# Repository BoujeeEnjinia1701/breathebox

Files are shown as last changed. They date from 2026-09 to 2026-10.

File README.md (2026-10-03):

# BreatheBox

     

**Area:** BioMedical · **TRL:** 3 of 9 (proof of concept on paper) · **Value-engineering target:** $255 USD · **Difficulty:** 3 of 5

A window-mounted heat recovery ventilator for single rooms: two small fans and a counterflow core bring in fresh air while recovering most of the heat or cool from the outgoing air.

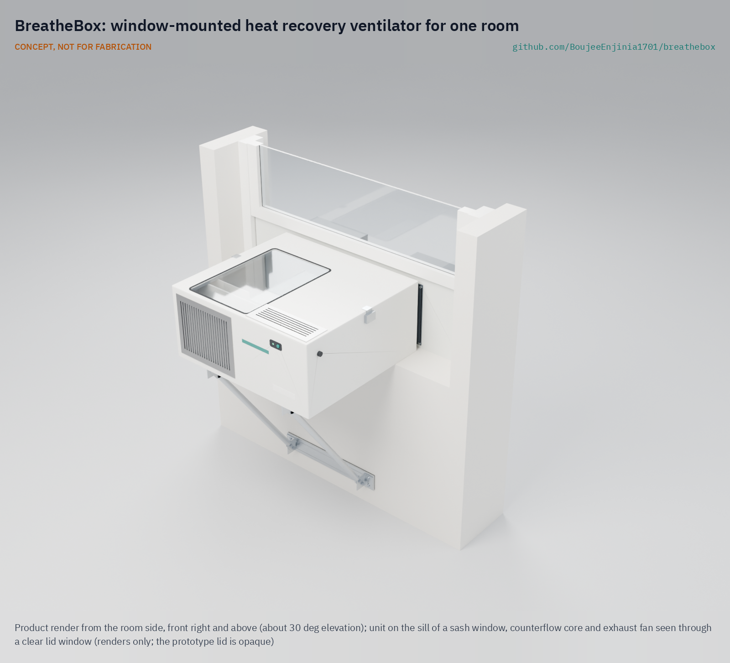
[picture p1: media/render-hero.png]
BreatheBox: window-mounted heat recovery ventilator for one room, product render


[Exploded render](media/render-exploded.png) · [Detail render](media/render-detail.png) · [Interactive 3D model](media/viewer.html) · [Concept blueprint (PDF)](media/concept-blueprint.pdf) · [General arrangement BBX-DWG-001 (PDF)](cad/drawings/BBX-DWG-001.pdf) · [Sizing calculations](docs/04-calcs/01-sizing.md) · [Prototype build plan](docs/05-build-plan.md) · [Design decisions](docs/06-design-decisions.md) · [Review note](docs/REVIEW.md)

## Concept rationale

Most homes will never get a ducted whole-house ventilation system, but almost every room has a window. BreatheBox puts heat recovery where the fresh air already comes in: a small counterflow core and two small 24 V fans in a box that sits on the sill, with an insulated panel under the raised sash. Room air and outdoor air pass each other on opposite sides of thin plates, so the room gets filtered fresh air at close to room temperature instead of a cold draft. A CO2 sensor runs the fans only as hard as the room needs.

It is open and garage-buildable because the people who most need it (renters, social housing tenants, owners of older homes) are the least served by installer-only products. Apart from the core and the fans, the parts are foam board, filter media and a small controller. The design files let a community repair group or a housing provider build, adapt and fix units locally, and the firmware keeps data on the device. It is a research and educational prototype, not a medical device.

## Burning platform

People live indoors, and indoor air is often the worse air. The US EPA notes that Americans spend about 90 % of their time indoors and that indoor concentrations of some pollutants are often 2 to 5 times higher than typical outdoor levels ([US EPA](https://www.epa.gov/report-environment/indoor-air-quality)). Opening a window is the usual fix, and it throws heat away: in the European Union, buildings use about 40 % of energy, about 80 % of energy in homes goes to heating, cooling and hot water, and 85 % of buildings were built before 2000 ([European Commission](https://energy.ec.europa.eu/topics/energy-efficiency/energy-performance-buildings/energy-performance-buildings-directive_en)).

The cost of getting this wrong is not only energy. In England, 7 % of social rented homes had a damp problem in 2023, and the death of two-year-old Awaab Ishak from prolonged mould exposure led to a law with fixed deadlines for landlords to fix damp and mould ([UK Government](https://www.gov.uk/government/news/awaabs-law-to-force-landlords-to-fix-dangerous-homes)). Outdoor air needs filtering too: 99 % of the world's population lived where WHO air quality guideline levels were not met in 2019 ([WHO](https://www.who.int/news-room/fact-sheets/detail/ambient-(outdoor)-air-quality-and-health)).

## Where it could be used

### By industry

| Industry | Use |
| --- | --- |
| Social and rental housing | Fast, reversible fix for damp and stuffy bedrooms without building work |
| Home energy retrofit | Adds controlled ventilation after air sealing and insulation of older homes |
| Student and worker residences | One unit per small room, where windows are often kept shut for noise or security |
| Small offices and consulting rooms | Fresh, filtered air for one or two people in rooms with no mechanical ventilation |
| Assisted living and home care | Steady ventilation for people who cannot easily open and close windows |
| Maker education and repair cafes | Teaching build of airflow, heat transfer and sensing with a useful result |

### By country or region

| Country or region | Why it matters there |
| --- | --- |
| Canada | Long, cold heating seasons; Health Canada sets a 1,000 ppm long-term CO2 guideline for homes and names ventilation as the main way to remove CO2 ([Health Canada](https://www.canada.ca/en/health-canada/services/publications/healthy-living/residential-indoor-air-quality-guidelines-carbon-dioxide.html)) |
| United States | Window air conditioners have made sash-window units a familiar renter fix; Americans spend about 90 % of their time indoors ([US EPA](https://www.epa.gov/report-environment/indoor-air-quality)) |
| United Kingdom | Damp and mould in 7 % of social rented homes and new legal deadlines for landlords to fix them ([UK Government](https://www.gov.uk/government/news/awaabs-law-to-force-landlords-to-fix-dangerous-homes)) |
| Germany and the wider EU | 85 % of buildings built before 2000 and 75 % with poor energy performance ([European Commission](https://energy.ec.europa.eu/topics/energy-efficiency/energy-performance-buildings/energy-performance-buildings-directive_en)); tilt-and-turn windows need a different insert |
| India | Filtered supply air for bedrooms kept shut against outdoor pollution; the WHO South-East Asia Region has among the greatest numbers of deaths from ambient air pollution ([WHO](https://www.who.int/news-room/fact-sheets/detail/ambient-(outdoor)-air-quality-and-health)); an enthalpy core would suit humid heat |
| China | Cold northern winters and polluted outdoor air in one place; the WHO Western Pacific Region also carries among the greatest numbers of those deaths ([WHO](https://www.who.int/news-room/fact-sheets/detail/ambient-(outdoor)-air-quality-and-health)) |

## What sparked the idea

The idea traces back to the Saskatchewan Conservation House, an experimental energy-efficient home built in northwest Regina in 1977 with the Saskatchewan Research Council as project manager. Its use of an air-to-air heat exchanger for ventilation was a pioneering effort, and such exchangers are now produced in the tens of thousands each year in North America ([Encyclopedia of Saskatchewan, University of Regina](https://esask.uregina.ca/entry/energy-efficient_houses.html)). That house showed that a tight, well-insulated home needs heat recovery ventilation designed in from the start. BreatheBox asks what the same exchanger looks like when it has to reach an existing room through a sash window, fitted and removed by a tenant, rather than being ducted into a new house.

## Problem

Sealed, efficient homes need ventilation, but opening windows wastes energy and whole-house heat recovery systems are expensive to retrofit.

## Concept

A window-mounted heat recovery ventilator for single rooms: two small fans and a counterflow core bring in fresh air while recovering most of the heat or cool from the outgoing air.

Full design precis: [docs/02-concept.md](docs/02-concept.md)

## Key components

1. Insulated housing that sits on the window sill
2. Counterflow plate core, about 80 % sensible recovery (estimate)
3. Two 24 V brushless blowers, 30 to 70 m³/h balanced, 50 m³/h nominal
4. ePM1 supply filter and coarse exhaust filter
5. Controller with CO2, humidity and temperature sensing, a frost mode and a quiet night mode
6. Condensate tray draining outdoors
7. Insulated window insert panel with seals, under the raised sash, which a bought no-drill sash jammer holds down
8. Two outdoor hoods with insect mesh, a sill bracket propped on the wall by a padded foot, and a certified 24 V plug-in adapter

TRL 3 calculations ([BBX-CAL-001](docs/04-calcs/01-sizing.md)): about 267 W of heat kept at 0 °C outdoors and 50 m³/h for about 5.7 W of fan and control power, about 11.8 kg installed, and $294 in parts. One requirement is not met, noise (about 39 dB(A) at 1 m at 50 m³/h against 30 dB(A)). Value-engineering target: USD 255. Estimated cost of the constructable design: USD 294 (USD 39 over the target). A quiet night mode at 32 m³/h brings the noise estimate to about 30 dB(A) with clean filters, with overnight CO2 near 1,300 ppm ([BBX-DDR-002](docs/decisions/0002-recommendations-accepted.md)). See the [design precis](docs/02-concept.md) and [requirements](docs/03-requirements.md).

The priced bill of materials is in [bom/bom.csv](bom/bom.csv). The parametric model is `cad/src/model.py`, with STEP and STL exports in `cad/step/` and `cad/stl/`.

## Building the prototype

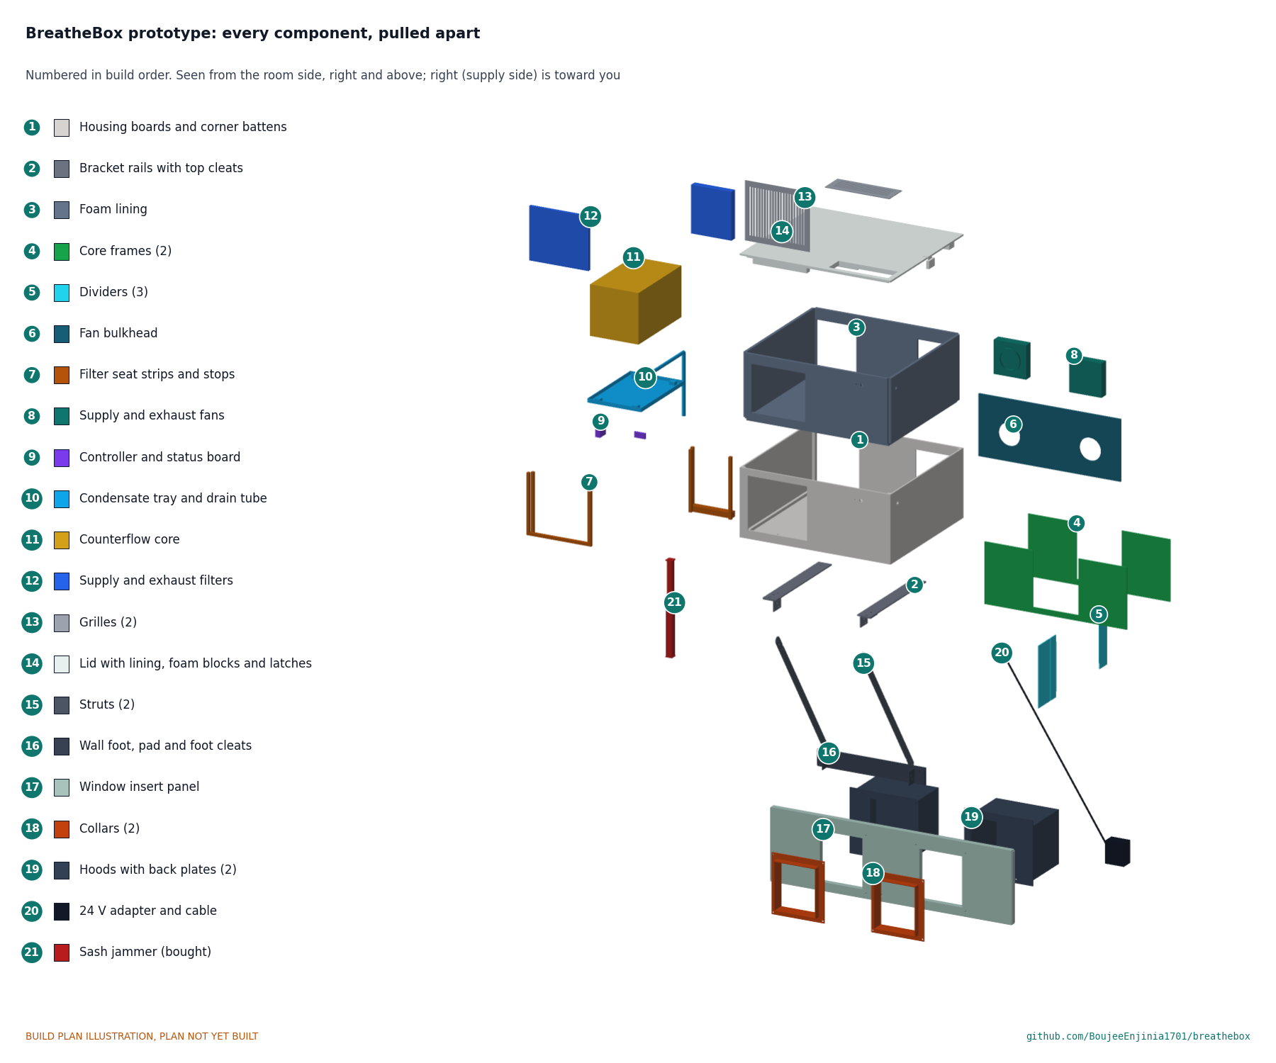
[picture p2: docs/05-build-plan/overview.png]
BreatheBox prototype: every component pulled apart and numbered in build order


The [prototype build plan](docs/05-build-plan.md) (BBX-BLD-001) shows, in pictures, how to make or buy each of the twenty-one components and put them together in sixteen steps; nothing has been built yet. The housing is PVC foam board on corner battens with a foam lining, partitions that keep the four air streams apart and a fan bulkhead; the window insert is a panel with flanged collars and hoods bolted through it; the bracket is two rails and two flattened-end struts on a padded wall foot 400 mm above the floor, and a bought sash jammer holds the raised sash down on the insert. Writing the plan made the design buildable: joints, seats, partitions, grilles and fixings were added and the bracket was made rigid (BBX-DDR-003, accepted by Amish on 2 October 2026); the decisions are recorded in the [design decisions register](docs/06-design-decisions.md). Every picture is drawn from the model, which checks that each part touches what it should and clears what it should not.

## Safety

> The unit runs on 24 V from a certified plug-in adapter; do not open the adapter or add mains wiring. Do not use it in a room with an open-flued or unflued fuel-burning appliance, because frost mode extracts more air than it supplies. Hold the raised sash down on the insert panel with the sash jammer and never install from outside above ground level. Fan impellers can cut fingers: unplug before opening the lid.
>
> BreatheBox is a research and educational prototype, not a medical device. Its CO2 reading indicates how well the room is ventilated; it is not a health or medical measurement.

## Repository layout

| Folder | Contents |
| --- | --- |
| `docs/` | Problem, concept, requirements, calculations and design decisions |
| `cad/src/` | build123d Python source, the source of truth for all geometry |
| `cad/step/`, `cad/stl/` | Exported models for FreeCAD, other CAD tools and printing |
| `cad/drawings/` | 2D sketches and dimensioned drawings |
| `bom/` | Bill of materials |
| `electronics/` | KiCad schematics and PCB layouts |
| `firmware/` | Microcontroller code |
| `media/` | Renders, perspectives and photos |
| `build-log/` | Dated prototyping notes |

## Documentation

Controlled documents follow the portfolio [documentation standard](.kit/STANDARDS.md). Each carries a document ID (BBX-PRC-001 for the precis), a version and a revision history. Branded PDFs are built with `python .kit/render.py` and attached to GitHub Releases when a document is tagged, for example `BBX-PRC-001/v1.0`.

## Credits

Designed by Amish Chadha, with contributions from Ashok Kumar Chadha and Dr. Geeti Chadha. See [CONTRIBUTORS.md](CONTRIBUTORS.md) for roles. To cite this design, use [CITATION.cff](CITATION.cff) (GitHub shows it as "Cite this repository").

AI assistance (Claude) was used to accelerate concept renders, prototype documentation and first-pass sizing calculations. Design direction and all decisions are Amish Chadha's, recorded in this repository's decision records (`docs/decisions/`).

## Licenses

- **Hardware** (CAD, drawings, BOM, electronics): [CERN-OHL-S v2](LICENSE)
- **Software** (firmware, scripts, notebooks): [MIT](LICENSE-SOFTWARE)

A project of the [Design Molecule](https://designmolecule.com) lab.

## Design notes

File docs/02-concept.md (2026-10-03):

---
doc_id: BBX-PRC-001
title: BreatheBox design precis
project: BreatheBox
doc_type: Design precis
version: "0.10"
status: Draft
date: '2026-10-02'
author: Amish Chadha
license: CERN-OHL-S-2.0
revisions:
- version: "0.1"
  date: '2026-09-25'
  author: Amish Chadha
  change: Initial scaffold
- version: "0.2"
  date: '2026-09-25'
  author: Amish Chadha
  change: Populate to TRL 2 (architecture, first-order numbers, safety, media)
- version: "0.3"
  date: '2026-09-25'
  author: Amish Chadha
  change: TRL 3 update; numbers from BBX-CAL-001, layout from the parametric model and BBX-DWG-001, larger fans, design choices adopted for TRL 3 per BBX-DDR-001 (open for Amish's review)
- version: "0.4"
  date: '2026-09-25'
  author: Amish Chadha
  change: Recommendations accepted by Amish (DDR-002)
- version: "0.5"
  date: '2026-09-26'
  author: Amish Chadha
  change: Budget approved by Amish; parts cost now within the $255 budget
- version: "0.6"
  date: '2026-09-30'
  author: Amish Chadha
  change: Design made constructable (BBX-DDR-003, open for Amish's review); components, mass, power and cost updated; build plan BBX-BLD-001 and register BBX-DEC-001 added
- version: "0.7"
  date: '2026-10-01'
  author: Amish Chadha
  change: Budget treated as a value-engineering target
- version: "0.8"
  date: '2026-10-01'
  author: Amish Chadha
  change: BioMedical area (BBX-DEC-001 v0.3); safety states a research and educational prototype, not a medical device
- version: "0.9"
  date: '2026-10-02'
  author: Amish Chadha
  change: "Fan position and sash jammer decided by Amish on 2026-10-02 (BBX-DEC-001)"
- version: "0.10"
  date: '2026-10-02'
  author: Amish Chadha
  change: "Approved follow-ups carried out: wall foot at 400 mm, sash jammer as component 14, mass 11.8 kg installed, cost USD 294 (USD 39 over the value-engineering target); drawing BBX-DWG-001 Rev P4"
---

# BreatheBox design precis

## Summary

BreatheBox is a single-room heat recovery ventilator that sits on the sill of a sash window. Two small 24 V blowers push stale room air out and draw fresh air in through a counterflow plate core, so the incoming air picks up about 80 % of the heat (or, in summer, the cool) of the outgoing air. The TRL 3 calculations (BBX-CAL-001) give, for a bedroom at 50 m³/h and 0 °C outdoors: about 267 W of heat kept in the room for about 5.7 W of fan and control power, supply air at about 16 °C, and CO2 near 980 ppm overnight with two sleepers. One requirement is not met, noise (about 39 dB(A) at 1 m at 50 m³/h against 30 dB(A)), and cost is over the value-engineering target. Value-engineering target: USD 255. Estimated cost of the constructable design: USD 294 (USD 39 over the target). A quiet night mode at 32 m³/h brings the noise estimate to about 30 dB(A) with clean filters. All figures are paper estimates; nothing has been built.

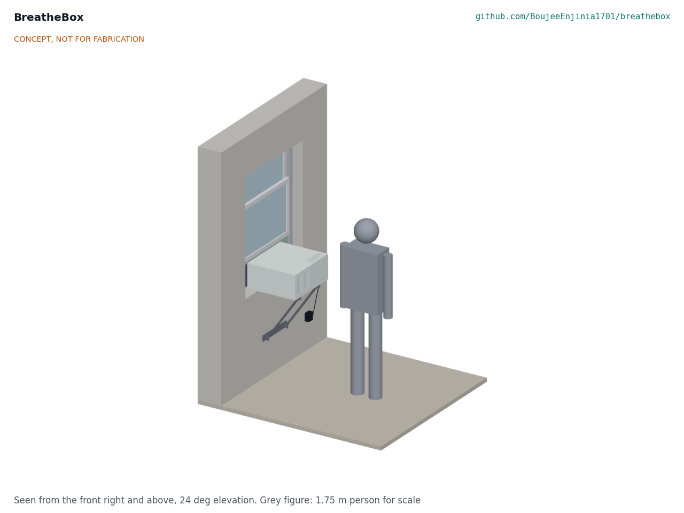
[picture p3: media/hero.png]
Hero render


Figure 1. Parametric model on a sash window, with a 1.75 m person for scale.

## How it works

1. **Mount.** A 20 mm insulated panel fills the gap under the raised lower sash, which closes down onto it and is held there by a bought no-drill sash jammer in the inner track above it. The housing (510 x 560 x 250 mm) rests 110 mm on the sill and projects 400 mm into the room, where a bracket of two rails and two struts, propped on the wall by a padded foot 400 mm above the floor, carries it; nothing is drilled.
2. **Exhaust path.** Room air enters a front grille, passes a coarse filter, and the exhaust fan blows it through one set of core channels, across the outdoor plenum and out of a downward-facing hood.
3. **Supply path.** Outdoor air enters the second hood, 420 mm from the exhaust mouth, passes through a collar in the panel and an ePM1 filter, and flows through the other set of core channels. The supply fan draws it through the core and blows it into the room through a top grille that throws air up and away from the occupant.
4. **Recover.** The two streams flow in opposite directions on each side of thin polymer plates, so heat passes across without the air mixing.
5. **Drain.** In winter, moisture from the room air condenses in the core. A tray under the core falls to the outdoor side, and a tube carries the water through the panel and down the outside wall.
6. **Control.** A small controller reads CO2, humidity and temperature at the room intake and runs the fans between 30 and 70 m³/h, using the fan tach signals to keep the two streams within 10 %. A temperature probe at the core's exhaust outlet triggers a frost mode that slows the supply fan when the cold corner of the core nears 0 °C. Readings show on a status LED and, optionally, on a local web page; nothing needs the cloud. The firmware rules accepted in BBX-DDR-002 are: a quiet night mode that holds both streams at 32 m³/h and suppresses the CO2 boost; a speed cap at what 80 m³/h needs, so the worst-case draw stays under the 36 W adapter; and frost mode taking priority over both.

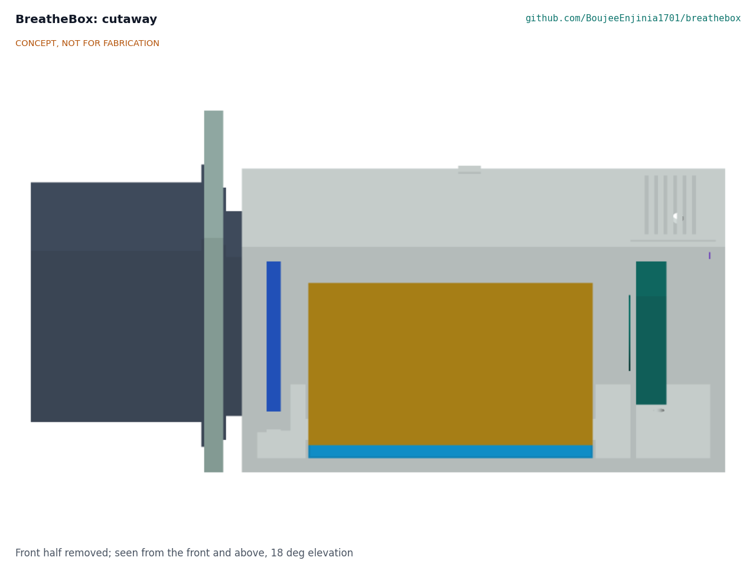
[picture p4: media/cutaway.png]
Cutaway


Figure 2. Cutaway through the supply side: hood and collar (outdoors, left), insert panel, supply filter, core over the condensate tray, supply fan and controller.

The general arrangement is drawing BBX-DWG-001 (Rev P4) in `cad/drawings/`, generated from `cad/src/model.py`. How to build the prototype, component by component, is in the build plan BBX-BLD-001 (`docs/05-build-plan.md`); BBX-DDR-003 records the changes that made the concept buildable, and the design decisions register BBX-DEC-001 (`docs/06-design-decisions.md`) records the decisions made and the items to confirm when parts are bought.

## Main components

Table 1. Main components. Numbers match `bom/bom.csv` and Figure 4.

| # | Component | Choice for TRL 3 | Notes |
| --- | --- | --- | --- |
| 1 | Insulated housing | 6 mm PVC foam board on corner battens with 10 mm foam lining, 510 x 560 x 250 mm; core frames, dividers and a fan bulkhead for the four air paths; filter seats; two slotted grilles | Lift-off lid with two latches |
| 2 | Counterflow core | Polymer plate core 180 x 180 x 300 mm, about 2.5 mm plate pitch | Bought spare-part HRV core; washable |
| 3, 4 | Supply and exhaust fans | 24 V brushless centrifugal blowers, 120 x 120 x 32 mm class, about 100 m³/h free air and 400 Pa shut-off, PWM with tach | Larger than at TRL 2 (see BBX-CAL-001 section 4) |
| 5 | Supply filter | ISO 16890 ePM1 50 % pleated panel, 150 x 170 x 25 mm, at the supply port | Replace about every 6 months or at twice the clean pressure drop |
| 6 | Exhaust filter | Coarse washable pad, 220 x 190 mm | Keeps lint off the core |
| 7 | Controller | ESP32-C3 class module with a Sensirion SCD41 class CO2, humidity and temperature sensor and two NTC probes | Check the sensor on the lab's CalRig before use |
| 8 | Condensate tray and drain | PETG tray under the core, 12 x 8 mm tube to outdoors from the tray floor | Tube falls outdoors |
| 9 | Window insert panel | 20 mm insulated panel with EPDM edge seals, trimmed to 700 to 1,000 mm | Raised sash held down on it by a bought no-drill sash jammer in the inner track (decided 2026-10-02) |
| 10 | Outdoor hoods and collars | Two PVC hoods on back plates with 1 mm stainless mesh on 130 mm wide mouths, 420 mm apart; flanged collars bolted through the panel | Mouths face down |
| 11 | Sill bracket | Two aluminium rails under the housing and two tube struts, bolted rigid, to a padded wall foot 400 mm above the floor | Props on the wall; no drilling |
| 12 | Power supply | Certified 24 V, 1.5 A plug-in adapter; 2 A fuse on the 24 V input | No mains wiring in the unit |
| 14 | Sash jammer | Bought no-drill adjustable sash jammer, wedged in the inner track between the raised sash and the window head | Holds the sash down on the panel (R12) |

## Key numbers

All values come from BBX-CAL-001 and `docs/04-calcs/sizing.py`, with the assumptions stated there. They are estimates for a paper design.

Table 2. Key numbers at TRL 3.

| Quantity | Estimate | Requirement |
| --- | --- | --- |
| Core effectiveness | 79.8 % at 50 m³/h; 73.8 % at 70 m³/h | R2 met on paper |
| Heat recovered at 0 °C outdoors, 50 m³/h | 267 W of 335 W; 68 W lost; supply air 16.0 °C | |
| Supply pressure drop at 50 m³/h | 52.3 Pa clean, 79.6 Pa with loaded filter | |
| Flow limit at full fan speed | 80 m³/h per stream with loaded filters | R1 met on paper |
| Fan and control power | 5.7 W at 50 m³/h (7.5 W loaded); 14.8 W at 70 m³/h loaded | R3 met on paper |
| Noise at 1 m | About 39 dB(A) at 50 m³/h; night mode at 32 m³/h about 30 dB(A) clean, 32 dB(A) with loaded filters | **R6 not met** (written for 50 m³/h) |
| Heating-season energy kept | About 1,123 kWh for 29 kWh of fan energy (3,500 K·d) | |
| CO2, two sleepers, 30 m³ room | 980 ppm overnight and 607 ppm 24 h mean at 50 m³/h; about 1,300 ppm overnight and 712 ppm 24 h mean in night mode | R4 met on paper |
| Condensate, upper bound | 0.21 L/h (70 m³/h, -3 °C) | R7 drain sized |
| Frost onset | About -2.2 °C outdoors at 50 m³/h | |
| Frost mode at -10 °C | Supply slowed to 33 % of exhaust; about 2.2 Pa room depressurization through a door undercut | R7 met on paper |
| Clear distance between hood mouths | 420 mm; hoods fit windows from 686 mm clear width | R11, R8 met on paper |
| Unit mass | About 11.8 kg installed, sash jammer included (12.0 kg with adapter) | R9 mass met on paper (margin 0.2 kg) |
| Parts cost | $294 | **R15 over the value-engineering target by $39** ($255 target) |

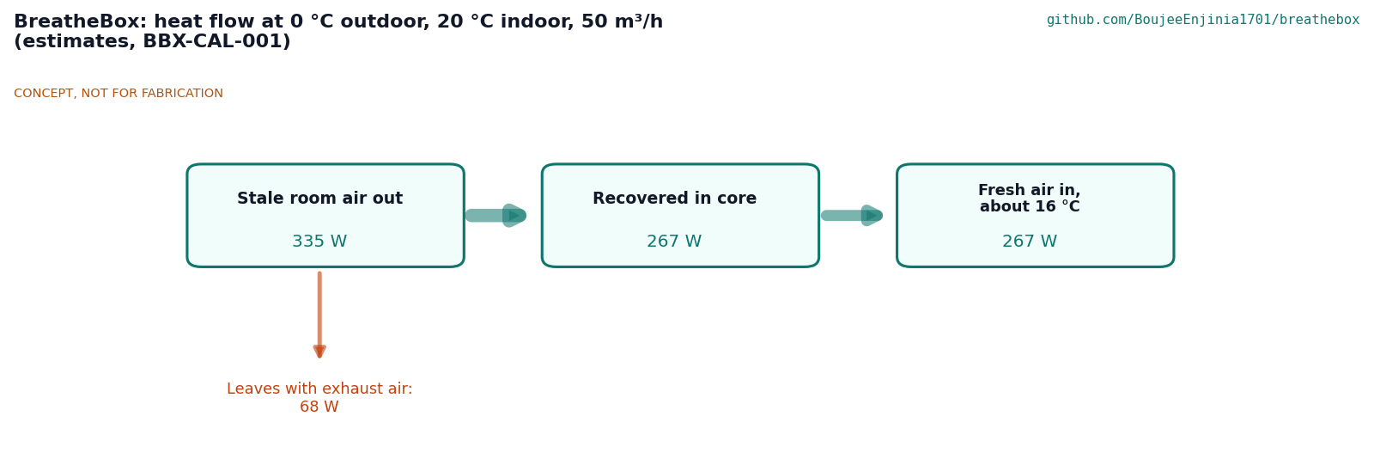
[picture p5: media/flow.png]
Heat flow


Figure 3. Heat flow in the design case (estimates from BBX-CAL-001).

## Key design choices

Each choice below was recommended at TRL 2 (BBX-DDR-001) and decided by Amish on 2026-09-25: go with recommendation (BBX-DDR-002).

- **Window insert rather than wall core; sash windows first** (item A2). Renters can install it, and it comes out without a trace. The first version fits vertical sliding sash windows from 700 to 1,000 mm clear width, with an adapter for horizontal sliders. Casement and tilt-and-turn windows need a later insert.
- **Bought polymer counterflow plate core** (item A3). A plate core runs one steady fan per stream, is simple to model and build, and keeps supply and exhaust separate. The core is the part a garage builder cannot make well; a home-made crossflow core would cost about $10 but recover only about 50 to 65 % (estimate). Alternating regenerative units and enthalpy cores remain options for later variants.
- **Frost by slowing the supply fan** (item A4). The simplest frost strategy for a 24 V unit: holding balanced flow at -10 °C with a preheater would take about 130 W. It unbalances the flows and slightly depressurizes the room (see Safety).
- **50 m³/h nominal with CO2-driven boost to 70 m³/h** (item A5). The boost is rarely needed for R4 but costs noise (about 45 dB(A) at 70 m³/h with clean filters).
- **Single ESP32-C3 class controller with an SCD41 class sensor** (item A6), with the sensor checked on CalRig.
- **Quiet night mode** (BBX-DDR-002). 32 m³/h per stream while people sleep, trading overnight CO2 (about 1,300 ppm) for about 30 dB(A). Larger, slower fans or a lined silencer section are to be checked against a real fan datasheet before R6 is changed; that check is on hold with TRL 4.
- **Larger blowers, 2 A time-delay input fuse and firmware speed cap** (BBX-DDR-002), as costed and sized in BBX-CAL-001.
- **24 V SELV only.** A certified plug-in adapter means no mains wiring for the builder (R10).

Both fans sit in the warm room-end plenum, so the exhaust side of the core runs at a slightly higher pressure than the supply side, and any core leakage would carry stale air into the supply stream. Amish decided on 2026-10-02 to keep both fans at the room end for the prototype and to add a cross-leakage check at TRL 4: a CO2 tracer in the exhaust stream, measured in the supply. The exhaust fan moves to the outdoor end only if the transfer exceeds about 3 % (BBX-DEC-001).

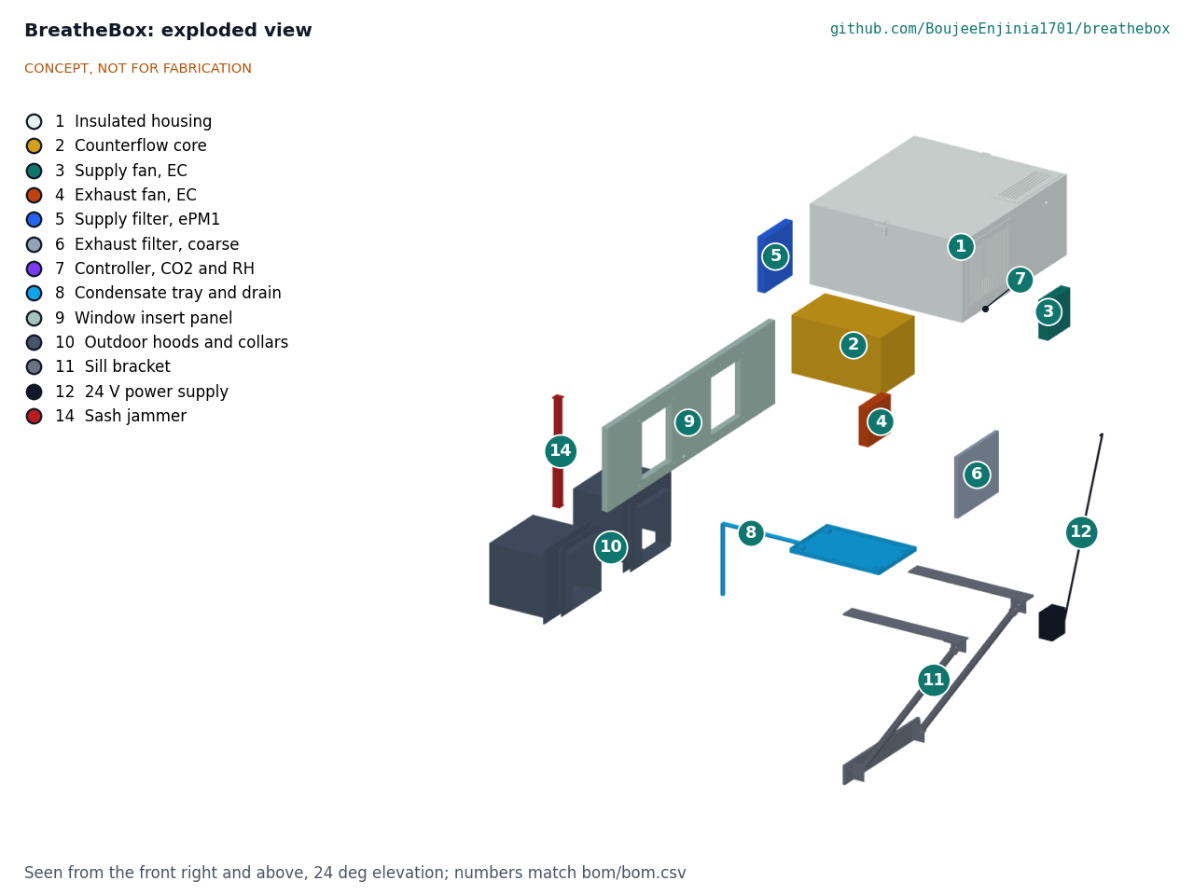
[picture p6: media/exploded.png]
Exploded view


Figure 4. Exploded view with BOM numbers.

## Safety

> **Safety:** Do not use BreatheBox in a room with an open-flued or unflued fuel-burning appliance (gas fire, oil or wood stove, water heater). In frost mode the unit extracts more air than it supplies and could draw combustion gases into the room. Do not install it in a room whose door seals airtight, because the depressurization would then be much larger than the 2 to 4 Pa estimated for a door with an undercut.

> **Safety:** The raised sash must be held down on the insert panel by the sash jammer. An unlocked sash is a security risk, and a loose panel or hood could fall outward from an upper floor. Check the bracket and panel before leaving the unit unattended, and never install from outside above ground level.

> **Safety:** Use only a certified 24 V SELV plug-in adapter, with a 2 A time-delay fuse on the low-voltage input. Do not open or modify the adapter. Keep the cable clear of the sash and of the condensate tube.

- Foam and plastics in the housing burn; choose fire-retardant grades and keep the unit away from heaters and curtains near heat sources.
- Fan impellers can cut fingers: guards or grilles on both room openings, and disconnect power before opening the lid.
- The drain tube can freeze outdoors in long cold spells; route it to fall continuously and check it in winter.
- Clean the tray and replace filters on schedule; standing water and wet filters can grow mould.
- BreatheBox is a research and educational prototype, not a medical device. The CO2 reading is a ventilation indicator only and is not a health or medical measurement.

## Open questions after TRL 3

- Noise: does a real fan datasheet, or a lined silencer, close the R6 gap at 50 m³/h, or should R6 be restated for the night mode?
- Core: which spare-part cores are available at this size, and what are their real effectiveness and pressure drop?
- Fans: the chosen blower's curve, efficiency and noise data, to replace the class values in BBX-CAL-001.
- Airtightness: how much air leaks around the insert panel and sash, and does it matter for balance?
- Window survey: what share of the first users' windows are sash, slider, casement or tilt-and-turn?

Concept media: [blueprint sheet](../media/concept-blueprint.pdf), [interactive 3D model](../media/viewer.html). General arrangement: [BBX-DWG-001](../cad/drawings/BBX-DWG-001.pdf).

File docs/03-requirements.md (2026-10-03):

---
doc_id: BBX-REQ-001
title: BreatheBox requirements
project: BreatheBox
doc_type: Requirements
version: "0.9"
status: Draft
date: '2026-10-02'
author: Amish Chadha
license: CERN-OHL-S-2.0
revisions:
- version: "0.1"
  date: '2026-09-25'
  author: Amish Chadha
  change: Initial scaffold
- version: "0.2"
  date: '2026-09-25'
  author: Amish Chadha
  change: First measurable requirements for TRL 2, with status against the concept
- version: "0.3"
  date: '2026-09-25'
  author: Amish Chadha
  change: Status against BBX-CAL-001 at TRL 3; R7 condensate figure corrected to 0.21 L/h; R8 and R15 notes per BBX-DDR-001 (adopted for TRL 3, open for Amish's review)
- version: "0.4"
  date: '2026-09-25'
  author: Amish Chadha
  change: Recommendations accepted by Amish (DDR-002)
- version: "0.5"
  date: '2026-09-26'
  author: Amish Chadha
  change: Budget approved by Amish; R15 target $255, status Not met to Met
- version: "0.6"
  date: '2026-09-30'
  author: Amish Chadha
  change: Status against the constructable design (BBX-DDR-003, BBX-CAL-001 v0.4); R15 Met to Not met at $283; R3, R9 and R10 figures updated; no target changed
- version: "0.7"
  date: '2026-10-01'
  author: Amish Chadha
  change: Budget treated as a value-engineering target
- version: "0.8"
  date: '2026-10-02'
  author: Amish Chadha
  change: "R12: sash held by a bought no-drill sash jammer, decided by Amish on 2026-10-02 (BBX-DEC-001)"
- version: "0.9"
  date: '2026-10-02'
  author: Amish Chadha
  change: "Approved follow-ups carried out (BBX-CAL-001 v0.7): sash jammer now BOM line 14 (R12); R9 mass 11.8 kg with the longer struts and the sash jammer; R15 USD 294, USD 39 over the value-engineering target; no status category and no target changed"
---

# BreatheBox requirements

These requirements are proposals for review, not yet validated with users, and will be revised after co-design (see BBX-PRB-001). Status is judged against the TRL 3 calculations in BBX-CAL-001 and the parametric model in `cad/src/model.py`; nothing has been built or measured. No target was relaxed at TRL 3. On 2026-09-25 Amish accepted the review recommendations (BBX-DDR-002): R15 read against a $250 value-engineering target (it was $220), and R4 and R6 show the quiet night mode; R6 itself is unchanged until a real fan datasheet has been checked. The R7 condensate figure was corrected from 0.15 to 0.21 L/h because the calculation showed a higher worst case. The value-engineering target was set at $255 on 2026-09-26, and the concept's priced BOM was within it. On 2026-09-30 the design was made constructable (BBX-DDR-003): the parts it needed brought the BOM to $283. On 2026-10-02 Amish's decisions added a bought sash jammer and a lower wall foot with longer struts. Value-engineering target: USD 255. Estimated cost of the constructable design: USD 294 (USD 39 over the target); BBX-DEC-001 lists the savings worth trying. No target changed.

The **design case** is a 30 m³ bedroom with two sleeping adults, 20 °C and 50 % relative humidity indoors, 0 °C outdoors, and a vertical sliding sash window with a 900 mm clear width.

Table 1. Requirements and status at TRL 3.

| ID | Requirement | Target | Status at TRL 3 (BBX-CAL-001) | Verification (TRL 4 or later) |
| --- | --- | --- | --- | --- |
| R1 | Balanced ventilation over a useful range | Supply and exhaust each adjustable from 30 to 70 m³/h (18 to 41 cfm); supply and exhaust within 10 % of each other outside frost mode | Met on paper: 80 m³/h per stream at full speed with loaded filters; balance by fan tach | Flow hood measurement |
| R2 | Recover heat from the exhaust air | Sensible effectiveness 75 % or more at 50 m³/h and balanced flow | Met on paper: 79.8 % | Temperatures on the four ports |
| R3 | Low running power | Fans and controls 12 W or less at 50 m³/h | Met on paper: 5.7 W clean, 7.5 W with loaded filters | Power meter |
| R4 | Keep bedroom air fresh | CO2 at or below 1,000 ppm (24-hour average) in the design case, following the Health Canada residential guideline | Met on paper: 607 ppm 24 h mean at 50 m³/h; 980 ppm overnight. In night mode (32 m³/h): 712 ppm 24 h mean, about 1,300 ppm overnight | CO2 logging |
| R5 | Filter the supply air | ISO 16890 ePM1 50 % or better on supply; coarse filter on exhaust to protect the core | Met by specification | Filter data sheet |
| R6 | Quiet at night | 30 dB(A) or less at 1 m from the room face at 50 m³/h | **Not met** at 50 m³/h: about 39 dB(A) (estimate). Night mode at 32 m³/h (BBX-DDR-002): about 30 dB(A) clean, 32 dB(A) with loaded filters | Sound meter |
| R7 | Handle condensate and frost | All condensate drains outdoors (up to about 0.21 L/h); runs without core blockage down to -10 °C outdoor, using a frost mode that may reduce supply flow | Met on paper: frost onset about -2.2 °C; at -10 °C the supply runs at 33 % of the exhaust | Cold-chamber or winter test |
| R8 | Fit common windows | Vertical sliding sash windows with 700 to 1,000 mm clear width and sill 150 mm or deeper; adapter panel for horizontal sliders | Met on paper for sash: the hoods need 686 mm. Casement and tilt-and-turn windows are a later variant (BBX-DDR-001 item A2, decided by Amish in BBX-DDR-002) | Fit check against a window survey |
| R9 | Renter-friendly installation | No drilling of frame or wall; one person installs or removes in 30 min or less; unit mass 12 kg or less | Not verifiable at TRL 3: mass 11.8 kg met on paper (sash jammer included; margin 0.2 kg); install time needs a trial | Timed trials |
| R10 | Electrical safety | Only 24 V SELV inside the unit, from a certified plug-in adapter; fused low-voltage input; no user-accessible mains | Met by design: 36 W adapter, 2 A fuse; worst case 35.4 W | Design review |
| R11 | Weather and outdoor air | Rain-proof downward-facing hoods; insect mesh 1.5 mm or finer; 400 mm or more between supply intake and exhaust outlet | Met on paper: 420 mm; 1 mm mesh | Spray test |
| R12 | Security and child safety | Raised sash lockable onto the insert panel; no opening wider than 100 mm through the installed unit | Met by design, unverified: largest opening 2.35 mm; the raised sash is held down on the panel by a bought no-drill sash jammer in the inner track (decided 2026-10-02; bill of materials line 14) | Design review with the sash jammer fitted |
| R13 | Serviceable | Filters changed without tools in 2 min or less; core removable for washing; all parts replaceable with a screwdriver | Not verifiable at TRL 3: lift-off lid and slide-out filters and core in the model | Timed trials |
| R14 | Local data only | CO2, humidity and temperature shown on the unit; works with no network or cloud account; optional local logging | Not verifiable at TRL 3: no firmware yet | Firmware review |
| R15 | Affordable | Prototype parts at or under the $255 value-engineering target (a hypothetical control target; was $250, and $220 before that; BBX-DDR-002) | **Over the value-engineering target by $39:** $294 (priced BOM of the constructable design, BBX-DDR-003, with the sash jammer) | Priced BOM (`bom/bom.csv`) |

## Requirements not met

- **R6 (noise) not met:** about 39 dB(A) at 1 m at 50 m³/h against 30 dB(A). The accepted night mode (32 m³/h) gives about 30 dB(A) with clean filters and 32 dB(A) with loaded filters; larger, slower fans or a silencer are to be checked against a real fan datasheet (on hold with TRL 4) before any change to R6.
- **R15 (cost) over the value-engineering target by $39:** Value-engineering target: USD 255. Estimated cost of the constructable design: USD 294 (USD 39 over the target). The target is `budget_usd` in `project.yaml`, set on 2026-09-26 (BBX-DDR-002). The constructable design added partitions, filter seats, grilles, latches, flanges, bracket parts and bolts that the concept needed but did not list (BBX-DDR-003); the 2026-10-02 decisions added the sash jammer ($10) and longer struts ($1). The savings worth trying are in the design decisions register (BBX-DEC-001).
- **Not verifiable at TRL 3:** R9 (install time), R13 (filter change time) and R14 (firmware).

## Assumptions

- Air density 1.2 kg/m³ and specific heat 1,005 J/(kg·K).
- CO2 generation about 0.014 m³/h per sleeping adult (estimate); outdoor CO2 about 420 ppm.
- Core, filter, fan and noise values are class values stated in BBX-CAL-001 section 1, not datasheet values.

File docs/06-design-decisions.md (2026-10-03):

---
doc_id: BBX-DEC-001
title: BreatheBox design decisions register
project: BreatheBox
doc_type: Design decisions register
version: "0.5"
status: Draft
date: '2026-10-02'
author: Amish Chadha
license: CERN-OHL-S-2.0
revisions:
  - version: "0.1"
    date: '2026-09-30'
    author: Amish Chadha
    change: Register opened with the open decisions from REVIEW.md, BBX-DDR-002 and BBX-DDR-003
  - version: "0.2"
    date: '2026-10-01'
    author: Amish Chadha
    change: Budget treated as a value-engineering target
  - version: "0.3"
    date: '2026-10-01'
    author: Amish Chadha
    change: Dr. Geeti Chadha added as a contributor and the project moved to the BioMedical (healthcare) area (decided by Amish)
  - version: "0.4"
    date: '2026-10-02'
    author: Amish Chadha
    change: "Amish approved the recommendations for all eight open decisions (BBX-DDR-003 accepted); moved to decisions made; To confirm items 4 and 5 and the value engineering note updated for the 400 mm foot and the sash jammer"
  - version: "0.5"
    date: '2026-10-02'
    author: Amish Chadha
    change: "Approved follow-ups carried out: value engineering estimate USD 294 with the sash jammer (BOM line 14) and longer struts; To confirm item 5 restated with the 400 mm foot figures"
---

# BreatheBox design decisions register

Every design decision still to be made, and every decision made, in one place. Each decision is argued in full in its decision record under `docs/decisions/` or in `docs/REVIEW.md`; this register is the index Amish works from. The build plan (`docs/05-build-plan.md`) describes the design as it stands and does not list open decisions.

## Open decisions

None. All open decisions were decided on 2026-10-02.

## To confirm when parts are bought

*Table 1. Items to confirm when parts are bought or the trial window is chosen.*

| # | What to confirm | Why it matters | Source |
| --- | --- | --- | --- |
| 1 | The counterflow core's ends are each split into two halves along a centre line, one per air stream, and it is 180 x 180 x 300 mm | The core frames' U and the dividers' tongues are made for that port layout; a hexagonal core with side ports needs different frames | BBX-DDR-003, P2 |
| 2 | The blowers' inlet ring is 80 mm across or less, their mounting holes, and that the supply fan's outlet can face up toward the lid grille | Sets the bulkhead holes and fan mounting; the calculations use class values for the fan curve and noise | BBX-DDR-003, P3; BBX-CAL-001 section 11 |
| 3 | The supply filter is 150 x 170 x 25 mm with a frame at least 5 mm wide; the exhaust pad is 220 x 190 x 12 mm | The lining lips seal on the filter frame and the pad edge | BBX-DDR-003, P5 |
| 4 | The trial window's sill is at least 110 mm deep, its stop bead fits the 17 mm gap between the housing and the collar flange, and the wall below is clear for the foot about 370 to 430 mm above the floor (no radiator or skirting); the foot goes back to 500 mm only where the lower foot is blocked and the push test passes on that sill | Sets the collar length and whether the bracket fits; the first prototype has its foot at 400 mm (decided 2026-10-02) | BBX-DDR-003, P8, P9 and A2 |
| 5 | The anti-slip tape grips the trial sill's finish with friction of about 0.6 or more | The unit needs 0.32 with the foot at 400 mm (margin about 1.9 on anti-slip tape) and 0.40 if the foot goes back to 500 mm (margin about 1.5); the 50 N push test at the trial window decides | BBX-DDR-003, A2 |
| 6 | The toggle latches fit 6 mm board, and the latch screws can be backed by nuts inside | Lid fixing | BBX-DDR-003, P1 |

## Value engineering

Value-engineering target: USD 255 (a hypothetical control target, not a limit). Estimated cost of the constructable design: USD 294 (USD 39 over the target). Main cost drivers and savings worth trying:

- The largest lines are the counterflow core (USD 48), the insulated housing (USD 42), the controller with CO2 and humidity sensing (USD 42), the outdoor hoods and collars (USD 26), the window insert panel (USD 20) and the two fans (USD 19 each).
- The concept's bill of materials was USD 255. The rise came from parts the concept needed but did not list (BBX-DDR-003): partitions, filter seats, grilles and latches (USD 18), hood back plates and collar flanges (USD 2), the bracket's rails, cleats and foot (USD 4), and bolts, gland and anti-slip tape (USD 4).
- The 2026-10-02 decisions added USD 11: the bought sash jammer (line 14, USD 10) and longer struts for the 400 mm foot (line 11, USD 1).
- Savings worth trying: printed grilles and a cheaper core, at some cost in performance.

## Decisions made

*Table 2. Decisions made by Amish.*

| Date | Decision | Decided by | Record |
| --- | --- | --- | --- |
| 2026-09-25 | TRL 2 items A1 to A6: budget raised, sash windows first, bought polymer counterflow core, frost by slowing the supply fan, 50 m³/h nominal with boost to 70 m³/h, ESP32-C3 class controller with an SCD41 class sensor | Amish: "i accept all your recommendations, go with them across all repos." | BBX-DDR-001, BBX-DDR-002 |
| 2026-09-25 | Noise (R6): quiet night mode at 32 m³/h, plus larger slower fans or a lined silencer checked against a real datasheet before any change to R6 (on hold with TRL 4) | Amish, same instruction | BBX-DDR-002, item 7 |
| 2026-09-25 | Larger blowers (about 100 m³/h free air, 400 Pa); 2 A time-delay input fuse; firmware fan speed cap; no use in a room whose door seals airtight | Amish, same instruction | BBX-DDR-002, items 8 to 11 |
| 2026-09-25 | Check the CO2 sensor on the lab's CalRig before use (on hold with TRL 4) | Amish, same instruction | BBX-DDR-002, item 6 |
| 2026-09-26 | Budget set to $255 to cover the concept's priced BOM | Amish: "i approve all the budget items." | BBX-DDR-002 v0.2 |
| 2026-09-30 | Build plans in the approved format, with outstanding decisions kept in this separate register, not in the build plan | Amish: "this is the correct build plan ... Extend this across all the other repos"; "don't log outstanding decisions in this build plan" | BBX-BLD-001; this register |
| 2026-09-30 | Where the concept cannot be built, fix the design assumptions so it is physically feasible (instruction; the resulting changes were accepted on 2026-10-02, below) | Amish: "If you are realising that the design cannot be built as per concept - fix the design assumptions to match and be physically feasible as you draw the illustrations." | BBX-DDR-003 |
| 2026-10-01 | Dr. Geeti Chadha added as a contributor (CONTRIBUTORS.md, README Credits) and the project moved to the BioMedical (healthcare) area, with soft, non-clinical wording: a research and educational prototype, not a medical device | Amish: "yes add Dr. Geeti Chadha to breathebox and dustbadge and make those both healthcare projects" | `project.yaml`, `CONTRIBUTORS.md`, `README.md`, BBX-PRB-001 v0.7, BBX-PRC-001 v0.8 |
| 2026-10-02 | Design for construction accepted: the changes P1 to P12 as made, with the cost rise they bring (open item 1) | Amish: "i approve your recommendations for all 555 open decisions." | BBX-DDR-003, P1 to P12 |
| 2026-10-02 | Sliding restraint: the first prototype is built with the wall foot at 400 mm (option b, margin about 1.9) and the 50 N push test is run at the trial window; the foot goes back to 500 mm only where a radiator or skirting blocks the lower foot and the push test passes on that sill (open item 2) | Amish: "i approve your recommendations for all 555 open decisions." | BBX-DDR-003, A2 |
| 2026-10-02 | Sash lock (R12): a bought no-drill sash jammer or adjustable security bar in the inner track above the raised sash is added to the bill of materials (option a, about USD 10) (open item 3) | Amish: "i approve your recommendations for all 555 open decisions." | BBX-DDR-003, A3 |
| 2026-10-02 | Fan position: both fans stay at the room end for the prototype; a cross-leakage check (CO2 tracer in the exhaust stream, measured in the supply) is added at TRL 4, and the exhaust fan moves to the outdoor end only if transfer exceeds about 3 % (open item 4) | Amish: "i approve your recommendations for all 555 open decisions." | BBX-DDR-002, O4 |
| 2026-10-02 | First region Canada, with a tenant organization in a city with older double-hung rental stock and cold winters; first candidate to approach ACORN Canada in Toronto, with ACORN in the United Kingdom as the alternative (open item 5) | Amish: "i approve your recommendations for all 555 open decisions." | BBX-DDR-001 and BBX-DDR-002, O1 |
| 2026-10-02 | Status light and button on the room face, as the build plan already has them (open item 6) | Amish: "i approve your recommendations for all 555 open decisions." | REVIEW.md, 2026-09-26, item 2 |
| 2026-10-02 | Clear lid window in the renders only; the prototype has an opaque lid, and a clear lid is decided at TRL 4 once its cost and flame rating are priced (open item 7) | Amish: "i approve your recommendations for all 555 open decisions." | REVIEW.md, 2026-09-26, item 1 |
| 2026-10-02 | Lid: the top board with two toggle latches, as built; the appearance model is updated to match (open item 8) | Amish: "i approve your recommendations for all 555 open decisions." | REVIEW.md, 2026-09-26, item 3; BBX-DDR-003, P1 |

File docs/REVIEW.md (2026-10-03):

# Review note: BreatheBox

## Session 2026-09-25: /populate to a strong TRL 2

### What was done

- `docs/01-problem.md` (BBX-PRB-001 v0.2): problem, why it matters (cited), users, operating context, constraints, out of scope, prior work, open questions. There was no co-design checklist to keep.
- `docs/03-requirements.md` (BBX-REQ-001 v0.2): 15 measurable requirements (R1 to R15) with targets, a defined design case, a status column and assumptions.
- `docs/02-concept.md` (BBX-PRC-001 v0.2): how it works, numbered components, first-order numbers with assumptions, design choices, safety section, open questions.
- `cad/src/concept_media.py`: massing model of a sash window in a 250 mm wall with the unit on the sill (12 numbered parts); key figures and flow labels updated.
- `media/`: hero with a 1.75 m person, blueprint sheet (PNG, PDF, SVG), `model.glb` and `viewer.html`, exploded view with callouts 1 to 12, cutaway through the supply side, heat flow diagram (estimates). Temporary `media/_views*` folders removed.
- `bom/bom.csv` (13 rows, rows 1 to 12 match the exploded view) and `bom/bom-notes.md`.
- `README.md`: hero and links line; Concept rationale, Burning platform, Where it could be used, What sparked the idea expanded with cited figures; Key components and Safety updated (the old note about mains wiring no longer applied).
- `docs/pdf/`: branded PDFs rebuilt.

### Key results (estimates, to be checked at TRL 3)

| Quantity | Estimate | Requirement |
| --- | --- | --- |
| Airflow | 30 to 70 m³/h, 50 m³/h nominal (proposed) | R1 at risk (fan operating point) |
| Sensible recovery | about 80 % at 50 m³/h | R2 met on paper (75 %) |
| Heat kept at 0 °C out, 20 °C in | about 268 W of 335 W | |
| Supply air at 0 °C outdoors | about 16 °C | |
| Fans and controls | about 9.5 W | R3 met on paper (12 W) |
| Season energy kept (3,500 K·d assumed) | about 1,100 kWh, for about 50 kWh of fan energy | |
| CO2, two sleepers, 30 m³ room | about 980 ppm at 50 m³/h, about 820 ppm at 70 m³/h | R4 marginal at 50, met at 70 |
| Condensate, upper bound | about 0.14 L/h | R7 drain sized |
| Frost onset | around -5 °C outdoors | R7 at risk |
| Mass | about 10 kg | R9 met on paper |
| Parts cost | about $243 | **R15 not met** ($220) |

Requirements not met or at risk:

- **R15 (cost) not met:** about $243 against $220 (about 10 % over).
- **R8 (fit) not met** for casement and tilt-and-turn windows; the concept covers sash and slider windows only.
- **R1, R6, R7 at risk:** fan operating point, night noise (30 dB(A) at 1 m) and frost behavior are unverified.
- **R4 marginal:** two sleepers need the 70 m³/h boost to stay under 1,000 ppm, which makes R6 harder.

### Proposed, awaiting Amish (status updated 2026-09-25)

1. **Budget.** Options: (a) raise `budget_usd` from $220 to $250; (b) keep $220 by using a home-made crossflow core (about $10, but only about 50 to 65 % recovery, which fails R2); (c) keep $220 by dropping the CO2 sensor for humidity-only control (about $20 saved, weakens R4). Recommendation: (a). **Decided by Amish, 2026-09-25: go with recommendation** (BBX-DDR-002). `budget_usd` is now $250.
2. **Window type for the first version:** vertical sliding sash (recommended) versus a tilt-and-turn insert for continental Europe. **Decided by Amish, 2026-09-25: go with recommendation** (BBX-DDR-002).
3. **Core type:** bought polymer counterflow plate core (recommended) versus alternating regenerative units or an enthalpy core for humid climates. **Decided by Amish, 2026-09-25: go with recommendation** (BBX-DDR-002).
4. **Frost strategy:** slow the supply fan (recommended, with the combustion-appliance warning) versus a low-power preheater. **Decided by Amish, 2026-09-25: go with recommendation** (BBX-DDR-002).
5. **Nominal airflow:** 50 m³/h with CO2-driven boost to 70 m³/h (recommended) versus 70 m³/h fixed. **Decided by Amish, 2026-09-25: go with recommendation** (BBX-DDR-002).
6. **Controller:** single ESP32-C3 class module with an SCD41 class sensor (recommended), with sensor checks on CalRig. **Decided by Amish, 2026-09-25: go with recommendation** (BBX-DDR-002). The CalRig check is on hold with TRL 4.
7. **First co-design partner and region** (for example a tenants' group or social landlord in the UK or Canada). Still proposed, awaiting Amish (no recommendation).

No change to `project.yaml` pitch or problem: the numbers found support "recovering most of the heat".

### Safety concerns

- Depressurization in frost mode could draw combustion gases from open-flued or unflued appliances; the unit must not be used in such rooms.
- Window security and falling parts: the sash must be locked onto the panel; loose panels or hoods could fall from upper floors.
- Low-voltage only, from a certified adapter; fused input. Foam and plastic housing is combustible; fire-retardant grades proposed.
- Fan impellers (finger guards), and mould growth in a neglected tray or filter.

### Notes and gaps

- Several sources could not be fetched this session (US DOE, EU ecodesign regulation text, LUNOS product data), so no efficiency limits from regulations or competitor specifications are quoted. The claim that no open-source window HRV exists rests on a limited search.
- The legacy `cad/src/model.py` placeholder is untouched (TRL 3 work).

### Recommended next step

Review this note and the media, then decide items 1 to 3. If approved, run `/advance-trl3` to check the fan operating point, pressure drop, noise, frost and condensate estimates by calculation and produce the parametric model and drawing sheet.

## Session 2026-09-25: TRL 3

Amish's instruction for this batch (2026-09-25): "you know the drill, nothing gets past TRL 3". He did not review this repo's TRL 2 items one by one, so the recommendations were adopted for TRL 3 work, open for his review. Nothing here is recorded as decided or approved by him.

### What was done

- `docs/decisions/0001-trl2-review-decisions.md` (BBX-DDR-001 v0.1): items A1 to A6 adopted as recommended for TRL 3 under Amish's 2026-09-25 instruction, open for his review; O1 (co-design partner) stays "Proposed, awaiting Amish"; O2 (noise) and O3 (budget figure) added as open.
- `docs/04-calcs/01-sizing.md` (BBX-CAL-001 v0.1), `docs/04-calcs/sizing.py` and `docs/04-calcs/results.csv`: core effectiveness from plate geometry, pressure drop per stream, fan operating points, power, noise, heat recovery, condensate, frost onset and frost mode, room depressurization, CO2, geometry, bracket load, mass and cost, with a results table for R1 to R15. The script imports `cad/src/model.py` and reads `bom/bom.csv` and `project.yaml`.
- `cad/src/model.py`: parametric build123d model (massing plus: housing with dividers, ports and grilles; core; blowers; filters; controller; tray and drain; insert panel; hoods with offset mouths and collars; sill bracket; adapter). Exports `cad/step/` and `cad/stl/` for `breathebox-assembly`, `-housing`, `-core`, `-insert-panel`, `-hoods` and `-sill-bracket`. The built-in clash check finds no overlaps (the TRL 2 massing had ducts running through the panel).
- `cad/src/sheets.py` and `cad/drawings/BBX-DWG-001.svg`, `.pdf`, `.png`: general arrangement, Rev P1, marked "CONCEPT, NOT FOR FABRICATION" and "PRELIMINARY, NOT FOR FABRICATION". The concept blueprint keeps BBX-DWG-010. `cad/drawings/.gitkeep` removed.
- `bom/bom.csv` (13 lines, all priced with a supplier or supplier type; $255.00) and `bom/bom-notes.md`.
- `cad/src/concept_media.py` now builds from `model.py`; all media refreshed and checked by eye (`hero`, `cutaway`, `exploded`, `flow`, `concept-blueprint` PNG, PDF and SVG, `model.glb`, `viewer.html`). The exploded callout for the supply filter was moved so it is no longer hidden behind the housing. Temporary `media/_views*` folders deleted.
- BBX-PRB-001, BBX-PRC-001 and BBX-REQ-001 bumped to v0.3 (numbers from BBX-CAL-001; design choices shown as adopted for TRL 3, open for review; R7 condensate figure corrected to 0.21 L/h; no target relaxed). `README.md`: TRL badge and line, links to the drawing and calculations, key components and performance paragraph; the required sections are unchanged in wording and order, as none of their numbers changed. `project.yaml`: `trl: 3`, `trl_target: 3`, evidence listed; pitch, problem and `budget_usd` unchanged.

### Requirement status (BBX-CAL-001, Table 8)

Met 10, not met 2, at risk 0, not verifiable at TRL 3 3.

- **Not met: R6 (noise).** About 39 dB(A) at 1 m at 50 m³/h against 30 dB(A); 30 dB(A) is reached only near 32 m³/h. The figure rests on an assumed fan noise class value and is uncertain by several decibels, but not by 9.
- **Not met: R15 (cost).** $255 against $220 in `project.yaml`, and $5 over the $250 recommended at TRL 2.
- **Not verifiable at TRL 3:** R9 (install time; mass 10.5 kg met on paper), R13 (filter change time), R14 (firmware).
- **Met:** R1 (80 m³/h per stream at full speed with loaded filters), R2 (79.8 %), R3 (5.6 W clean, 7.4 W loaded), R4 (607 ppm 24 h mean, 980 ppm overnight), R5, R7 (frost mode holds to -10 °C with the supply at 33 % of exhaust), R8 (sash; hoods need 686 mm), R10, R11 (420 mm), R12.

TRL 2 numbers corrected by the calculations: fan specification raised from about 60 to about 100 m³/h free air (the TRL 2 fan could not reach 70 m³/h at all); frost onset about -2.2 °C, not -5 °C; worst condensate 0.21 L/h, not 0.14 L/h; power 5.6 W, not 9.5 W; season fan energy 28 kWh, not 50 kWh; mass 10.5 kg installed, not 10 kg; cost $255, not $243. Heat recovered (267 W) and CO2 (980 ppm, 820 ppm) confirm the TRL 2 estimates.

### Decisions recorded (BBX-DDR-001)

Each adopted as recommended for TRL 3 under Amish's 2026-09-25 instruction, open for his review, and since **decided by Amish, 2026-09-25: go with recommendation** (BBX-DDR-002): A1 budget rise to $250 (recorded only; `budget_usd` stays $220), A2 sash windows first, A3 bought polymer counterflow core, A4 frost by slowing the supply fan, A5 50 m³/h nominal with boost to 70 m³/h, A6 ESP32-C3 class controller with an SCD41 class sensor checked on CalRig.

### Still awaiting Amish (status updated 2026-09-25)

1. **Budget figure (O3).** $220 in `project.yaml`; $250 recommended; design now $255. Options: accept about $255; save about $8 with smaller blowers, which would drop the 70 m³/h boost (R1); or find $5 elsewhere. No recommendation beyond noting that the fan change is what made R1 feasible. Still proposed, awaiting Amish; `budget_usd` is now $250 under A1. **Decided by Amish, 2026-09-26: budget set to $255** (BBX-DDR-002).
2. **Noise, R6 (O2).** Options: (a) a quiet night mode near 30 to 32 m³/h, which still meets R4 as written (24 h mean about 730 ppm) but lets the room run near 1,350 ppm overnight; (b) larger, slower fans or a lined silencer section, at extra cost and size; (c) relax R6 to about 35 dB(A). Recommendation: (a) plus (b) checked against a real fan datasheet before any change to R6. **Decided by Amish, 2026-09-25: go with recommendation** (BBX-DDR-002). Night mode added; the datasheet check is on hold with TRL 4.
3. **First co-design partner and region (O1).** No recommendation. Still proposed, awaiting Amish.
4. **Engineering proposals made in this session**, awaiting confirmation: the larger blowers (about 100 m³/h free air, 400 Pa), the 2 A time-delay input fuse, a firmware fan speed cap at the 80 m³/h need (the worst case of 35.4 W sits just under the 36 W adapter), and the install restriction for rooms whose door seals airtight. **Decided by Amish, 2026-09-25: go with recommendation** (BBX-DDR-002).
5. **Fan position (review point).** Both fans sit in the room-end plenum, so the exhaust side of the core runs at higher pressure than the supply side and any core leakage would reach the supply. Options: keep it (warm, dry, serviceable fans) or move the exhaust fan to the outdoor end (cold, wet air). No change made. No recommendation, so still proposed, awaiting Amish (BBX-DDR-002 item O4).

### Cross-repo notes

- BreatheBox depends on CalRig for the CO2 sensor check. CalRig's R9 (CO2 span 400 to 2,000 ppm against a ±(30 ppm + 3 %) reference) covers the 1,000 ppm range needed, and an SCD41 class breakout fits CalRig's 90 x 70 x 50 mm bay (R10). No conflict found; CalRig was not edited.
- No other shared component (FieldNode, CellGuard, MotionCore, ThermaCart, TwinKit) is used.

### Safety concerns

- Frost mode depressurizes the room: about 2.2 Pa at 50 m³/h and 4.4 Pa at 70 m³/h through an 800 x 10 mm door undercut, under a 5 Pa screening limit (an assumption to check against local code), but much more in a room whose door seals. The combustion-appliance restriction stays and an airtight-room restriction is added.
- Window security and falling parts from upper floors, as at TRL 2.
- 24 V SELV only; the worst-case load is close to the 36 W adapter rating, so the speed cap and the 2 A fuse matter.
- The drain tube can freeze outdoors; combustible foam and plastics; fan impellers; mould in a neglected tray or filter.

### Gaps and notes

- Citations: the LUNOS page was fetched with WebFetch on 2026-09-25. It confirms the e² as one of the smallest decentralized fans but not its installation method, so BBX-PRB-001 now says so instead of claiming cored wall holes. The US DOE and EU ecodesign sources flagged at TRL 2 were not cited in the documents, so nothing further was checked. WebSearch was not available. The claim that no open-source window HRV exists still rests on a limited search.
- Fan curves, fan noise, filter resistance and core data are class values, not datasheet values; BBX-CAL-001 section 11 lists the limits.
- The kit's cutaway cuts at the mean Y of the parts and keeps the +Y (supply) half; this shows the hood, panel, supply filter, core, tray, supply fan and controller, so it was kept as is.
- No TRL 4 material exists in the repo (`firmware/` and `electronics/` are empty; `build-log/README.md` is the stock header only).

### Recommended next step

Review BBX-DDR-001 and the items above, especially the budget figure and the R6 noise options. TRL 4 is on hold by Amish's instruction; nothing further should be done until he lifts it. For the record, TRL 4 would need a built unit, chosen fan and core datasheets, a lab test report (TST, `environment: lab`) covering flow and balance, pressure drop, power, noise at 1 m, effectiveness, condensate and a cold-chamber frost run, and build log entries.

## Session 2026-09-25: recommendations accepted

Amish wrote on 2026-09-25: "i accept all your recommendations, go with them across all repos." Every item with a recommendation is now **Decided by Amish, 2026-09-25: go with recommendation**. Items without one stay proposed, awaiting Amish.

### Decisions applied and what changed

Recorded in `docs/decisions/0002-recommendations-accepted.md` (BBX-DDR-002 v0.1); BBX-DDR-001 moves to v0.2 with its status column updated. Eleven items decided:

- **Budget (A1):** `budget_usd` $220 to **$250** in `project.yaml`; R15 target $220 to $250. BOM unchanged at $255, so R15 is still not met, now by $5 instead of $35.
- **Noise (O2), option (a) plus (b):** quiet night mode as a firmware rule, both streams held at **32 m³/h** with the CO2 boost suppressed. Noise at 1 m: 38.6 dB(A) at 50 m³/h (clean) becomes **30.1 dB(A)** clean and **32.0 dB(A)** loaded in night mode. CO2 overnight 980 ppm becomes about **1,295 ppm** in night mode; 24 h mean 607 ppm becomes 712 ppm (bounding case), still under R4's 1,000 ppm. Fan and control power 5.6 W becomes 2.8 W. R6 target unchanged; option (b) (fan datasheet, silencer) is on hold with TRL 4.
- **Engineering proposals from TRL 3:** larger blowers, 2 A time-delay fuse, firmware speed cap at the 80 m³/h need (now a stated firmware rule) and the airtight-room install restriction, all kept.
- **A2 to A6:** sash first, bought counterflow core, slowed-fan frost mode, 50 m³/h nominal with 70 m³/h boost, ESP32-C3 plus SCD41 class controller. Wording updated; the design already followed them.

Files changed: `project.yaml`, `README.md` (budget line, performance paragraph, key components, new "What sparked the idea", footer), BBX-PRB-001 v0.4, BBX-PRC-001 v0.4, BBX-REQ-001 v0.4, BBX-CAL-001 v0.2 (`sizing.py` and `results.csv` rerun), BBX-DDR-001 v0.2, BBX-DDR-002 v0.1, `bom/bom-notes.md`, `cad/src/sheets.py` (BBX-DWG-001 Rev P1 to **P2**, note "Flow 30 to 70 m3/h per stream, 50 nominal, 32 night mode"), `cad/src/concept_media.py` (key figures). Geometry and BOM are unchanged; STEP, STL, drawings, media and PDFs were regenerated, which also removes the old site address from every generated file. Temporary `media/_views*` folders deleted.

### Requirement status (BBX-CAL-001 v0.2)

Met 10, not met 2, not verifiable at TRL 3 3.

- **Not met: R6 (noise).** 39 dB(A) at 50 m³/h against 30 dB(A). Night mode reaches 30 dB(A) with clean filters and 32 dB(A) with loaded ones.
- **Not met: R15 (cost).** $255 against $250.
- **Not verifiable at TRL 3:** R9 (install time), R13 (filter change time), R14 (firmware).
- **Met:** R1, R2, R3, R4 (also in night mode), R5, R7, R8 (sash), R10, R11, R12.

### Still awaiting Amish

1. **First co-design partner and region (O1).** No recommendation.
2. **Budget gap (O3).** $255 against $250: accept, drop the boost with smaller blowers, or find $5. No recommendation. **Decided by Amish, 2026-09-26: budget set to $255** (BBX-DDR-002).
3. **Fan position (O4).** Both fans in the room-end plenum or exhaust fan at the outdoor end. No recommendation.

### Cross-repo actions

- **CalRig:** check the SCD41 class CO2 sensor on CalRig before use (decided under A6). This is TRL 4 work and on hold. CalRig was not edited.

### Write-up

"What sparked the idea" in `README.md` now traces the concept to the Saskatchewan Conservation House (Regina, 1977) and its pioneering air-to-air heat exchanger, cited to the Encyclopedia of Saskatchewan (University of Regina). The earlier text about a review of the lab's research areas and the footer line about the portfolio set were removed. `docs/01-problem.md` did not attribute the idea to a review.

### TRL

`trl: 3` and `trl_target: 3` are unchanged. TRL 4 remains on hold by Amish's instruction: no build, test, purchase, PCB or firmware was started. The decided items that need TRL 4 work (CalRig sensor check, fan datasheet and silencer check for R6) are on hold.

## Session 2026-09-26: budget approved

Amish wrote on 2026-09-26: "i approve all the budget items." Budget set to $255 to cover the priced BOM: decided by Amish, 2026-09-26. This closes O3.

- `project.yaml` `budget_usd` $250 to **$255**. The priced BOM is unchanged at $255.00 (13 lines).
- R15 (cost): target $250 to $255; status **Not met to Met**. Requirement status is now met 11, not met 1 (R6 noise), not verifiable at TRL 3 3 (R9, R13, R14).
- Files changed: `project.yaml`, `README.md`, BBX-PRB-001 v0.5, BBX-PRC-001 v0.5, BBX-REQ-001 v0.5, BBX-CAL-001 v0.3 (`sizing.py` and `results.csv` rerun), BBX-DDR-001 v0.3 (O3 row), BBX-DDR-002 v0.2, `bom/bom-notes.md`, `cad/src/concept_media.py` (blueprint key figure); media and PDFs regenerated, temporary `media/_views*` folders deleted.
- Still awaiting Amish: O1 (co-design partner) and O4 (fan position). `trl: 3` and `trl_target: 3` are unchanged; TRL 4 remains on hold.

## Session 2026-09-26: product appearance model and photoreal renders

Amish chose this repo for the first batch of product renders on 2026-09-26. This session adds an appearance model for photoreal renders; the render images themselves are produced later by the portfolio's render pipeline.

### What was added

- `cad/src/product_model.py`: `product_parts()` (52 parts: 23 shell, 23 internal, 2 accessory and 4 context; see the module docstring), `TITLE` and `RENDER_VIEWS` (hero, exploded and a detail view without the wall). It imports `PARAMS`, `derived()` and `context_parts()` from `model.py`, so every main dimension and interface is unchanged. Appearance detail added:
  - Housing with filleted edges, split into a body and a lift-off lid at a parting line 40 mm below the top, with the grey foam lining and plenum dividers inside.
  - A clear inspection window in the lid over the counterflow core, the exhaust fan and the controller, with a black gasket.
  - Louvred inserts in the front exhaust grille and the top supply grille openings; teal side latches, a name plate, a rating label and a control pod with a lit status light and a teal mode button.
  - Plate texture and corner rails on the core; filleted blowers with inlet rings, impellers and labels; pleated supply filter and pad exhaust filter; controller board with module, components and the CO2 sensor.
  - Condensate tray and drain tube; insert panel with EPDM end seals; filleted outdoor hoods with flanges, flange screws and stainless insect mesh; anodized sill bracket with a rubber wall pad; the 24 V adapter and cable.
  - Context: a compact section of the wall with the window frame, the raised lower sash and its glass, cropped around the unit.
- `README.md`: the hero image now points to `media/render-hero.png`, with a link to `media/render-exploded.png`. Both files are to be generated by the render pipeline.

### Differences from model.py (Proposed, awaiting Amish)

1. **Lid window.** `model.py` has an opaque lift-off lid. The appearance model adds a clear window of about 370 x 265 mm over the core, exhaust fan and controller. Recommendation: keep it for the renders and decide at TRL 4 whether a clear lid (for example polycarbonate) is worth its cost and fire rating, or whether the production lid stays opaque.
2. **Controls on the front face.** `model.py` places the controller inside and the BOM lists a status LED and one button without a position. The appearance model puts them in a small pod on the room face with a light pipe implied. Recommendation: adopt this position; the occupant sees the status light without lifting anything.
3. **Lid parting line and latches.** The lid split height (40 mm below the top) and two side latches are appearance choices, not in `model.py` or the BOM. Recommendation: accept for the renders; fix the lid joint at TRL 4.
4. **Context crop.** The upper sash and the full wall and floor of `context_parts()` are left out so the unit fills the frame. The hero is therefore not a full-room view; the existing `media/hero.png` with the person for scale is unchanged.

### TRL

This is an appearance model only: no tolerances, fabrication detail, PCB layout or build work. `trl: 3` and `trl_target: 3` are unchanged, and TRL 4 remains on hold.

## Session 2026-09-27: kit 1.5.0 and image quality

- Kit 1.5.0 synced: STANDARDS v1.5 (sections 12 to 15: product renders, storefront images and image quality, public release, authorship and signing), `.kit/cards.py`, `.kit/image_qc.py`, `.kit/release_gate.py`, issue templates, and the `/render-product` and `/release` commands. `CLAUDE.md` now matches `.kit/CLAUDE.md`.
- Every `media/render-*.png` recaptioned from its original render with the new layout: the title, concept label and repository sit in a band above the render and the view note in a band below it, each line wrapped to the image width, so no text overlaps other text or the render or runs off the image. `media/card.png` and `media/social-preview.png` regenerated with the same rules.
- `python .kit/image_qc.py` and `python .kit/release_gate.py` pass. trl stays 3.

## Session 2026-09-30: build plan and design for construction (kit 1.7.0)

Amish approved the build plan format on 2026-09-30 ("this is the correct build plan ... Extend this across all the other repos") and asked that outstanding decisions go in a separate register, not the build plan. Earlier the same day he wrote: "If you are realising that the design cannot be built as per concept - fix the design assumptions to match and be physically feasible as you draw the illustrations." This session applied both to BreatheBox.

### What was done

- Kit 1.7.0 installed (`.kit/`, `.claude/commands/`); `CLAUDE.md` matches `.kit/CLAUDE.md`.
- `cad/src/model.py` rewritten so every component is modelled as it is made (40 components, grouped by BOM line for the media), with 84 constructability checks (`python cad/src/model.py --check`); all pass and no two components overlap. STEP and STL re-exported.
- `docs/decisions/0003-design-for-construction.md` (BBX-DDR-003 v0.1, Draft): every change below, with reasons; made under Amish's 2026-09-30 instruction to make the design physically buildable; open for his review.
- `cad/src/build_plan_media.py` (uses `.kit/build_views.py`): overview, 14 making sketches (BBX-DWG-101 to 114), 10 joint close-ups, 16 assembly step pictures and a block wiring diagram, in `docs/05-build-plan/` and `cad/drawings/`.
- `docs/05-build-plan.md` (BBX-BLD-001 v0.1) and `docs/06-design-decisions.md` (BBX-DEC-001 v0.1).
- `bom/bom.csv` lines 1, 8, 9, 10, 11 and 13 respecified (lines 1, 10, 11 and 13 repriced); `bom/bom-notes.md`.
- `docs/04-calcs/sizing.py` and BBX-CAL-001 v0.4: mass from the components as made, sill stability and strut joints, filter seat and grille losses, cost. BBX-REQ-001 v0.6, BBX-PRC-001 v0.6, BBX-PRB-001 v0.6, README (links line, key numbers, "Building the prototype"), `project.yaml` (`design_state: constructable`, evidence).
- BBX-DWG-001 Rev P3; concept media regenerated (`media/hero.png`, `concept-blueprint.*`, `cutaway.png`, `exploded.png`, `flow.png`, `model.glb`, `viewer.html`); PDFs rebuilt.

### Design changes made for construction (BBX-DDR-003)

1. Housing: six 6 mm PVC foam boards glued and screwed into eight 10 x 10 mm corner battens, 10 mm foam lining, lift-off lid with a foam plug and two toggle latches (was one solid shell).
2. Air paths: two core frames with a U the core bears on, three full-height dividers (two with a tongue to the core face), and a foam hold-down under the lid (air could pass round the core and under the dividers).
3. Fans: a 6 mm fan bulkhead 94 mm in from the room face; supply fan on its room side, exhaust fan on its core side with its inlet facing the room; both still at the room end (each fan's inlet and outlet were in one chamber).
4. Core: tray shortened to the core's length between the frames, four pads carry the core (it floated 8 mm above the tray).
5. Filters: strip seats with lips and stops, lining lips behind them, foam blocks under the lid (both filters floated; the exhaust pad was the size of its opening).
6. Controller: on the room-side divider in the room-air intake; status light and button behind the room face (it floated across two air streams).
7. Grilles: two slotted aluminium grilles added; the top supply opening moved to 70 x 220 mm over the supply fan's outlet chamber (no finger guards were in the BOM).
8. Window insert: flanged collars and hood back plates bolted through the panel with four M5 bolts per side; collars slide 6 mm into the housing on foam gasket (no fixings).
9. Bracket: two 50 x 4 mm rails bolted under the housing replace the plate; flattened-end struts bolted with two M6 bolts at each end to angle cleats; padded foot bar lowered from 650 to 500 mm; anti-slip tape on the sill (nothing was fixed, and the unit needed 0.65 friction to stay on the sill; now 0.40).
10. Drain: from the tray's end wall at floor level, 40 mm to the exhaust side, through the frame, end wall and panel (it pierced a divider and started above the tray floor).
11. Power entry: M12 gland in the right side wall into the supply outlet chamber (it entered beside the core).
12. Core frames and dividers in 3 mm board to keep the mass under 12 kg.

### Key results (BBX-CAL-001 v0.4)

- Mass 11.4 kg installed (was 10.5 kg); R9 mass part still met on paper, margin 0.6 kg.
- Sill friction needed 0.40 against about 0.6 for anti-slip tape (margin about 1.5); strut top joints 6.5 N·m, 17 MPa in the tube.
- Fans and controls 5.7 W clean, 7.5 W loaded at 50 m³/h; 14.8 W at 70 m³/h loaded; night mode 30.2 dB(A). R1, R3, R6 and R10 status unchanged.
- **R15 now over the value-engineering target:** parts $283.00 against the $255 target ($28 over). **R6 still not met** (39 dB(A) at 50 m³/h). Met 10, not met 1, over the target 1, not verifiable at TRL 3 3.

### Proposed, awaiting Amish (all in BBX-DEC-001)

1. Accept the design-for-construction changes (BBX-DDR-003). Recommendation: accept.
2. Value engineering (A1): the estimate is $28 over the $255 target; `budget_usd` stays $255.
3. Sliding restraint (A2): rely on sill friction with a push test at TRL 4, lower the foot, or add a positive restraint. Recommendation: friction and push test.
4. Sash lock (A3, safety case): no part locks the raised sash onto the panel. Recommendation: a bought no-drill sash jammer (about $10).
5. Still open from before: fan position (O4), co-design partner (O1), and the appearance-model items (status light position, lid window, lid joint).

### Safety concerns

- The unit stays on the sill by friction alone (item 3 above); until that is decided and tested, the build plan treats the prototype as supervised only.
- The raised sash has no lock (item 4); R12 stays "met by design, unverified" only if a lock is added.
- Frost-mode depressurisation and fuel-burning appliances: unchanged, still in every safety section.

### Stale media (made on Amish's Mac; not regenerated here)

The design changed visibly, so these still show the concept and need regenerating with `/render-product` after `cad/src/product_model.py` is updated: `media/render-*.png` (no bulkhead, old fan positions, old 90 x 190 top grille and no grilles, sill plate and old bracket foot, no hood back plates), `media/card.png` and `media/social-preview.png`.

### Recommended next step

Amish reviews BBX-DEC-001 (items 1 to 4). Then update the appearance model to the constructable design on the Mac and regenerate the renders and cards. TRL 4 (building to this plan) stays on hold.

## Session 2026-10-01: Dr. Geeti Chadha added; BioMedical (healthcare) area

Instruction from Amish, 2026-10-01: "yes add Dr. Geeti Chadha to breathebox and dustbadge and make those both healthcare projects". Matched to the TremorTrace worked example.

### What was done

- `project.yaml`: `area` changed from Sustainable Housing to BioMedical, the portfolio's healthcare area; tags now lead with `biomedical`, keeping `sustainable-housing` after it.
- `CONTRIBUTORS.md`: row added for Dr. Geeti Chadha, Contributor.
- `README.md`: area line now BioMedical; Credits name both contributors, Ashok Kumar Chadha and Dr. Geeti Chadha as contributors; the concept rationale and the Safety section state that BreatheBox is a research and educational prototype, not a medical device.
- `CITATION.cff`: `biomedical` keyword added. Dr. Geeti Chadha is not added to the authors, matching TremorTrace, where only Amish is listed.
- `docs/01-problem.md` (BBX-PRB-001 v0.7) and `docs/02-concept.md` (BBX-PRC-001 v0.8): the not-a-medical-device statement added to the existing scope and safety wording.
- `docs/06-design-decisions.md` (BBX-DEC-001 v0.3): the decision recorded under "Decisions made".
- `docs/pdf/`: PDFs of the changed controlled documents rebuilt.

### Wording

No clinical claims were found that needed softening: the documents already describe the CO2 reading as a ventilation indicator, not a health measurement. The changes add the research-and-educational-prototype and not-a-medical-device statement only. Design, requirements, numbers and safety content are unchanged.

### Stale media (on Amish's Mac; not regenerated here)

`media/card.png` and `media/social-preview.png` show the area (Sustainable Housing) and must be regenerated on Amish's Mac with `python .kit/cards.py .`.

### Proposed, awaiting Amish

- None new. The `pitch` and `problem` lines in `project.yaml` are unchanged.

### Recommended next step

Regenerate the card and social preview on the Mac, then continue with the open items in BBX-DEC-001.

## Session 2026-10-02: open decisions decided

Amish approved every recommendation for the open decisions on 2026-10-02: "i approve your recommendations for all 555 open decisions."

### Decisions recorded

Eight, all moved to "Decisions made" in BBX-DEC-001 (open items 1 to 8): design for construction accepted (BBX-DDR-003, P1 to P12); wall foot at 400 mm for the first prototype with the 50 N push test at the trial window; a bought no-drill sash jammer for R12; both fans kept at the room end with a cross-leakage check at TRL 4; Canada first, with ACORN Canada in Toronto as the first candidate partner to approach (ACORN in the United Kingdom as the alternative); status light and button on the room face; opaque lid for the prototype (clear lid in the renders only); top-board lid with two toggle latches.

### Documents changed

- `docs/06-design-decisions.md` BBX-DEC-001 v0.4: decisions made; open decisions section now reads "None"; To confirm items 4 and 5 and the value engineering note updated.
- `docs/decisions/0003-design-for-construction.md` BBX-DDR-003 v0.3: accepted (status Draft kept); A2 decided as option (b), A3 as option (a).
- `docs/01-problem.md` BBX-PRB-001 v0.8: sash lock and first partner questions answered.
- `docs/02-concept.md` BBX-PRC-001 v0.9: fan position decision and the cross-leakage check; the sash jammer in the component table.
- `docs/03-requirements.md` BBX-REQ-001 v0.8: R12 status and verification name the sash jammer.
- `docs/04-calcs/01-sizing.md` BBX-CAL-001 v0.6: R12 text only; no figures changed.
- `bom/bom-notes.md`: sash jammer and the 400 mm foot noted.

### Follow-up actions to carry approved decisions into the design

1. Decision 2 (model): move the wall foot from 500 to 400 mm above the floor in `cad/src/model.py`, with longer struts, and re-run the constructability check.
2. Decision 2 (drawings): update BBX-DWG-001 and the bracket making sketches for the 400 mm foot.
3. Decision 2 (pictures): regenerate the bracket and fitting pictures in `docs/05-build-plan/` and the build plan text (sections 3.12, 3.13 and the fitting steps) for the 400 mm foot.
4. Decision 2 (calculations): rerun the sill stability, strut joint and mass figures in `docs/04-calcs/sizing.py` and BBX-CAL-001 for the 400 mm foot.
5. Decision 2 (BOM): re-specify the strut lengths in row 11.
6. Decision 3 (BOM): add the no-drill sash jammer (about $10) as a line in `bom/bom.csv` and carry the new total into BBX-CAL-001 and the value engineering note.
7. Decision 3 (model, pictures): add the sash jammer to the model and to the window fitting step (step 15) of the build plan.
8. Decision 3 (calculations): change the R12 row text in `docs/04-calcs/sizing.py` to name the sash jammer, so `results.csv` matches BBX-CAL-001.
9. Decision 4 (docs): add the CO2 tracer cross-leakage check to the TRL 4 test plan when it is written.
10. Decisions 7 and 8 (model, pictures): update `cad/src/product_model.py` to the top-board lid with two toggle latches and re-render on Amish's Mac, keeping the clear lid window in the renders only.

### Points found in the review

- Items 6 and 8 are already settled by DDR-003 (P6 puts the light and button in the room face; P1 makes the lid the top board), so accepting item 1 closes them; they can be merged.
- R12 is shown as "Met by design, unverified", but no part locks the sash (item 3). It should read "Not met" until the sash jammer is in the bill of materials.
- The value-engineering estimate of $283 leaves out the sash jammer (about $10), so the real figure is about $293, $38 over the $255 target.
- Wall clearance item 4 under "To confirm" assumes no radiator 470 to 530 mm above the floor; radiators under sash windows are common in the UK and Canada, so the bracket foot may clash at either height.

## Session 2026-10-02: approved follow-ups carried out

Amish approved on 2026-10-02 that every follow-up action from the open-decision sign-off be carried out ("APPROVED CHANGES, COMPLETE THESE"), and that the render scenes be prepared for new photoreal renders on his Mac.

### Approved follow-ups carried out

1. Decision 2 (model): done. The wall foot's centre line is 400 mm above the floor (`foot_z` 500 to 400 in `cad/src/model.py`); the struts are 595.3 mm between end holes (cut 621 mm) and rise at 55° (were 516.6 mm, 543 mm and 49°). New checks: adapter clear of the wall foot, foot clear of the floor, and four for the sash jammer (item 7). The upper sash is added to the all-pairs overlap check. `python cad/src/model.py --check`: 90 of 90 pass (was 84), 41 components. STEP and STL regenerated.
2. Decision 2 (drawings): done. BBX-DWG-001 Rev P4 (wall foot at 400 mm, sash jammer note, mass 11.8 kg). Making sketches BBX-DWG-111 (rail and top cleat: strut holes now 27 and 15.5 from the cleat end, 16 and 32.4 down), BBX-DWG-112 (strut 621 mm, 595.3 mm between holes, 55°) and BBX-DWG-113 (foot at 400 mm; cleat holes 16 and 27.5 out, 17 and 33.4 up) at Rev P2; the hole positions are now computed from the model.
3. Decision 2 (pictures and text): done. Regenerated `docs/05-build-plan/overview.png`, `joint-07.png`, `joint-08.png` (window now follows the foot height), `step-02.png`, `step-13.png` and `step-16.png`. BBX-BLD-001 v0.2: sections 3.2, 3.12 and 3.13, Table 1, step 13, the overview paragraph and the references updated; the wall must be clear about 370 to 430 mm above the floor.
4. Decision 2 (calculations): done. `docs/04-calcs/sizing.py` rerun; BBX-CAL-001 v0.7: sill friction needed 0.32 (margin about 1.9 on anti-slip tape; 0.40 at 500 mm, 0.65 at the concept's 650 mm), foot push 27 N, strut top joint 6.6 N·m, 18 MPa, 329 N per M6 bolt; bracket 1.27 kg (was 1.23 kg).
5. Decision 2 (BOM): done. Row 11 re-specified (struts 621 mm cut, 595 mm between holes, foot 400 mm up) and repriced from $16.00 to $17.00 (about 0.16 m more 20 x 1.5 mm tube at about $6 per metre).
6. Decision 3 (BOM): done. Row 14, sash jammer, $10.00 (typical retail about $8 to $12). Total carried into BBX-CAL-001, BBX-DEC-001 Value engineering, `bom/bom-notes.md`, BBX-REQ-001, BBX-PRC-001, BBX-PRB-001 and the README. Value-engineering target: USD 255. Estimated cost of the constructable design: USD 294 (USD 39 over the target). `budget_usd` unchanged.
7. Decision 3 (model, pictures): done. The jammer is component 14 in the model (a telescopic bar with rubber pads in the inner track, from the top of the raised lower sash to the window head; it touches both and clears the upper sash by 5.5 mm and the glass by 40 mm). It is in the exploded view (item 14), the build plan overview (21), step 15 (`step-15.png`, text, and safety stop S4), section 3.17 and a new first check (sash held down, R12). It is left out of the unit assembly STEP and the GA views, which say so.
8. Decision 3 (calculations): done. The R12 row in `sizing.py` names the sash jammer (BOM line 14); `results.csv` matches BBX-CAL-001 Table 8.
9. Decision 4 (docs): done in this repo as far as the TRL cap allows. No TRL 4 test plan exists, and writing one is TRL 4 work, so the CO2 tracer cross-leakage check is added to the build plan's First checks (BBX-BLD-001 Table 2, R4, pass under about 3 % transfer), which the TRL 4 test plan takes its checks from; BBX-CAL-001 section 11 now records the decision. Carry it into the test plan when TRL 4 starts.
10. Decisions 7 and 8 (appearance model): done here, render pending. `cad/src/product_model.py` rebuilt on the components of `model.py`: top-board lid with two toggle latches on the side walls (parting line at the wall tops), fan bulkhead with the supply fan on its room side and the exhaust fan on its core side, the 70 x 220 mm lid grille and the slotted exhaust grille, status light and button on the room face, controller on the room-side divider, flanged collars, hood back plates and M5 bolts, rails, cleats, flattened-end struts and the 400 mm wall foot, the cable gland and the sash jammer. The clear lid window stays, in the renders only. The wall section now reaches down to 300 mm so the foot rests on visible wall. `RENDER_VIEWS` keeps hero, exploded and detail. Scenes exported to `/home/claude/renders/breathebox/` (three `.npz` and `.json` files and `breathebox__jobs.json`). Photoreal renders, `media/card.png` and `media/social-preview.png` are to be made on Amish's Mac.

Concept media regenerated with the new model (`media/hero.png`, `concept-blueprint.*`, `cutaway.png`, `exploded.png`, `flow.png`, `model.glb`, `viewer.html`); the key figures now say $294 against the $255 value-engineering target.

### Documents changed and new versions

BBX-BLD-001 v0.2; BBX-CAL-001 v0.7; BBX-REQ-001 v0.9; BBX-PRC-001 v0.10; BBX-PRB-001 v0.9; BBX-DEC-001 v0.5; BBX-DDR-003 v0.4; BBX-DWG-001 Rev P4; BBX-DWG-111, 112 and 113 Rev P2; `bom/bom.csv`, `bom/bom-notes.md`, `README.md`; `cad/src/model.py`, `sheets.py`, `concept_media.py`, `build_plan_media.py`, `product_model.py`; `docs/04-calcs/sizing.py` and `results.csv`; PDFs rebuilt.

### Requirement status changes

No status category changed. Figures changed: R9 mass 11.4 to 11.8 kg (sash jammer 0.30 kg estimated and longer struts; still met on paper, margin now 0.2 kg; 12.0 kg with the adapter); R12 still "Met by design, unverified", now with the sash jammer in the bill of materials, which settles the review point that it should read "Not met" until the jammer was listed; R15 over the value-engineering target by $39 (was $28). Met 10, not met 1 (R6), over the value-engineering target 1 (R15), not verifiable at TRL 3 3.

### Cross-repo actions

None. The follow-ups for BreatheBox all live in this repo.

### Proposed, awaiting Amish

- Appearance-model departures from `model.py`, for the renders only: the clear lid window and the matching opening in the lid's foam lining (decided as renders only on 2026-10-02), 4 mm rounds on the housing's vertical edges and 2 mm on the lid, a name plate and a rating label on the room face. Recommendation: accept.
- The mass margin on R9 is now 0.2 kg. If the bought jammer or the adapter lead is heavier than estimated, R9's mass part could be missed; weighing the jammer when it is bought is listed as part of the mass check.

### Safety concerns

Unchanged in kind. The prototype stays supervised only until the 50 N push test passes at the trial window; the lower foot (margin about 1.9) needs a clear wall about 370 to 430 mm above the floor, and radiators under sash windows are common, so the trial window must be checked for that. The jammer must be fitted before the unit is left in the window.

### Recommended next step

Render `breathebox__hero`, `__exploded` and `__detail` on the Mac with `.kit/photoreal.py`, caption them, and regenerate the card and social preview. TRL 4 stays on hold.

## 2026-10-02: photoreal renders redone on the constructable design

Rendered with Blender Cycles on Amish's Mac from the updated appearance model (`cad/src/product_model.py`); captioned with `.kit/photo_caption.py`; `media/card.png` and `media/social-preview.png` regenerated with `.kit/cards.py`. Views: hero, exploded, detail. image_qc passes. Appearance deviations are those logged above as proposed, awaiting Amish.

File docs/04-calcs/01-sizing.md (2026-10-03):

---
doc_id: BBX-CAL-001
title: BreatheBox sizing calculations
project: BreatheBox
doc_type: Calculation note
version: "0.7"
status: Draft
date: '2026-10-02'
author: Amish Chadha
license: CERN-OHL-S-2.0
revisions:
- version: "0.1"
  date: '2026-09-25'
  author: Amish Chadha
  change: First TRL 3 sizing note (core, pressure drop, fans, power, noise, heat recovery, condensate, frost, CO2, geometry, mass, cost) against BBX-REQ-001 v0.3
- version: "0.2"
  date: '2026-09-25'
  author: Amish Chadha
  change: Recommendations accepted by Amish (DDR-002); budget $250, quiet night mode at 32 m³/h and firmware rules added
- version: "0.3"
  date: '2026-09-26'
  author: Amish Chadha
  change: Budget approved by Amish; budget $255 covers the priced BOM, so R15 is met (BBX-DDR-002 v0.2)
- version: "0.4"
  date: '2026-09-30'
  author: Amish Chadha
  change: Constructable design (BBX-DDR-003); mass from the components as made, sill stability and bracket joints, filter seat and grille losses, cost $283 so R15 is not met
- version: "0.5"
  date: '2026-10-01'
  author: Amish Chadha
  change: Budget treated as a value-engineering target
- version: "0.6"
  date: '2026-10-02'
  author: Amish Chadha
  change: "R12 text: sash held by a sash jammer, decided by Amish on 2026-10-02; no figures changed"
- version: "0.7"
  date: '2026-10-02'
  author: Amish Chadha
  change: "Approved follow-ups carried out: wall foot at 400 mm (sill friction 0.32, margin 1.9; strut joints rerun), sash jammer added as BOM line 14 (R12), mass 11.8 kg installed, cost USD 294 (USD 39 over the value-engineering target); fan position decided"
---

# BreatheBox sizing calculations

On paper, BreatheBox meets ten of its fifteen requirements. **One is not met and one is over its value-engineering target.** R6 (noise): the estimate is about 39 dB(A) at 1 m at 50 m³/h against 30 dB(A), and 30 dB(A) is reached only at about 32 m³/h. A quiet night mode at 32 m³/h (BBX-DDR-002) brings the estimate to about 30 dB(A) with clean filters and 32 dB(A) with loaded filters, but R6 is written for 50 m³/h. R15 (cost): Value-engineering target: USD 255. Estimated cost of the constructable design: USD 294 (USD 39 over the target), including the sash jammer decided on 2026-10-02; the savings worth trying are in the design decisions register (BBX-DEC-001). Three requirements (R9 install time, R13 filter change time and R14 firmware behavior) cannot be verified at TRL 3.

The calculations changed four TRL 2 figures. The TRL 2 fans (about 60 m³/h free air) could not reach 70 m³/h against any pressure, so the fan specification rises to about 100 m³/h free air and 400 Pa shut-off. Frost starts at about -2 °C outdoors, not -5 °C, because the plate at the cold corner is colder than the leaving exhaust air. The worst condensate flow is about 0.21 L/h, not 0.14 L/h. Fan and control power at 50 m³/h is about 5.6 W, not 9.5 W, because the system pressure is lower than the 80 Pa assumed.

Every number here is printed by `docs/04-calcs/sizing.py` (run from the repo root: `python docs/04-calcs/sizing.py`), which also writes `docs/04-calcs/results.csv`. The script reads the geometry and part volumes from `cad/src/model.py`, the costs from `bom/bom.csv` and the budget from `project.yaml`. All values are first-principles estimates; nothing is measured.

## 1. Assumptions

*Table 1. Inputs. All are assumptions for a paper design.*

| Input | Value | Basis |
| --- | --- | --- |
| Design case | 30 m³ bedroom, two sleeping adults, 20 °C and 50 % RH indoors, 0 °C outdoors | BBX-REQ-001 |
| Air | 1.2 kg/m³, 1,005 J/(kg·K), 1.5 x 10⁻⁵ m²/s, 0.0257 W/(m·K) | Near 20 °C |
| Airflow per stream | 30 to 70 m³/h, 50 m³/h nominal; 32 m³/h in night mode | BBX-REQ-001 R1; BBX-DDR-001 item A5; BBX-DDR-002 |
| Core | 180 x 180 x 300 mm, 2.5 mm plate pitch, 0.15 mm polymer plates (0.19 W/(m·K)); 85 % of the plate area acts in counterflow | Typical small polymer plate core; no datasheet yet |
| Core heat transfer | Fully developed laminar flow between plates, Nu = 7.54; headers add 2.0 dynamic heads | Textbook laminar values |
| Supply filter | ISO 16890 ePM1 50 %, 25 mm pleated, 150 x 170 mm face; 50 Pa at 1.0 m/s clean, linear with velocity; replaced at twice the clean pressure drop ("loaded") | Typical for this filter class; to be replaced by the chosen filter's data |
| Exhaust filter | Coarse pad, 220 x 190 mm; 15 Pa at 1.0 m/s clean; loaded at twice | Typical |
| Hood and mesh | Hood turn K = 1.5, 1 mm mesh (open area about 59 %) K = 2.0 at low Reynolds number, on the 124 x 174 mm mouth | Conservative loss coefficients |
| Other losses | Port and collar K = 1.0; plenum turn K = 1.5 on the half core face; fan inlet K = 1.0 on a 68 mm inlet; grilles K = 1.5 on 50 % free area | Conservative loss coefficients |
| Fans | Full-speed curve Δp = 400 Pa x (1 - (Q/100 m³/h)²); speed scales by the fan laws; total efficiency 25 %, plus 0.3 W electronics per fan | Class values for 120 x 120 x 32 mm, 24 V centrifugal blowers; no datasheet yet |
| Fan noise | 52 dB(A) at 1 m for a bare fan at full speed; 50 log₁₀ of the speed ratio; 5 dB taken off for the lined plenum and grilles | Class value and fan law; the largest uncertainty in this note |
| Controls | 0.5 W at 3.3 V through an 85 % buck | ESP32-C3 class module with an SCD41 class sensor |
| CO2 | 0.014 m³/h per sleeping adult, 420 ppm outdoors, no infiltration, 8 h of sleep | Common planning values |
| Season | 3,500 K·d over 212 days | Cold-temperate climate |
| Depressurization | 5 Pa screening limit; 800 x 10 mm door undercut, discharge coefficient 0.6 | Screening assumption; to be checked against local code |
| Densities | PVC foam board 550 kg/m³; closed-cell foam 30 kg/m³; 10 x 10 mm strip 550 kg/m³; panel 190 kg/m³ effective; rigid PVC sheet 1,400 kg/m³; PETG 1,270 kg/m³; aluminium 2,700 kg/m³; modelled bolts 7,900 kg/m³; applied to each component's modelled volume | Typical materials |
| Sill friction | About 0.6 for anti-slip rubber tape on a painted or varnished sill | Assumption; to be checked with a push test |

## 2. Core effectiveness (R2)

The core has 72 channels (36 per stream) with a 2.35 mm gap and a 4.7 mm hydraulic diameter, and 71 plates with 3.83 m² of area, 3.26 m² of it effective. The laminar film coefficient is 41.2 W/(m²·K) on each side, so U is 20.3 W/(m²·K) and UA is 66.1 W/K. Because the flow in the channels stays laminar (Reynolds number 171 to 400), UA does not change with airflow.

*Table 2. Core performance, balanced flow.*

| Airflow | Heat capacity rate | NTU | Effectiveness | Channel velocity | Core pressure drop |
| --- | --- | --- | --- | --- | --- |
| 30 m³/h | 10.05 W/K | 6.58 | 86.8 % | 0.55 m/s | 6.8 Pa |
| 50 m³/h | 16.75 W/K | 3.95 | 79.8 % | 0.91 m/s | 11.7 Pa |
| 70 m³/h | 23.45 W/K | 2.82 | 73.8 % | 1.28 m/s | 16.9 Pa |

**R2 is met on paper:** 79.8 % at 50 m³/h against 75 %. At the 70 m³/h boost the effectiveness falls to 73.8 %, which is outside R2's 50 m³/h case.

## 3. System pressure drop (R1)

The supply stream loses more than the exhaust stream because it carries the ePM1 filter. The filter and the fan inlet dominate; the hoods, mesh and ports add less than 3 Pa together.

*Table 3. Pressure drop per stream, clean and loaded filters.*

| Airflow | Supply, clean | Supply, loaded | Exhaust, clean | Exhaust, loaded |
| --- | --- | --- | --- | --- |
| 30 m³/h | 27.9 Pa | 44.3 Pa | 14.4 Pa | 18.1 Pa |
| 50 m³/h | 52.3 Pa | 79.6 Pa | 28.7 Pa | 34.8 Pa |
| 70 m³/h | 81.4 Pa | 119.5 Pa | 46.8 Pa | 55.4 Pa |

At 50 m³/h the clean supply stream splits into filter 27.2 Pa, core 11.7 Pa, fan inlet 8.8 Pa, room grille 2.9 Pa, hood and mesh 0.9 Pa, plenum turn 0.7 Pa and port 0.2 Pa. The TRL 2 estimate of 80 Pa matches only the loaded supply filter case. The constructable design (BBX-DDR-003) adds about 0.5 Pa on the supply side, because the top grille opening is now 70 x 220 mm over the supply fan's outlet chamber, and about 1.1 Pa on the exhaust side, because the exhaust pad works through a 200 x 170 mm lining lip. The supply filter's lip lies on its frame, not its media, so its drop is unchanged.

## 4. Fans, power and noise (R1, R3, R6, R10)

**Operating points.** With the assumed full-speed curve, the fans reach 86 m³/h per stream with clean filters and **80 m³/h with loaded filters**, so the 30 to 70 m³/h range of R1 is covered with a margin. The TRL 2 fan (about 60 m³/h free air) could not reach 70 m³/h even with no system resistance, which is why BOM items 3 and 4 now call for about 100 m³/h free air and 400 Pa shut-off. The supply and exhaust fans run at different speeds for the same flow (0.62 and 0.57 of full speed at 50 m³/h), so balance within 10 % needs the tach feedback and a one-time calibration against the system curves. **R1 is met on paper.**

*Table 4. Operating points. Power is fans plus controls.*

| Case | Supply speed | Exhaust speed | Power | Room noise at 1 m |
| --- | --- | --- | --- | --- |
| 30 m³/h, clean | 0.40 | 0.35 | 2.6 W | 29.0 dB(A) |
| 30 m³/h, loaded | 0.45 | 0.37 | 3.3 W | 30.9 dB(A) |
| 50 m³/h, clean | 0.62 | 0.57 | 5.7 W | 38.7 dB(A) |
| 50 m³/h, loaded | 0.67 | 0.58 | 7.5 W | 40.0 dB(A) |
| 70 m³/h, clean | 0.83 | 0.78 | 11.2 W | 45.4 dB(A) |
| 70 m³/h, loaded | 0.89 | 0.79 | 14.8 W | 46.4 dB(A) |

**Power (R3).** 5.7 W at 50 m³/h with clean filters and 7.5 W with loaded filters, against 12 W. **R3 is met on paper.** Over the heating season the fans and controls use about 29 kWh.

**Noise (R6).** At 50 m³/h the estimate is about **39 dB(A) at 1 m, so R6 is not met.** With clean filters the unit reaches 30 dB(A) only at about 32 m³/h. The noise figure rests on an assumed catalog value and a fan law, so it may be several decibels out in either direction, but even a 5 dB error leaves R6 unmet at 50 m³/h.

**Night mode (BBX-DDR-002).** Amish accepted the recommendation of a quiet night mode, with larger, slower fans or a lined silencer to be checked against a real fan datasheet before any change to R6. The firmware rule is: in night mode both streams run at 32 m³/h (balanced by tach), the CO2 boost is suppressed, and frost mode and the speed cap still apply. At 32 m³/h the estimate is **30.2 dB(A) with clean filters and 32.0 dB(A) with loaded filters**, for 2.8 W and 3.6 W. With loaded filters, 30 dB(A) would need about 28 m³/h, below the 30 m³/h floor of R1, so the night mode stays at 32 m³/h and relies on filter changes. The datasheet check is on hold with TRL 4.

**Adapter and fuse (R10).** The 70 m³/h loaded case needs 14.8 W (0.62 A at 24 V). The worst case, both fans at full speed at their peak air power (58 m³/h each on the assumed curve), is about 35.4 W (1.48 A), just under the 36 W adapter rating. The firmware caps fan speed at what 80 m³/h needs (a firmware rule accepted in BBX-DDR-002), and the 24 V input carries a 2 A time-delay fuse. **R10 is met by design** (24 V SELV only).

## 5. Heat recovery

*Table 5. Heat at 0 °C outdoors and 20 °C indoors.*

| Airflow | Heat carried by exhaust | Recovered | Lost | Supply air |
| --- | --- | --- | --- | --- |
| 50 m³/h | 335 W | 267 W | 68 W | 16.0 °C (16.1 °C with fan heat) |
| 70 m³/h | 469 W | 346 W | 123 W | 14.8 °C (15.0 °C with fan heat) |

Over a season of 3,500 K·d at 50 m³/h the core keeps about 1,123 kWh of heat in the room for about 29 kWh of fan and control energy, a ratio of about 39 to 1. The 335 W is also the heat an open window would lose at the same airflow.

## 6. Condensate and frost (R7)

**Condensate.** Room air at 20 °C and 50 % RH holds 7.3 g/kg. The upper bound assumes the exhaust cools to its dry outlet temperature and leaves saturated. At 0 °C outdoors this gives 132 g/h at 50 m³/h (exhaust leaves at 4.0 °C) and 148 g/h at 70 m³/h. The worst case above frost onset is **214 g/h (0.21 L/h) at 70 m³/h and -3.0 °C**, above the 0.14 L/h estimated at TRL 2. That is 0.06 mL/s, which an 8 mm bore tube falling outward drains easily; the risk is the tube freezing outdoors, not its size.

**Frost onset.** Frost forms where the plate is coldest: the corner where cold supply air enters and exhaust air leaves. With equal film coefficients on both sides, that plate sits midway between the two air temperatures. Frost starts at about **-2.2 °C outdoors at 50 m³/h** and -3.0 °C at 70 m³/h. The TRL 2 figure of -5 °C used the exhaust air temperature alone and was too optimistic.

**Frost mode.** Slowing the supply fan (BBX-DDR-001 item A4) keeps the cold corner at 0 °C at -10 °C outdoors when the supply flow is 33 % of the exhaust flow: 17 m³/h against 50 m³/h. The room still receives 50 m³/h of fresh air, 17 m³/h through the core and 33 m³/h drawn from the rest of the home. Through an 800 x 10 mm door undercut that imbalance depressurizes the room by about 2.2 Pa (4.4 Pa at 70 m³/h), under the 5 Pa screening limit. With the door sealed, the depressurization could be much larger. **R7 is met on paper**, with the combustion-appliance restriction in BBX-PRC-001.

A preheater that kept the flows balanced at -10 °C would need about 130 W, more than three times the 36 W adapter. This supports the slowed-fan strategy for a 24 V unit.

> **Safety:** Frost mode extracts more air than it supplies. Do not use BreatheBox in a room with an open-flued or unflued fuel-burning appliance, and do not install it in a room whose door seals airtight.

## 7. CO2 (R4)

*Table 6. CO2 with two sleepers in a 30 m³ room, no infiltration.*

| Airflow | Night steady state | 24 h mean (8 h occupied) | Time constant |
| --- | --- | --- | --- |
| 30 m³/h | 1,353 ppm | 731 ppm | 60 min |
| 50 m³/h | 980 ppm | 607 ppm | 36 min |
| 70 m³/h | 820 ppm | 553 ppm | 26 min |
| 32 m³/h, night mode all day (bounding case) | 1,295 ppm | 712 ppm | 56 min |

**R4 is met on paper**: the 24 h mean is 607 ppm at 50 m³/h against 1,000 ppm, and even the night steady state (980 ppm) stays under 1,000 ppm. At 30 m³/h the 24 h mean still meets R4, although the night level reaches about 1,350 ppm. This matters for R6: the night mode at 32 m³/h (BBX-DDR-002) meets R4 as written, with a 24 h mean of 712 ppm even if it ran all day, while the room air rises toward about 1,300 ppm for part of the night.

## 8. Geometry, structure and mass (R8, R9, R11, R12)

- **R11, met on paper.** The hood mouths are 130 mm wide with outer edges at ±340 mm, leaving 420 mm between the supply intake and the exhaust outlet. Both face down, with 1 mm mesh.
- **R8, met on paper for sash windows.** The hoods need at least 686 mm of clear width, just inside the 700 mm lower bound; the panel trims to 700 to 1,000 mm. Casement and tilt-and-turn windows remain outside this version (BBX-DDR-001 item A2).
- **R12, met by design.** The largest opening through the installed unit is a 2.35 mm core channel; the mesh is 1 mm. The raised sash is held down on the panel by a bought no-drill sash jammer wedged in the inner track between the top of the raised sash and the window head (decided 2026-10-02, BBX-DEC-001; bill of materials line 14, about $10, 0.30 kg estimated).
- **Housing.** 510 x 560 x 250 mm, with 110 mm on the sill and 400 mm projecting into the room. The model now holds every component as it is made (BBX-DDR-003); its 90 constructability checks pass and no two of its 41 components (the sash jammer included) overlap.
- **Stability on the sill (BBX-DDR-003).** The housing, its two rails, the struts and the wall foot are one rigid body, because each strut end has two bolts. The parts it carries weigh 8.6 kg with their centre of mass 162 mm on the room side of the wall face. The body rests on the inner edge of the sill and pushes on the wall at the foot, whose centre line is 400 mm above the floor (500 mm below the sill edge), with about 27 N; the collars only slide into the housing, so friction at the sill is all that stops it sliding into the room. The friction needed is 0.32, against about 0.6 for anti-slip tape: a margin of about 1.9. With the foot at 500 mm it would be 0.40 (margin 1.5), and with the concept's foot at 650 mm, 0.65. Amish decided on 2026-10-02 to build the first prototype with the foot at 400 mm and to run a 50 N push test at the trial window (BBX-DEC-001); the foot goes back to 500 mm only where a radiator or skirting blocks the lower foot and the push test passes on that sill. The struts are now 595 mm between end holes (cut 621 mm), rising at 55°.
- **Bracket joints.** Each strut's top joint carries about 6.6 N·m: 18 MPa of bending in the 20 x 1.5 mm tube (6063 yields at about 110 MPa) and about 329 N of shear on each of its two M6 bolts. Both are small. The lower foot pushes less on the wall, but the longer struts carry that push over a longer arm, so the joint figures are almost unchanged.

*Table 7. Mass from the modelled components (BBX-DDR-003).*

| Item | Mass |
| --- | --- |
| 1 Housing: boards, battens, lining, core frames, dividers, bulkhead, filter seats, lid, grilles, latches | 4.79 kg |
| 2 Core (plates 0.78 kg, frame 0.30 kg) | 1.08 kg |
| 3, 4 Fans | 0.60 kg |
| 5, 6 Filters | 0.15 kg |
| 7 Controller and status board | 0.08 kg |
| 8 Tray, pads and drain | 0.24 kg |
| 9 Insert panel and seals | 0.70 kg |
| 10 Collars, hoods and back plates | 2.08 kg |
| 11 Sill bracket: rails, cleats, struts, foot and pad | 1.27 kg |
| 12 Adapter | 0.25 kg |
| 13 Modelled bolts and cable gland | 0.19 kg |
| 14 Sash jammer (bought; estimate) | 0.30 kg |
| Sundries (wiring, gasket, glue, small screws) | 0.30 kg |
| **Total** | **12.0 kg (11.8 kg installed, without the adapter)** |

The mass part of R9 is met on paper, with a small margin: 11.8 kg against 12 kg (11.5 kg without the sash jammer). It was 11.4 kg before the 2026-10-02 follow-ups (longer struts and the sash jammer) and 10.5 kg before the design was made constructable. The 30 min install time cannot be verified until someone fits the unit, so **R9 is not verifiable at TRL 3**.

## 9. Cost (R15)

Value-engineering target: USD 255. Estimated cost of the constructable design: USD 294 (USD 39 over the target). The priced BOM totals **$294.00** over 14 lines; the target is `budget_usd`, set on 2026-09-26 (BBX-DDR-002; it was $250, and $220 before 2026-09-25), and is unchanged. **R15 is over the value-engineering target by $39.** The concept's BOM was $255; the rise comes from parts the concept needed but did not list, added when the design was made constructable (BBX-DDR-003): partitions, filter seats, grilles and latches (+$18), hood back plates and collar flanges (+$2), the bracket's rails, cleats and foot (+$4), and bolts, gland and anti-slip tape (+$4). The 2026-10-02 decisions added the sash jammer (line 14, +$10) and longer struts for the 400 mm foot (line 11, +$1). The savings worth trying are in the design decisions register (BBX-DEC-001). Earlier, the increase from $243 to $255 came from the larger fans (+$8), the collars through the panel (+$2) and the input fuse and holder (+$2).

## 10. Results

*Table 8. Requirement status (from `docs/04-calcs/results.csv`).*

| ID | Value | Target | Status |
| --- | --- | --- | --- |
| R1 | 30 to 70 m³/h per stream; full-speed limit 80 m³/h with loaded filters; balanced by tach | 30 to 70 m³/h, within 10 % | Met on paper |
| R2 | 79.8 % at 50 m³/h (73.8 % at 70 m³/h) | 75 % or more at 50 m³/h | Met on paper |
| R3 | 5.7 W clean, 7.5 W loaded | 12 W or less at 50 m³/h | Met on paper |
| R4 | 24 h mean 607 ppm (712 ppm in night mode); night 980 ppm (1,295 ppm in night mode) | 1,000 ppm or less, 24 h mean | Met on paper |
| R5 | ePM1 50 % supply, coarse exhaust | ePM1 50 % or better | Met by specification |
| R6 | 39 dB(A) at 50 m³/h; night mode at 32 m³/h 30 dB(A) clean, 32 dB(A) loaded | 30 dB(A) or less at 50 m³/h | **Not met** |
| R7 | Worst condensate 0.21 L/h drains; frost onset -2.2 °C; supply at 33 % of exhaust at -10 °C | Drain all condensate; no blockage to -10 °C | Met on paper |
| R8 | Hoods need 686 mm clear width; panel 700 to 1,000 mm | Sash 700 to 1,000 mm; slider adapter | Met on paper (sash) |
| R9 | 11.8 kg (sash jammer included); no drilling; install time not calculable | 12 kg or less; 30 min or less | Not verifiable at TRL 3 (mass met on paper) |
| R10 | 36 W SELV adapter; 14.8 W at 70 m³/h loaded; 35.4 W worst case; 2 A fuse | 24 V SELV only | Met by design |
| R11 | 420 mm between mouths; 1 mm mesh; mouths face down | 400 mm or more; mesh 1.5 mm or finer | Met on paper |
| R12 | Largest opening 2.35 mm; raised sash held down on the panel by a bought no-drill sash jammer (BOM line 14) | Sash lockable onto the panel; no opening over 100 mm | Met by design, unverified |
| R13 | Lift-off lid; filters and core slide out | Tool-free filter change in 2 min or less | Not verifiable at TRL 3 |
| R14 | No firmware yet; checked at firmware review | Local data only | Not verifiable at TRL 3 |
| R15 | $294.00 | $255 value-engineering target | **Over the value-engineering target by $39** |

Summary: met 10, not met 1 (R6), over the value-engineering target 1 (R15), not verifiable at TRL 3 3 (R9, R13, R14).

## 11. Limits of this note

- The fan curve, fan noise and filter resistance are class values, not datasheet values. R1, R3, R6 and R10 should be rechecked when parts are chosen; the night mode noise figure carries the same uncertainty.
- Laminar, fully developed flow and equal film coefficients are idealizations; real cores with headers usually recover a few points less than this model predicts.
- Leakage between streams in the core, air leakage around the insert panel and the latent heat released by condensation are not modeled. The last makes the frost onset slightly conservative.
- In the chosen layout both fans sit in the room-end plenum, so the exhaust side of the core runs at a higher pressure than the supply side. Any core leakage would carry stale air into the supply. Amish decided on 2026-10-02 to keep both fans at the room end for the prototype; a cross-leakage check (CO2 tracer in the exhaust stream, measured in the supply) is part of the TRL 4 checks, and the exhaust fan moves to the outdoor end only if the transfer exceeds about 3 % (BBX-DEC-001).

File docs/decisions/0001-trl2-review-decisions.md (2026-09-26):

---
doc_id: BBX-DDR-001
title: BreatheBox TRL 2 review decisions
project: BreatheBox
doc_type: Design decision record
version: "0.3"
status: Draft
date: '2026-09-26'
author: Amish Chadha
license: CERN-OHL-S-2.0
revisions:
- version: "0.1"
  date: '2026-09-25'
  author: Amish Chadha
  change: Record the TRL 2 recommendations adopted for TRL 3 under Amish's 2026-09-25 instruction, open for his review, and the items that remain open
- version: "0.2"
  date: '2026-09-25'
  author: Amish Chadha
  change: Recommendations accepted by Amish (DDR-002)
- version: "0.3"
  date: '2026-09-26'
  author: Amish Chadha
  change: "O3 decided by Amish, 2026-09-26: budget $255 (BBX-DDR-002)"
---

# 0001: TRL 2 review decisions

- **Date:** 2026-09-25
- **Status:** items A1 to A6 and O2 decided by Amish, 2026-09-25: go with recommendation (see BBX-DDR-002); item O1 remains proposed, awaiting Amish; O3 was decided by Amish on 2026-09-26 (budget $255, BBX-DDR-002).

## Context

The TRL 2 review note (`docs/REVIEW.md`, session of 2026-09-25) listed seven items as "Proposed, awaiting Amish", six of them with a recommendation. On 2026-09-25 Amish asked for this batch of repos to be taken through the usual process with the instruction "you know the drill, nothing gets past TRL 3". He did not review this repo's items one by one. The recommendations are therefore adopted as the basis for the TRL 3 calculations, model and drawing, and stay open for his review. Nothing in version 0.1 of this record was decided by Amish. On 2026-09-25 he accepted all recommendations ("i accept all your recommendations, go with them across all repos"); the status column now shows this, and BBX-DDR-002 lists the changes.

## Options considered

The options for each item are in `docs/REVIEW.md` (TRL 2 session) and BBX-PRC-001. They are not repeated here.

## Decision

*Table 1. Items adopted for TRL 3, since decided by Amish (BBX-DDR-002).*
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

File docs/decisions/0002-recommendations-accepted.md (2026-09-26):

---
doc_id: BBX-DDR-002
title: BreatheBox recommendations accepted
project: BreatheBox
doc_type: Design decision record
version: "0.2"
status: Draft
date: '2026-09-26'
author: Amish Chadha
license: CERN-OHL-S-2.0
revisions:
- version: "0.1"
  date: '2026-09-25'
  author: Amish Chadha
  change: Record the recommendations accepted by Amish on 2026-09-25, what changed in the repo and the items still open
- version: "0.2"
  date: '2026-09-26'
  author: Amish Chadha
  change: "Budget set to $255 to cover the priced BOM: decided by Amish, 2026-09-26 (O3 closed)"
---

# 0002: Recommendations accepted

- **Date:** 2026-09-25
- **Status:** accepted. Amish accepted every recommendation in `docs/REVIEW.md` and BBX-DDR-001. Items without a recommendation stay proposed, awaiting Amish, except the budget gap (O3), decided by Amish on 2026-09-26.
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

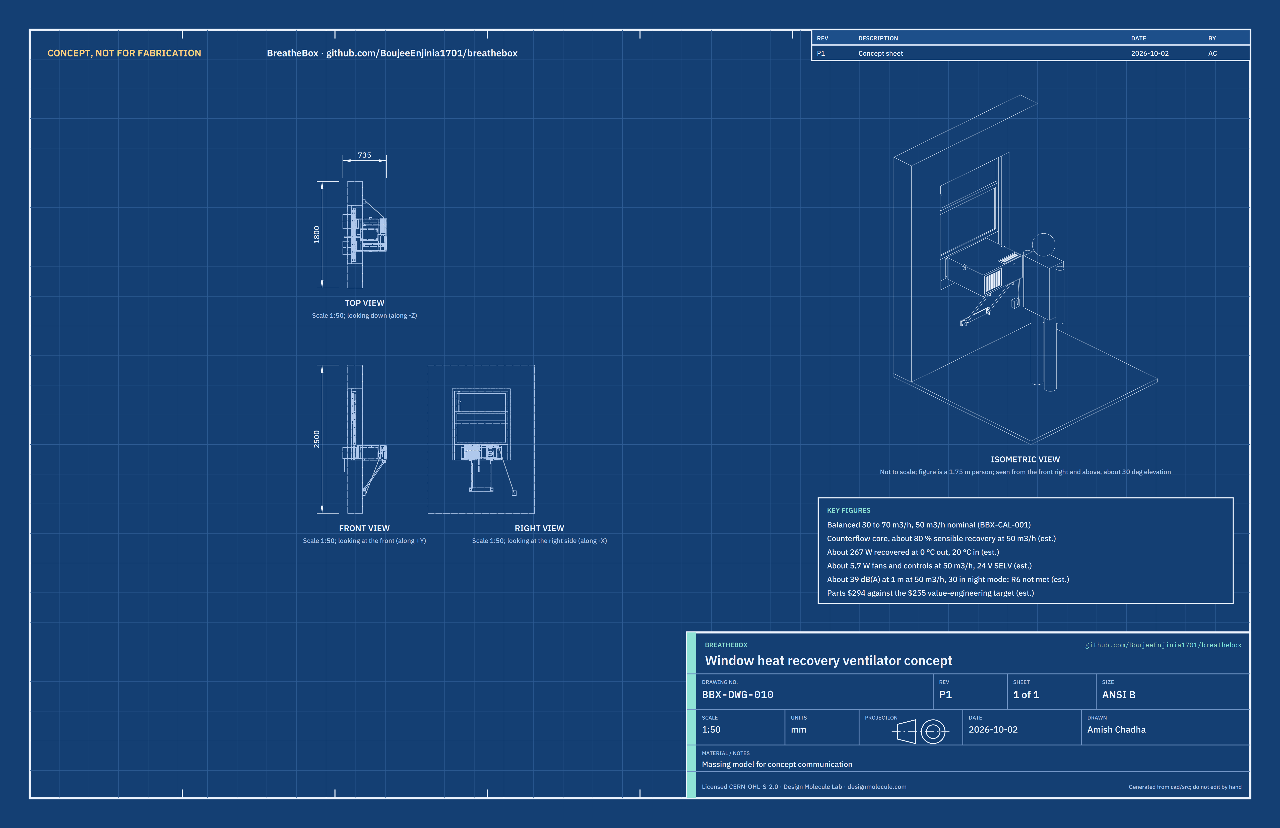
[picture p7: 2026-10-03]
media/concept-blueprint.png

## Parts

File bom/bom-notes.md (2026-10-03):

# BOM notes

- Prices are indicative USD for single prototype quantities in September 2026. Every line is priced, with a supplier or supplier type; no price has been confirmed with a named supplier. They are estimates for TRL 3 review.
- Rows 1 to 12 and row 14 match the numbered callouts in `media/exploded.png` and the parts in `cad/src/model.py`. Row 13 (seals, fasteners, wiring and the input fuse) is not in the exploded view; the bolts and the cable gland are in the model.
- Value-engineering target: USD 255. Estimated cost of the constructable design: USD 294 (USD 39 over the target). The total of **$294.00** over 14 lines is computed by `docs/04-calcs/sizing.py` (BBX-CAL-001 section 9); the target is `budget_usd` in `project.yaml`, set by Amish on 2026-09-26 (BBX-DDR-002), and is unchanged. R15 is over the value-engineering target by $39. The rise from the concept's $255 comes from parts the concept needed but did not list, added when the design was made constructable on 2026-09-30 (BBX-DDR-003): partitions, filter seats, grilles and latches in row 1 (+$18), hood back plates and collar flanges in row 10 (+$2), bracket rails, cleats and foot in row 11 (+$4), and bolts, gland and anti-slip tape in row 13 (+$4); and from the 2026-10-02 decisions: the sash jammer in row 14 (+$10) and longer struts in row 11 (+$1). The savings worth trying are in the design decisions register (BBX-DEC-001).
- Changes from TRL 2 ($243) to the concept at TRL 3 ($255): larger blowers in rows 3 and 4 (+$8, because the TRL 2 fans could not reach 70 m³/h), collars through the panel in row 10 (+$2), and a 2 A fuse and holder in row 13 (+$2).
- The counterflow core (row 2) is the largest single cost and sets the heat recovery figure. A home-made crossflow core from corrugated plastic sheet would cost about $10 but recover only about 50 to 65 % (estimate).
- The unit runs from a certified 24 V plug-in adapter. There is no mains wiring inside the unit.
- Decided by Amish on 2026-10-02 (BBX-DEC-001): a bought no-drill sash jammer or adjustable security bar, wedged in the inner track above the raised sash, is part of the kit (R12). It is row 14, $10.00, the middle of a typical retail range of about $8 to $12; its mass is estimated at 0.30 kg.
- Decided by Amish on 2026-10-02 (BBX-DEC-001): the first prototype's wall foot is at 400 mm above the floor (was 500 mm). Row 11 is re-specified: each strut is cut 621 mm long (was 543 mm), 595 mm between end holes, rising at 55°. The extra 0.16 m of 20 x 1.5 mm aluminium tube at about $6 per metre raises row 11 from $16.00 to $17.00. Bracket mass rises from 1.23 to 1.27 kg.

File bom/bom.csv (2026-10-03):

item | qty | spec | supplier | unit_cost_usd | make_buy | notes
1 Insulated housing | 1 | Shell 510 x 560 x 250 mm: base, two sides, two ends and lift-off lid cut from 6 mm PVC foam board, glued and screwed into 10 x 10 mm corner battens; 10 mm closed-cell foam lining; two core frames and three dividers from 3 mm PVC foam board; 6 mm fan bulkhead; 10 x 10 mm strip filter seats; foam core hold-down and filter top blocks under the lid; two perforated aluminium grilles 1.5 mm (240 x 210 and 90 x 240 mm, 4 mm slots); two small toggle latches | Sign and plastics supplier (PVC foam board); hardware store (foam) | 42.00 | make | Indicative price; fire-retardant foam grade proposed; partitions, seats, grilles and latches added for construction (BBX-DDR-003)
2 Counterflow core | 1 | Polymer plate counterflow core 180 x 180 x 300 mm, about 2.5 mm plate pitch, about 80 % sensible effectiveness at 50 m3/h (BBX-CAL-001), washable | HRV spare-parts supplier | 48.00 | buy | Indicative price; core choice drives R2 and R13
3 Supply fan | 1 | 24 V DC brushless centrifugal blower, 120 x 120 x 32 mm class, about 100 m3/h free air and 400 Pa shut-off at full speed, PWM input and tach output | Electronics distributor (for example Digi-Key or Mouser) | 19.00 | buy | Indicative price; larger than the TRL 2 fan (60 m3/h free air could not reach 70 m3/h)
4 Exhaust fan | 1 | Same as item 3 | Electronics distributor (for example Digi-Key or Mouser) | 19.00 | buy | Indicative price
5 Supply filter | 1 | ISO 16890 ePM1 50 % pleated panel filter, 150 x 170 x 25 mm, synthetic media | HVAC filter supplier (cut from a standard panel) | 10.00 | buy | Indicative price; replace about every 6 months or at twice the clean pressure drop
6 Exhaust filter | 1 | ISO 16890 coarse (G3 class) washable pad 220 x 190 x 12 mm to keep lint and dust off the core | HVAC filter supplier | 3.00 | buy | Indicative price
7 Controller with CO2 and RH sensing | 1 | ESP32-C3 class module; Sensirion SCD41 class CO2, humidity and temperature sensor; two NTC probes (core exhaust outlet and supply); 24 to 3.3 V buck; two PWM fan outputs with tach inputs; status LED and one button | Electronics distributor (for example Digi-Key or Mouser) | 42.00 | buy | Indicative price (sensor about $25); check the sensor on CalRig before use
8 Condensate tray and drain | 1 | Folded PETG tray 300 x 200 x 14 mm between the core frames with four 20 x 20 x 12 mm core pads; 12 x 8 mm silicone drain tube from the tray's outdoor end wall at floor level, through the core frame, housing and panel | Plastics supplier; hardware store | 6.00 | make | Indicative price; pads cut from tray offcuts (BBX-DDR-003)
9 Window insert panel | 1 | 20 mm panel (PVC foam skins over XPS core), 260 mm high, trimmed to 700 to 1000 mm clear width, compressible EPDM edge seals, two 158 x 178 mm collar cut-outs, a 14 mm drain hole and eight 5.5 mm bolt holes | Hardware store | 20.00 | make | Indicative price
10 Outdoor hoods and collars | 1 | Two downward-facing hoods from 3 mm rigid PVC sheet glued to 3 mm back plates, 1 mm stainless insect mesh on 130 x 180 mm mouths, 420 mm clear between mouths; two rectangular collars (150 x 170 mm bore, 3 mm wall) with 20 mm flanges, bolted through the panel to the back plates with four M5 bolts each | Plastics supplier; hardware store | 26.00 | make | Indicative price; back plates and collar flanges added for construction (BBX-DDR-003)
11 Sill bracket | 1 | Two 50 x 4 mm aluminium flat bar rails 390 mm long bolted under the housing; two 20 x 1.5 mm aluminium tube struts, each cut 621 mm long with flattened, two-hole ends (595 mm between end holes, rising at 55 degrees); four 40 x 40 x 3 mm aluminium angle cleats 50 mm long; 60 x 6 mm aluminium foot bar 400 mm long with a 2 mm rubber pad, its centre line 400 mm above the floor; props on the wall without drilling | Hardware store; metal stockist | 17.00 | make | Indicative price; rails replace the 4 mm plate to save 1.3 kg (BBX-DDR-003); foot lowered from 500 to 400 mm on 2026-10-02 (BBX-DEC-001), so each strut is 78 mm longer: about 0.16 m more 20 x 1.5 mm tube at about $6 per metre, +$1
12 24 V power supply | 1 | Certified plug-in 24 V DC 1.5 A (36 W) SELV adapter with 3 m low-voltage cable | Electronics distributor (for example Digi-Key or Mouser) | 14.00 | buy | Indicative price; no mains wiring in the unit
13 Seals fasteners wiring and fuse (not shown) | 1 | Foam gasket tape, anti-slip rubber tape for the housing base, stainless M5 and M6 bolts with nyloc nuts (8 for the hoods, 4 for the rails, 8 countersunk for the cleats, 8 M6 for the struts), M4 nylon screws and rubber grommets for the fans, M12 cable gland, screws for battens and grilles, cable ties, JST connectors, aluminium tape, 2 A time-delay fuse and inline holder on the 24 V input | Hardware store; electronics distributor | 18.00 | buy | Indicative price; not numbered in the exploded view; bolts and gland added for construction (BBX-DDR-003)
14 Sash jammer | 1 | Bought no-drill adjustable sash jammer or window security bar, telescopic, about 22 mm square, set to about 340 mm with rubber end pads, wedged in the inner track between the top of the raised lower sash and the window head so the sash cannot be lifted off the insert panel | Hardware store or security hardware retailer | 10.00 | buy | Indicative price (typical retail for a no-drill sash jammer or adjustable window security bar is about $8 to $12); decided by Amish on 2026-10-02 for R12 (BBX-DEC-001, BBX-DDR-003 A3); shown as item 14 in the exploded view

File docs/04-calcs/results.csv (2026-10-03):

id | value | target | status
R1 | 30 to 70 m3/h each stream; full-speed limit 80 m3/h with loaded filters; balance by tach | 30 to 70 m3/h, within 10 % | Met on paper
R2 | 79.8 % at 50 m3/h (73.8 % at 70) | 75 % or more at 50 m3/h | Met on paper
R3 | 5.7 W clean, 7.5 W loaded filters | 12 W or less at 50 m3/h | Met on paper
R4 | 24 h mean 607 ppm at 50 m3/h, 712 ppm in night mode; night 980 ppm, 1295 ppm in night mode | 1,000 ppm or less, 24 h mean | Met on paper
R5 | ePM1 50 % supply, coarse exhaust | ePM1 50 % or better | Met by specification
R6 | 39 dB(A) at 50 m3/h; night mode 32 m3/h 30 dB(A) clean, 32 dB(A) loaded | 30 dB(A) or less at 50 m3/h | Not met
R7 | worst condensate 0.21 L/h drains; frost onset -2.2 °C; at -10 °C supply ratio 0.33 | Drain all condensate; no blockage to -10 °C | Met on paper
R8 | hoods need 686 mm clear width; panel trims to 700 to 1,000 mm | Sash 700 to 1,000 mm; slider adapter | Met on paper (sash)
R9 | 11.8 kg; no drilling; install time not calculable | 12 kg or less; 30 min or less | Not verifiable at TRL 3 (mass met on paper)
R10 | 24 V SELV adapter 36 W; 14.8 W at 70 m3/h loaded, 35.4 W worst case at full speed; 2 A input fuse | 24 V SELV only | Met by design
R11 | 420 mm between mouths; 1 mm mesh; mouths face down | 400 mm or more; mesh 1.5 mm or finer | Met on paper
R12 | largest through opening 2.35 mm; raised sash held down on the panel by a bought no-drill sash jammer (BOM line 14) | Sash lockable onto the panel; no opening over 100 mm | Met by design, unverified
R13 | lift-off lid; filters and core slide out | Tool-free filter change in 2 min or less | Not verifiable at TRL 3
R14 | no firmware yet; checked at firmware review | Local data only | Not verifiable at TRL 3
R15 | $294.00 | $255 value-engineering target | Over the value-engineering target by $39

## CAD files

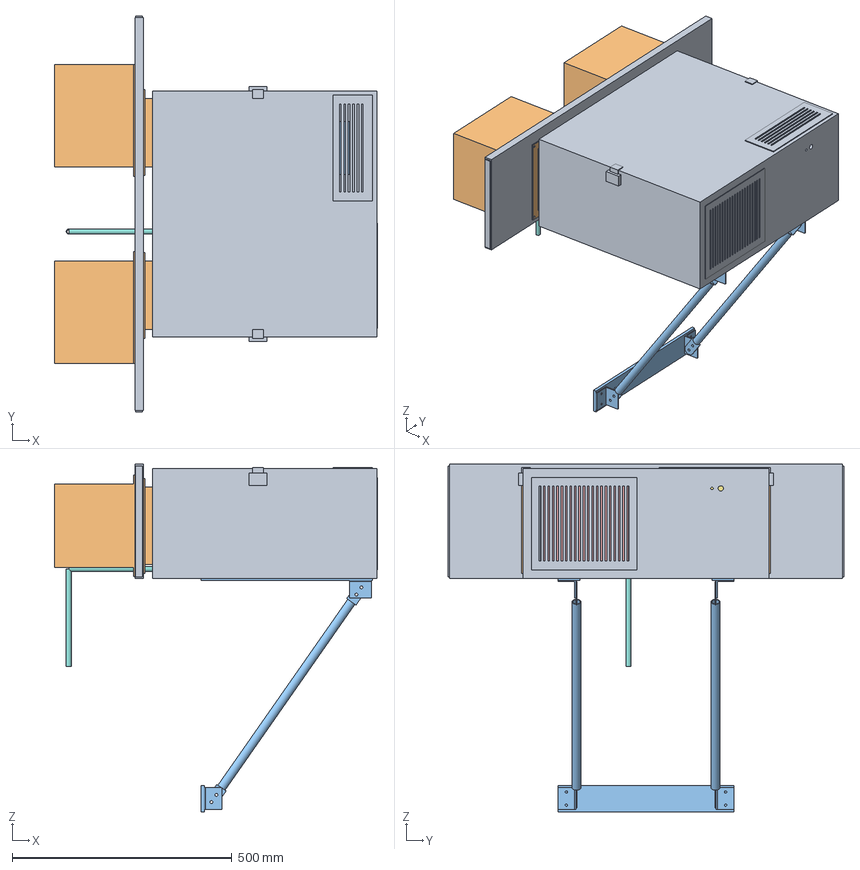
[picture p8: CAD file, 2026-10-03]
cad/step/breathebox-assembly.step
735.0 x 900.0 x 790.0 mm

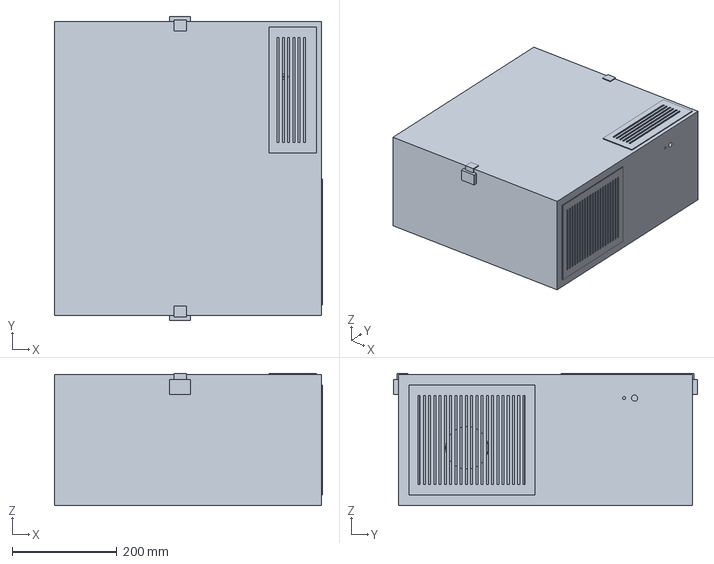
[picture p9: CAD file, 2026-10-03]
cad/step/breathebox-housing.step
512.0 x 580.0 x 252.0 mm

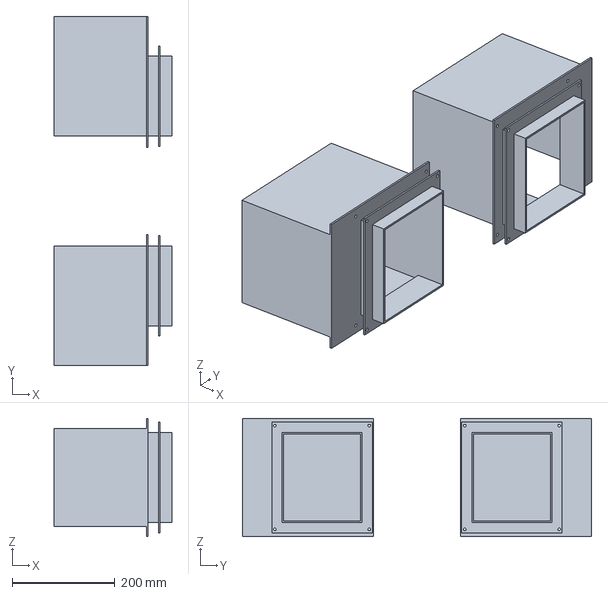
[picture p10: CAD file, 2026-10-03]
cad/step/breathebox-hoods.step
229.0 x 680.0 x 230.0 mm

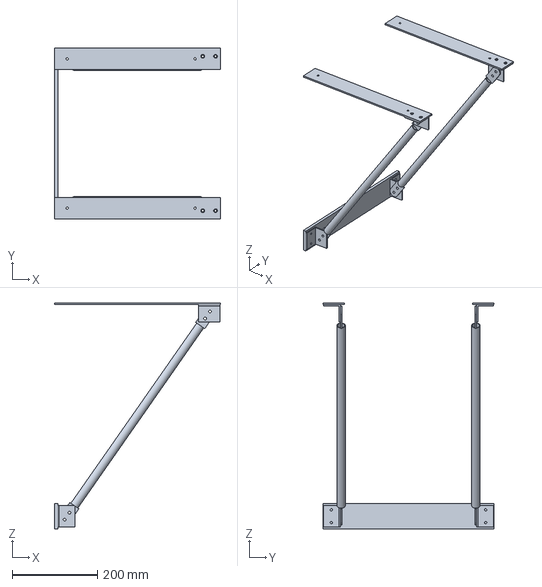
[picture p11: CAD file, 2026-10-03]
cad/step/breathebox-sill-bracket.step
390.0 x 400.0 x 530.0 mm

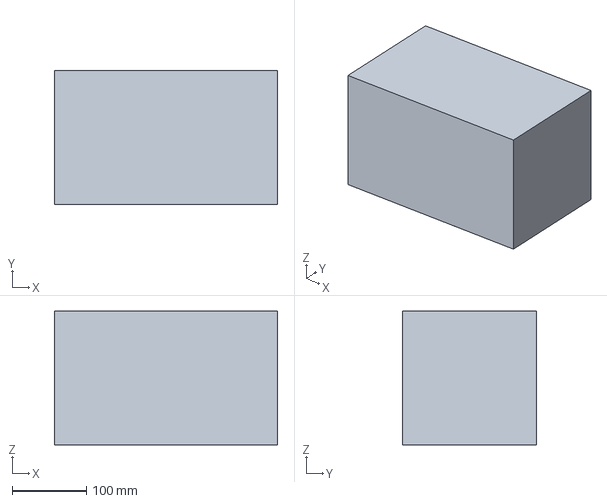
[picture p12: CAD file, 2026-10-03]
cad/step/breathebox-core.step
300.0 x 180.0 x 180.0 mm

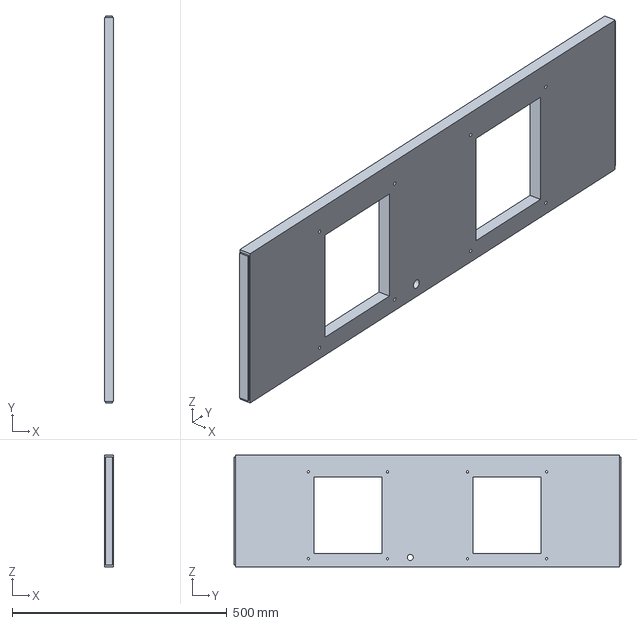
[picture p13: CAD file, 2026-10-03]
cad/step/breathebox-insert-panel.step
20.0 x 900.0 x 260.0 mm

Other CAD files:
cad/stl/breathebox-assembly.stl
cad/stl/breathebox-core.stl
cad/stl/breathebox-hoods.stl
cad/stl/breathebox-housing.stl
cad/stl/breathebox-insert-panel.stl
cad/stl/breathebox-sill-bracket.stl

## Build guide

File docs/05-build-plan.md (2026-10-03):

---
doc_id: BBX-BLD-001
title: BreatheBox prototype build plan
project: BreatheBox
doc_type: Build plan
version: "0.2"
status: Draft
date: '2026-10-02'
author: Amish Chadha
license: CERN-OHL-S-2.0
revisions:
  - version: "0.1"
    date: '2026-09-30'
    author: Amish Chadha
    change: First build plan, with pictures by component and step; design made constructable (BBX-DDR-003)
  - version: "0.2"
    date: '2026-10-02'
    author: Amish Chadha
    change: "Decisions of 2026-10-02 carried into the plan: wall foot at 400 mm with longer struts (sections 3.2, 3.12 and 3.13, step 13, Figures 4, 5 and 21 to 23), the bought sash jammer (section 3.17, step 15, Figure 1); design for construction accepted"
---

# BreatheBox prototype build plan

**Plan, not yet built.** How to build the first proof-of-concept prototype, component by component. Building and testing to it is TRL 4 work. Decisions still to be made are kept in the design decisions register ([docs/06-design-decisions.md](06-design-decisions.md)), not here.

## 1. What you are building

Figure 1. Every component, pulled apart and numbered in build order

*Figure 1. Every component pulled apart and numbered in build order. The window insert (17 to 19) is built on the bench and fitted to the window, and the sash jammer (21) wedged above the sash, before the unit goes on the sill.*

The prototype is one BreatheBox for a sash window: a lined box 510 x 560 x 250 mm that sits on the sill and holds a counterflow core, two small 24 V fans, two filters and a controller, plus a window insert that fills the gap under the raised lower sash and carries two outdoor hoods. Figure 1 shows the 21 components in the order you make or fit them. Fourteen are made in a home workshop: the housing boards and battens, the foam lining, the core frames, dividers and fan bulkhead, the filter seats, the condensate tray, the grilles and the lid; the bracket rails, struts and wall foot; and the insert panel, collars and hoods. The core, fans, filters, controller, adapter and sash jammer are bought. The work is cutting and gluing PVC foam board and foam, bending one PETG tray, cutting, drilling and bending aluminium bar, angle and tube, and plugging bought modules together at 24 V. The parts cost about $294 from the bill of materials.

> **Safety:** The unit runs only from a certified 24 V plug-in adapter; there is no mains wiring in it. Fan impellers can cut fingers: unplug the adapter before opening the lid. Do not use the unit in a room with an open-flued or unflued fuel-burning appliance, or in a room whose door seals airtight. Fit the window insert from inside only; never work outside a window above ground level. PVC cement and contact adhesive give off solvent fumes, and a heat gun on PETG gives off fumes: work in a ventilated space. Cut aluminium edges are sharp: deburr everything.

## 2. What changed to make it buildable

The concept showed what the unit does; most of its parts could not be made, fixed or sealed as drawn. Each change below keeps what the unit does, and all of them are recorded in decision record BBX-DDR-003, which Amish accepted on 2 October 2026.

*Table 1. Changes from the concept.*

| Component | The concept had | The buildable design has | Why |
| --- | --- | --- | --- |
| Housing | One solid shell with no joints and no separate lid | Six boards glued and screwed into corner battens, a foam lining, and a lid with a foam plug and two latches (Figures 2, 3, 19 and 20) | It can be made, and the lid lifts off for filter changes |
| Air paths | Air could pass round the core's sides; the dividers stopped short of floor and lid | Two core frames and three full-height dividers (Figures 7 to 9) | Four sealed chambers, with the core the only way between them |
| Fans | Each fan's inlet and outlet in one open chamber | A fan bulkhead: supply fan on its room side, exhaust fan on its core side, both still at the room end (Figures 10 and 11) | Each fan draws from one chamber and blows into the next |
| Core | Floating 8 mm above the tray | Four pads in a tray between the core frames; a foam hold-down under the lid (Figures 8 and 16) | The core is held, water runs under it, and it lifts straight out |
| Filters | Floating, with no seat | Strip seats with lips and stops; foam blocks under the lid (Figures 12, 13 and 13a) | The air presses each filter onto its seat |
| Controller | Floating above a divider, its sensor across two air streams | On the divider in the room-air intake; status light and button behind the room face (Figure 14) | The sensor reads room air |
| Grilles | None in the parts list | Two slotted aluminium grilles; the top opening moved over the supply fan (Figure 18) | Fingers cannot reach a fan |
| Collars and hoods | No fixing to the panel or the housing | Flanged collars and hood back plates bolted through the panel; the collar slides into the housing (Figures 25 to 27) | The insert is one rigid assembly and the hoods cannot fall |
| Sill bracket | A plate with tube struts touching it, no joints; a foot 650 mm up | Two rails bolted under the housing; flattened struts with two bolts at each end on angle cleats; a padded foot 400 mm up (Figures 4, 5 and 21 to 23) | The bracket is rigid and the unit needs half the sill friction to stay put |
| Drain | Through a divider, starting above the tray floor | From the tray's end wall at floor level, on the exhaust side (Figures 16 and 17) | No standing water; no divider pierced |
| Power entry | Beside the core, in a closed space | A cable gland in the right side wall (Figure 14) | The cable never crosses the core seal |

## 3. Making the components

Make and check each component before the assembly step that needs it. Sizes are in millimetres. "Left" and "right" are as seen standing in the room, looking at the unit's room face; the right side is the supply side. "Up" is from the bottom edge of the part. Workshop tolerance is 1 mm on board and foam and 0.5 mm on aluminium unless a step says otherwise; drawings do not carry tolerances before TRL 4.

### 3.1 Housing boards and corner battens

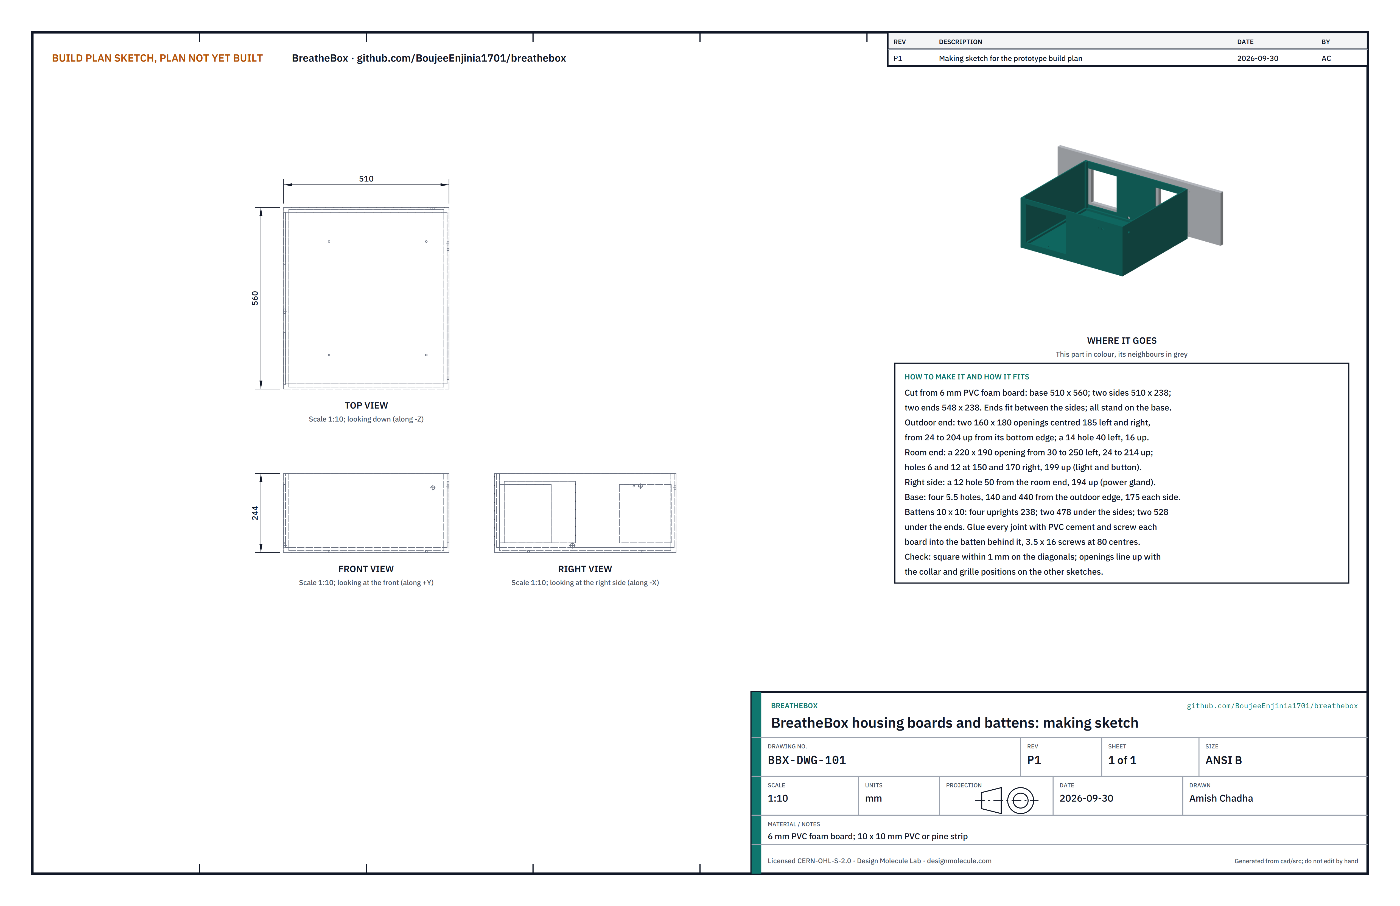
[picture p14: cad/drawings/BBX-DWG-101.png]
Figure 2. Making sketch of the housing boards and battens


*Figure 2. Housing boards and battens making sketch (BBX-DWG-101).*

**What it is and what it is made from.** The outer box, without its lid: a base, two sides and two ends of 6 mm PVC foam board, joined over 10 x 10 mm strip battens in the corners. Fire-retardant board where you can get it.

**How to make it.**

1. Cut the boards with a sharp knife against a steel rule (several light passes): base 510 x 560; two sides 510 x 238; two ends 548 x 238.
2. Outdoor end: two openings 160 x 180, centred 185 left and 185 right of the centre line, from 24 to 204 up; a 14 hole 40 left of centre, 16 up (drain).
3. Room end: one opening 220 x 190, from 30 to 250 left of centre and 24 to 214 up (exhaust grille); a 6 hole at 150 right and a 12 hole at 170 right, both 199 up (status light and button).
4. Right side: a 12 hole 50 from the room end, 194 up (power cable gland).
5. Base: four 5.5 holes, 140 and 440 from the outdoor edge, 175 each side of the centre line (bracket rail bolts).
6. Cut the battens from 10 x 10 strip: four uprights 238 long, two 478 long (under the sides), two 528 long (under the ends).
7. On a flat bench, glue the bottom battens to the base 6 in from its edges, then the sides onto the base against their battens, then the ends between the sides, then the four uprights in the corners. Use PVC cement, and screw each board into the batten behind it with 3.5 x 16 stainless screws at about 80 centres, pilot drilled 2.5.

**How it fits the parts next to it.**

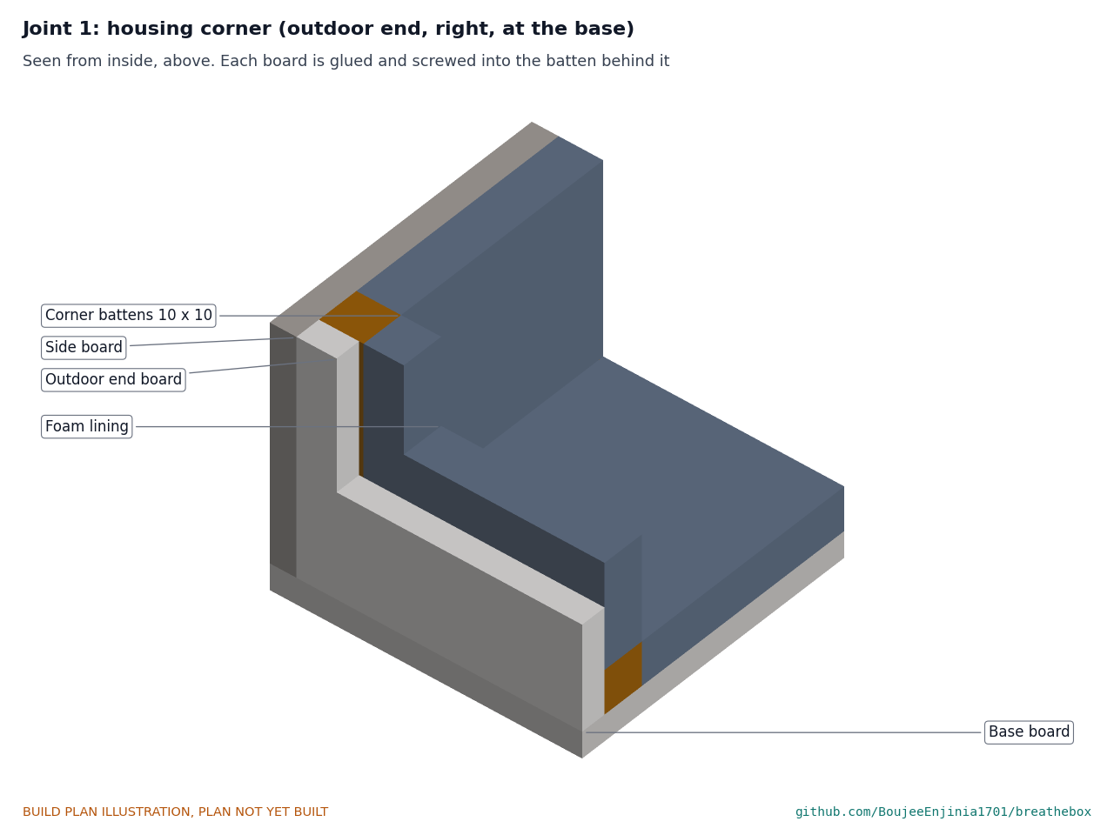
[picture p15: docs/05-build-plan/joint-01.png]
Figure 3. Joint 1: housing corner


*Figure 3. Each board is glued and screwed into the batten behind it; the lining fills the space between the battens, so the inside is smooth.*

The ends fit between the sides and everything stands on the base. The battens lie inside the 10 mm lining's thickness, so the lining butts against them (section 3.3).

**Check before moving on.** The box is square: its two diagonals across the top differ by 1 mm or less. The collar openings are 370 apart, centre to centre.

### 3.2 Bracket rails with their top cleats

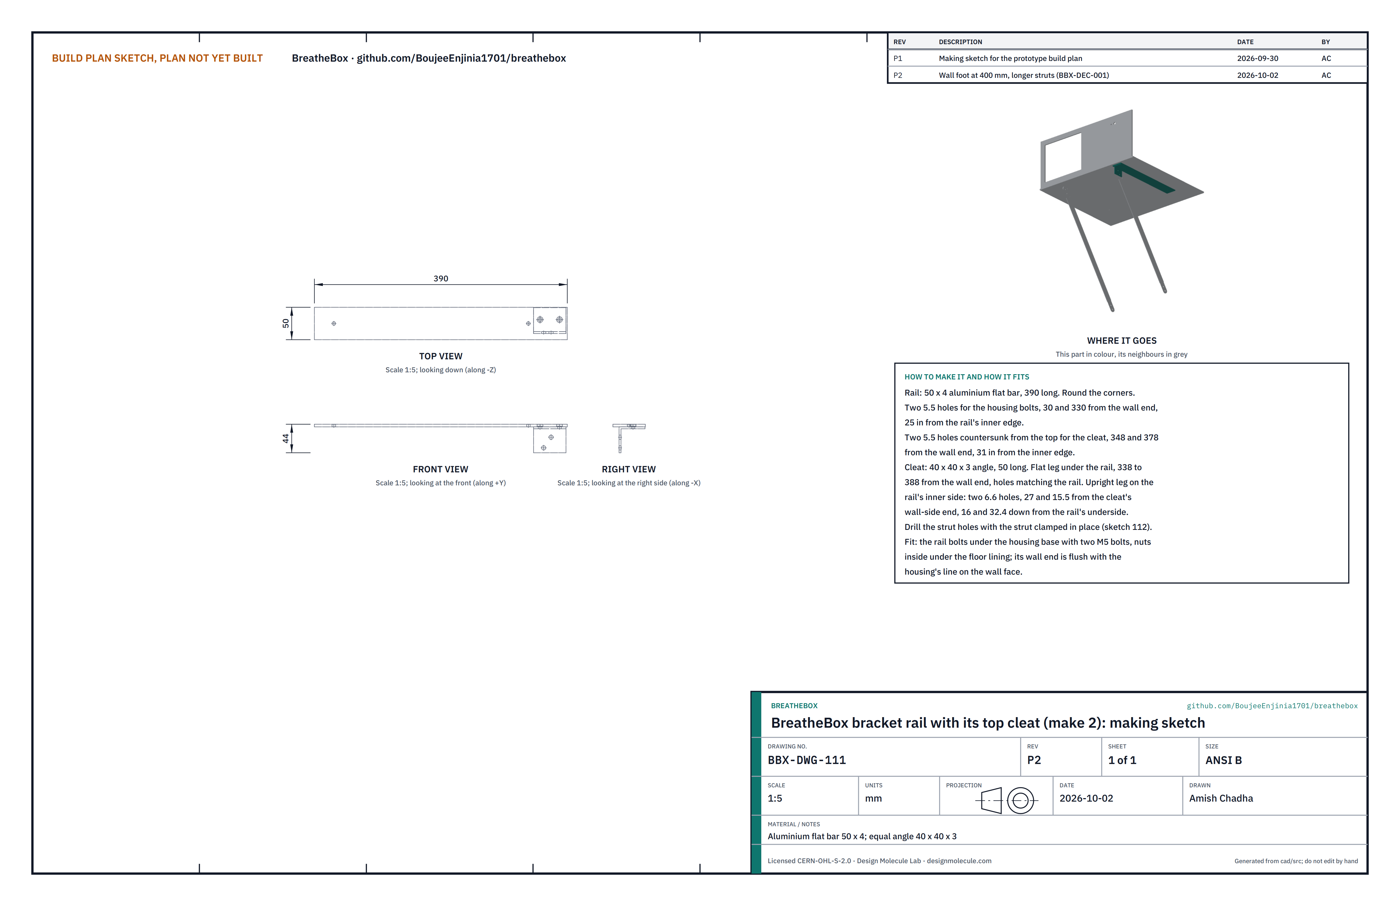
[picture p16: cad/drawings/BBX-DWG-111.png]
Figure 4. Making sketch of the bracket rail and top cleat


*Figure 4. Bracket rail with its top cleat making sketch (BBX-DWG-111). Make two, a left and a right.*

**What it is and what it is made from.** Two rails bolted under the housing base; at the room end of each, an angle cleat carries the top of a strut. Aluminium flat bar 50 x 4 and equal angle 40 x 40 x 3, 6060 or 6063 class.

**How to make it.**

1. Cut two rails 390 long; round the corners and deburr.
2. Drill two 5.5 holes in each, 30 and 330 from the wall end, 25 in from the inner long edge, for the housing bolts.
3. Drill two 5.5 holes 348 and 378 from the wall end, 31 in from the inner edge, and countersink them from the top so M5 countersunk screws sit flush.
4. Cut two cleats 50 long from the angle. Lay the flat leg under the rail from 338 to 388 from the wall end, upright leg on the inner side, and drill through the rail holes.
5. Leave the upright leg's strut holes until the struts are made (section 3.12); mark them now at 27 and 15.5 from the cleat's wall-side end, 16 and 32.4 down from the rail's underside.
6. Fit each cleat with two M5 countersunk screws and nyloc nuts.

**How it fits the parts next to it.**

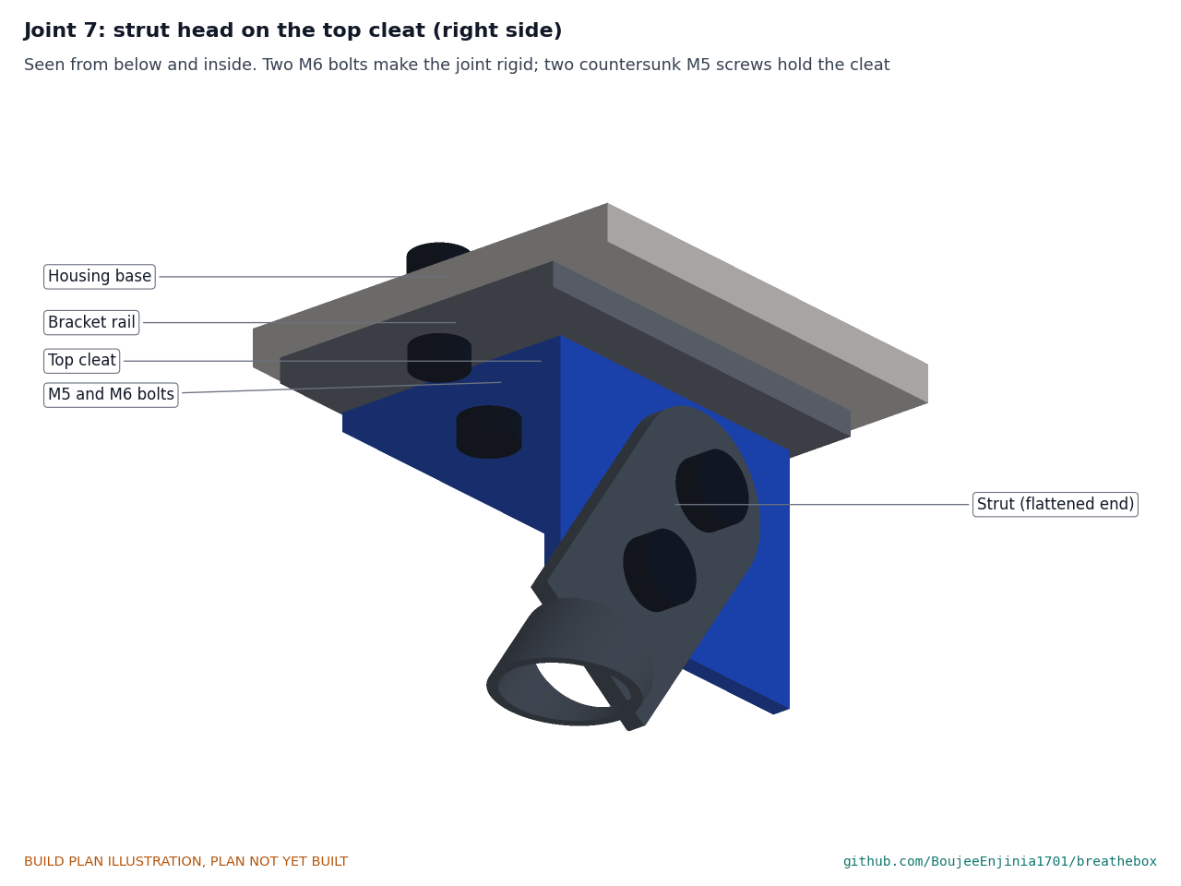
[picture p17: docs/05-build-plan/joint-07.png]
Figure 5. Joint 7: strut head on the top cleat


*Figure 5. The strut's flattened end bolts to the cleat's upright leg with two M6 bolts, so the joint cannot turn.*

The rails lie flat under the housing base, 150 to 200 out from the centre line on each side, with their wall ends at the line where the base meets the wall face (110 in from the outdoor edge of the base). Two M5 bolts each, heads under the rail, nyloc nuts and penny washers inside the box. The nuts go on before the lining, which has relief holes over them.

**Check before moving on.** The rails are parallel and both stand 4 below the base all along.

### 3.3 Foam lining

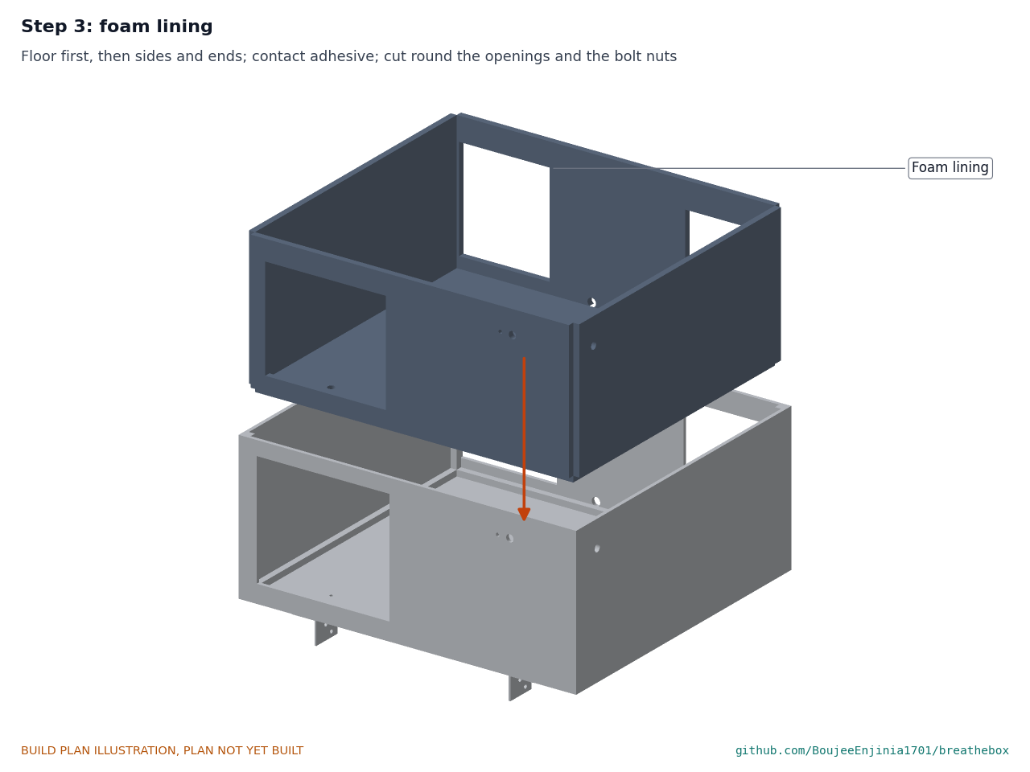
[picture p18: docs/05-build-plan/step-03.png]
Figure 6. Step 3 picture: the lining going in


*Figure 6. The lining covers the floor, sides and ends inside the battens.*

**What it is and what it is made from.** 10 mm closed-cell foam sheet (self-adhesive, or plain with contact adhesive), fire-retardant grade where available. It insulates the box and quietens the fans.

**How to make it.**

1. Cut the floor piece 478 x 528, with four 12 relief holes over the bracket bolt nuts: 124 and 424 from its outdoor edge, 175 each side of centre.
2. Cut two side pieces 478 x 228. The right one has a 12 hole 34 from its room end, 184 up, for the cable gland.
3. Cut two end pieces 528 x 228.
4. Outdoor end piece: a 140 x 160 opening from 115 to 255 right of centre and 24 to 184 up (5 smaller all round than the collar bore, so it makes a lip behind the supply filter); a 150 x 170 opening from 110 to 260 left of centre and 19 to 189 up; a 14 hole 40 left of centre, 6 up.
5. Room end piece: a 200 x 170 opening from 40 to 240 left of centre and 24 to 194 up (a 10 lip behind the exhaust filter); holes 6 and 12 at 150 and 170 right, 189 up.
6. Lay the floor first, then the sides, then the ends, each pressed into place against the battens.

**How it fits the parts next to it.** It lies flat on the boards and butts against the battens; the openings line up with those in the boards, with the lips standing in from the supply opening and the exhaust grille opening.

**Check before moving on.** The inside measures 478 x 528 at the floor, and the lips are even all round their openings.

### 3.4 Core frames

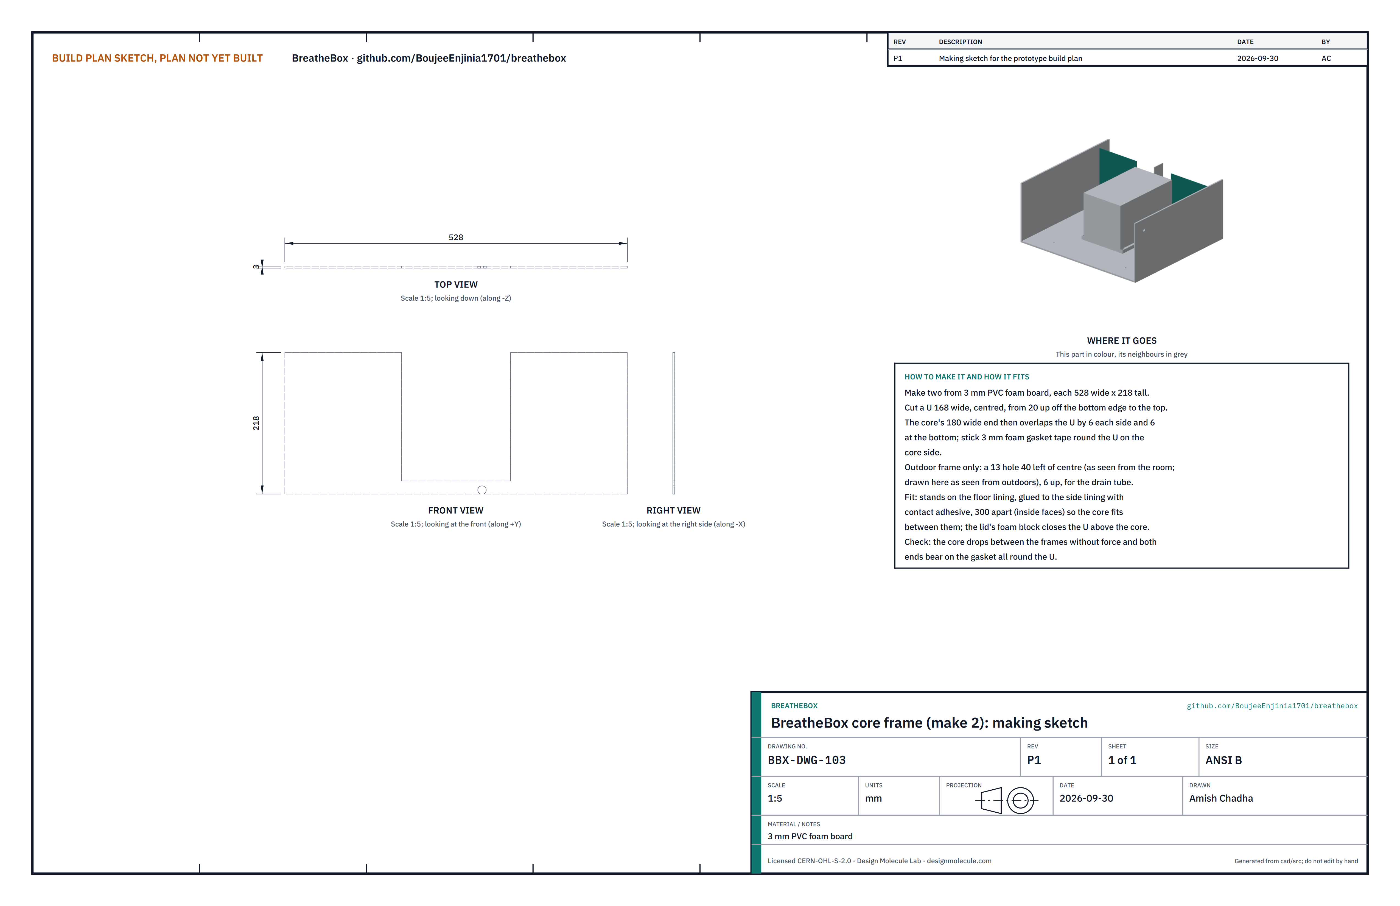
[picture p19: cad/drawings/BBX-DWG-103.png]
Figure 7. Making sketch of the core frame


*Figure 7. Core frame making sketch (BBX-DWG-103). Make two.*

**What it is and what it is made from.** Two partitions across the box, one at each end of the core, with a U cut that the core's end bears on. 3 mm PVC foam board.

**How to make it.**

1. Cut two pieces 528 wide x 218 tall.
2. Cut a U 168 wide, centred, from 20 up to the top edge.
3. Outdoor frame only: a 13 hole 40 left of centre, 6 up, for the drain tube.
4. Stick 3 mm foam gasket tape round the U on the face that will touch the core.

**How it fits the parts next to it.**

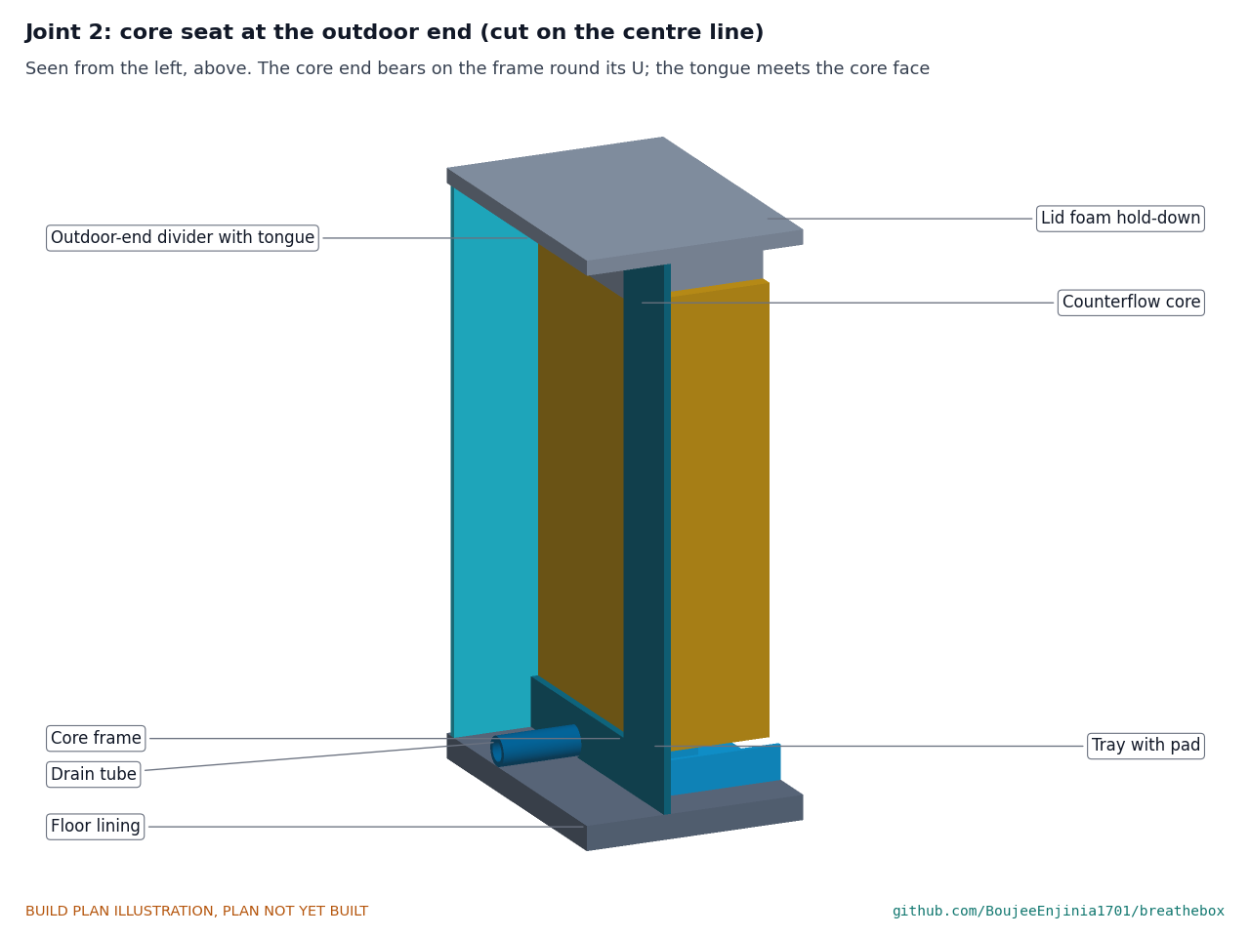
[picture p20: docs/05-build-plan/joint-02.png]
Figure 8. Joint 2: the core seat at the outdoor end


*Figure 8. The core's end bears on the frame round its U, through the gasket; the divider's tongue meets the core face; the lid's foam block closes the U above the core.*

Each frame stands on the floor lining and is glued to the side linings with contact adhesive. Their core faces are 300 apart, the core's length; the outdoor frame's core face is 70 in from the outside of the outdoor end board, which leaves 51 of clear space between the frame and the end lining. The tray sits between the frames (section 3.9).

**Check before moving on.** The core drops between the frames without force and bears on the gasket at both ends.

### 3.5 Dividers

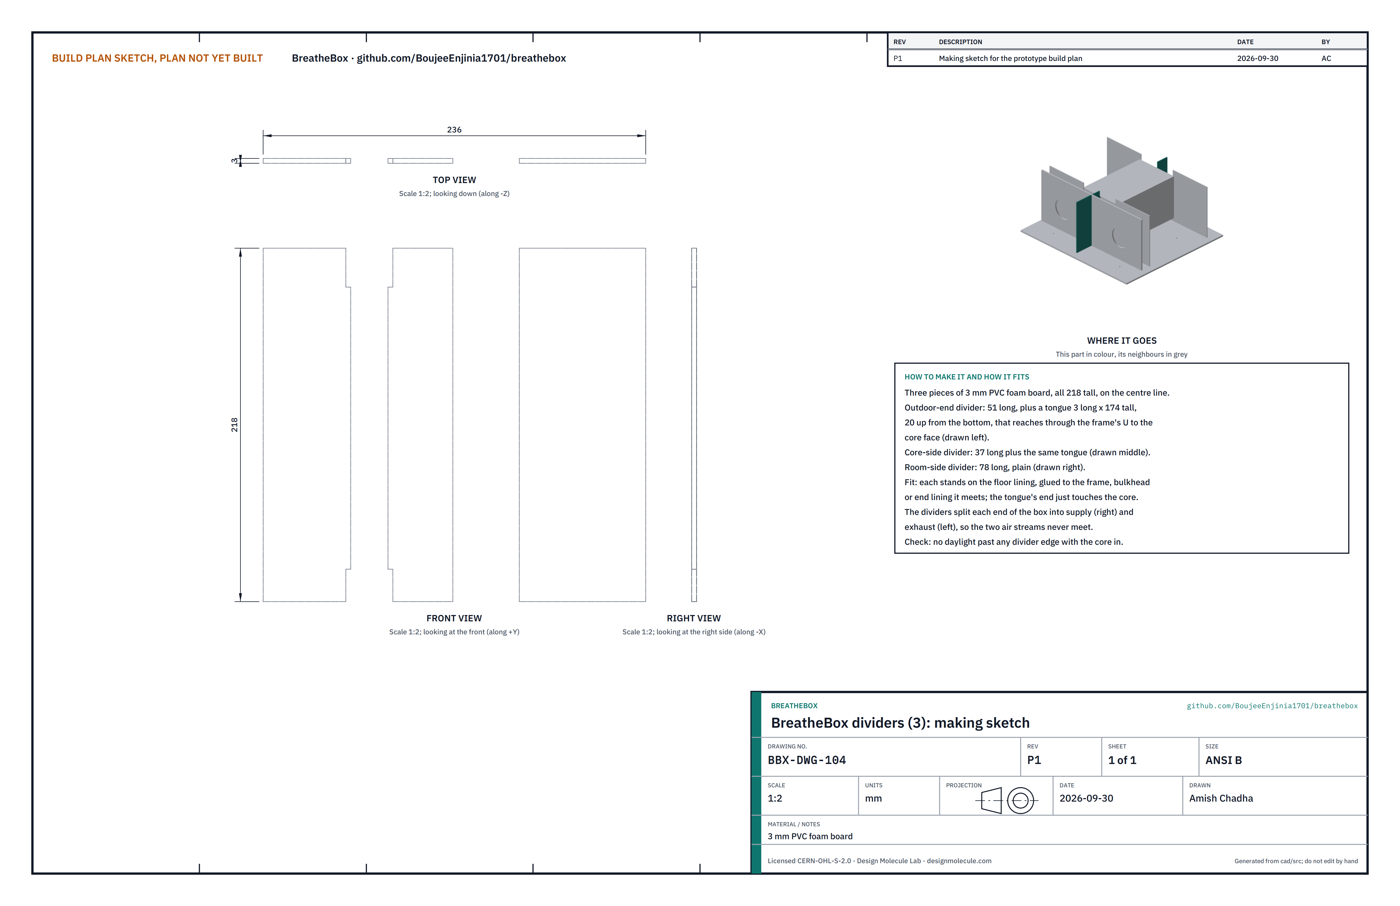
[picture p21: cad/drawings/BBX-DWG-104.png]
Figure 9. Making sketch of the dividers


*Figure 9. Dividers making sketch (BBX-DWG-104): outdoor-end divider (left), core-side divider (middle), room-side divider (right).*

**What it is and what it is made from.** Three partitions on the centre line that split each end of the box into a supply side (right) and an exhaust side (left). 3 mm PVC foam board.

**How to make it.**

1. Outdoor-end divider: 51 long x 218 tall, with a tongue 3 long x 174 tall starting 20 up, on the core end.
2. Core-side divider: 37 long x 218 tall, with the same tongue on its core end.
3. Room-side divider: 78 long x 218 tall.

**How it fits the parts next to it.** Each stands on the floor lining on the centre line. The outdoor-end divider runs from the outdoor end lining to the core frame; its tongue passes through the frame's U and just touches the core's end. The core-side divider runs from the room-end core frame to the fan bulkhead, its tongue likewise touching the core. The room-side divider runs from the bulkhead to the room end lining. Glue each to what it meets.

**Check before moving on.** With the core in, no daylight shows past any divider edge.

### 3.6 Fan bulkhead

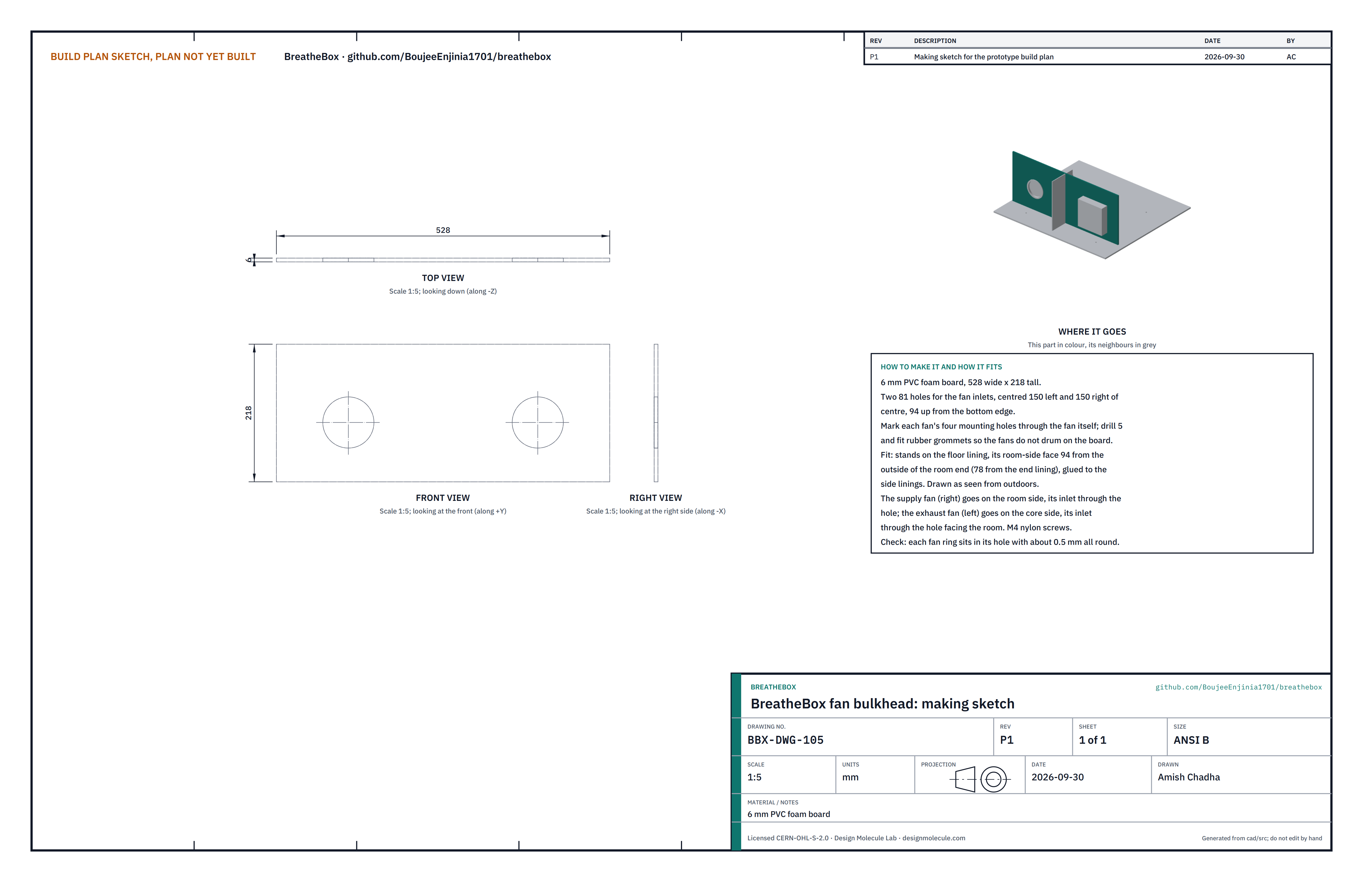
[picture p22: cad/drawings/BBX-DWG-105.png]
Figure 10. Making sketch of the fan bulkhead


*Figure 10. Fan bulkhead making sketch (BBX-DWG-105), drawn as seen from outdoors.*

**What it is and what it is made from.** A partition across the room end of the box that carries both fans. 6 mm PVC foam board.

**How to make it.**

1. Cut 528 wide x 218 tall.
2. Cut two 81 holes for the fan inlets, centred 150 left and 150 right of centre, 94 up.
3. Hold each fan in place and mark its four mounting holes through the fan; drill 5 and fit rubber grommets.

**How it fits the parts next to it.**

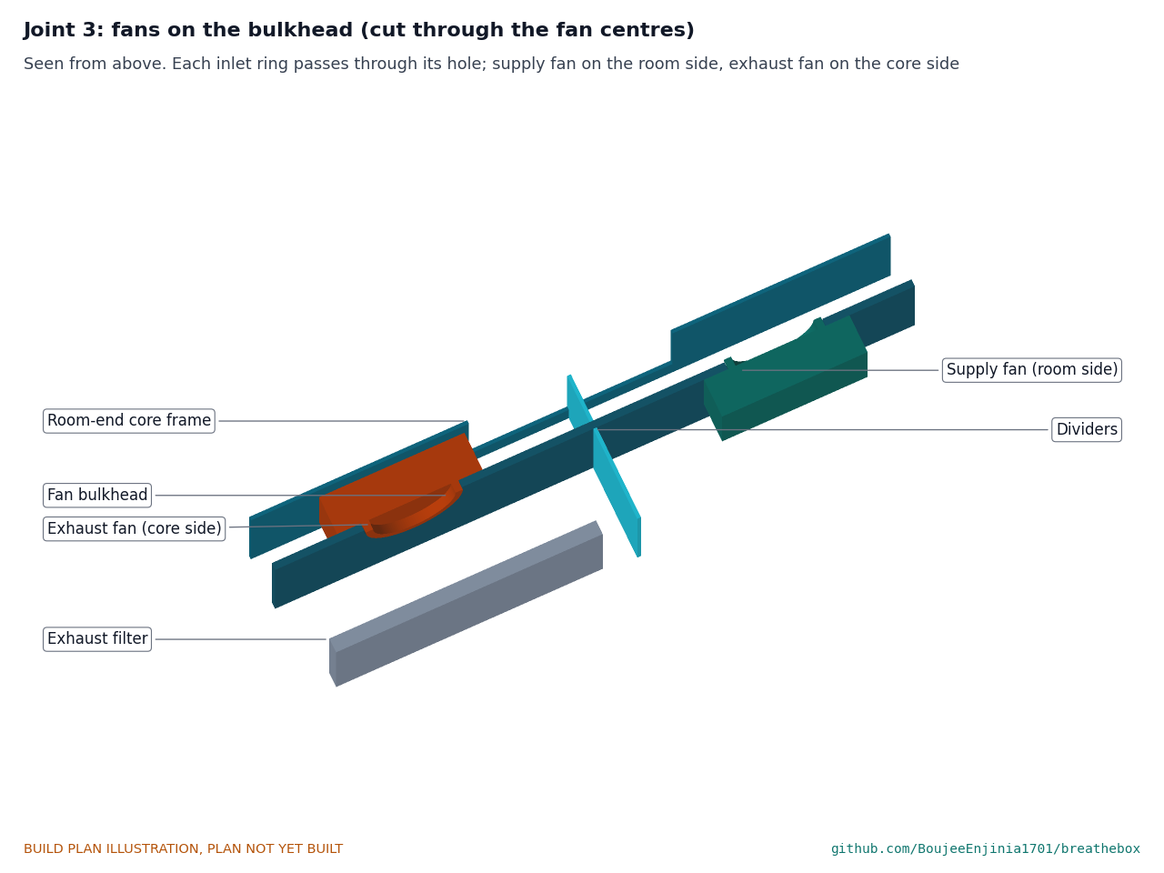
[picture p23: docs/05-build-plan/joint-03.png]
Figure 11. Joint 3: the fans on the bulkhead


*Figure 11. Seen from above, cut through the fan centres: the supply fan sits on the room side with its inlet through the bulkhead; the exhaust fan sits on the core side with its inlet facing the room.*

The bulkhead stands on the floor lining with its room-side face 94 in from the outside of the room end board, glued to the side linings. The exhaust fan sits 2 clear of the room-end core frame.

**Check before moving on.** Each fan's inlet ring sits in its hole with about 0.5 all round.

### 3.7 Filter seats

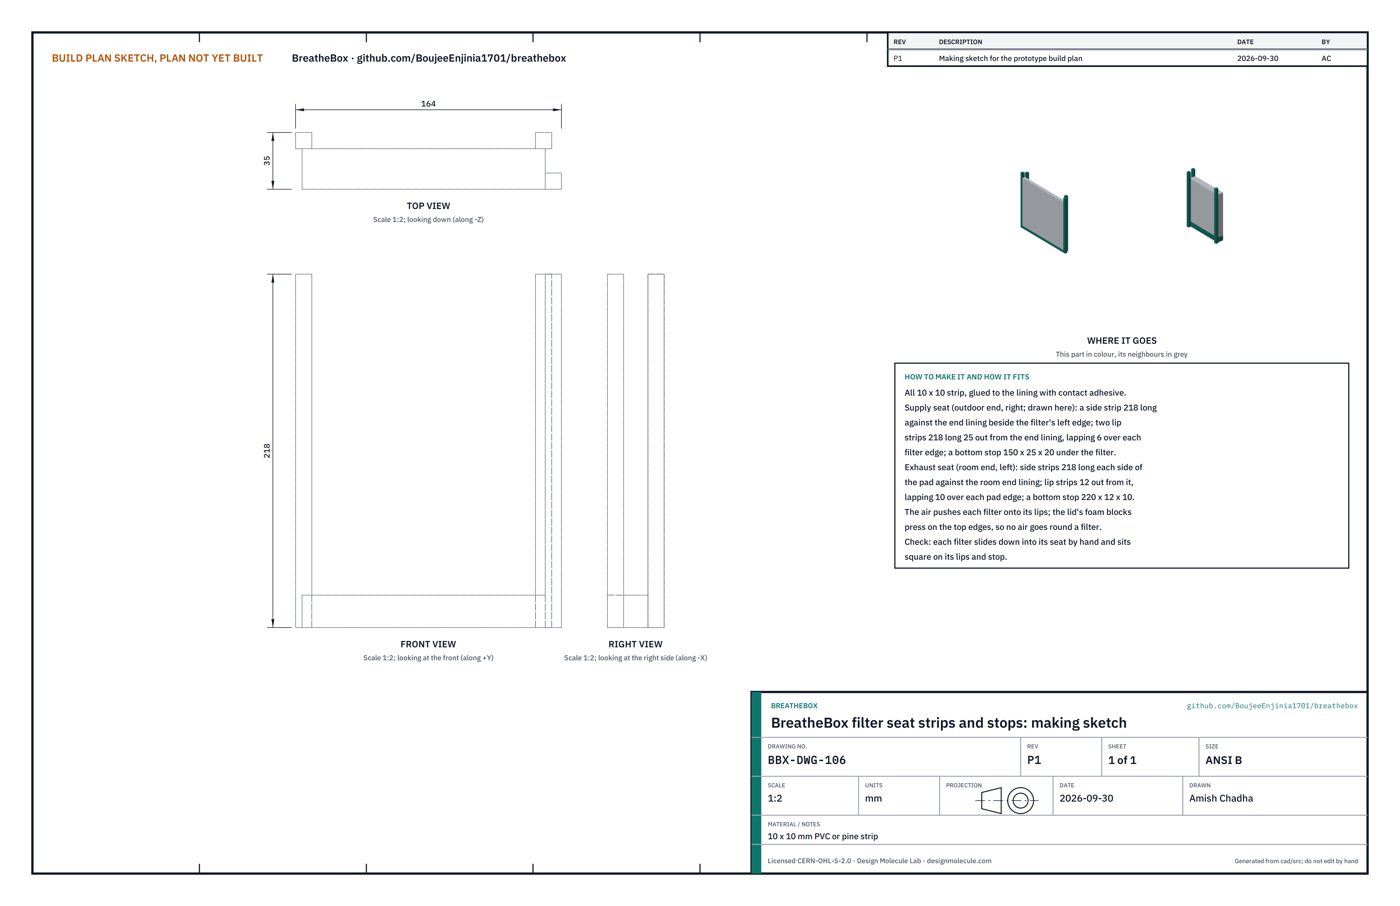
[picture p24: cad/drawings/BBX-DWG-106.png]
Figure 12. Making sketch of the filter seat strips and stops


*Figure 12. Filter seat making sketch (BBX-DWG-106); the supply seat is drawn.*

**What it is and what it is made from.** Short lengths of 10 x 10 strip that hold each filter in place: side strips beside the filter, lip strips that lap over its downstream face, and a stop under it.

**How to make it.**

1. Supply seat (outdoor end, right): a side strip 218 long against the end lining beside the filter's left edge; two lip strips 218 long, 25 out from the end lining, lapping 6 over each filter edge (the right one against the side lining); a bottom stop 150 x 25 x 20 under the filter (two strips stacked).
2. Exhaust seat (room end, left): side strips 218 long each side of the pad against the room end lining; two lip strips 218 long, 12 out from the lining, lapping 10 over each pad edge; a bottom stop 220 x 12 x 10.
3. Glue them to the lining with contact adhesive, trying each filter in its seat before the glue sets.

**How it fits the parts next to it.**

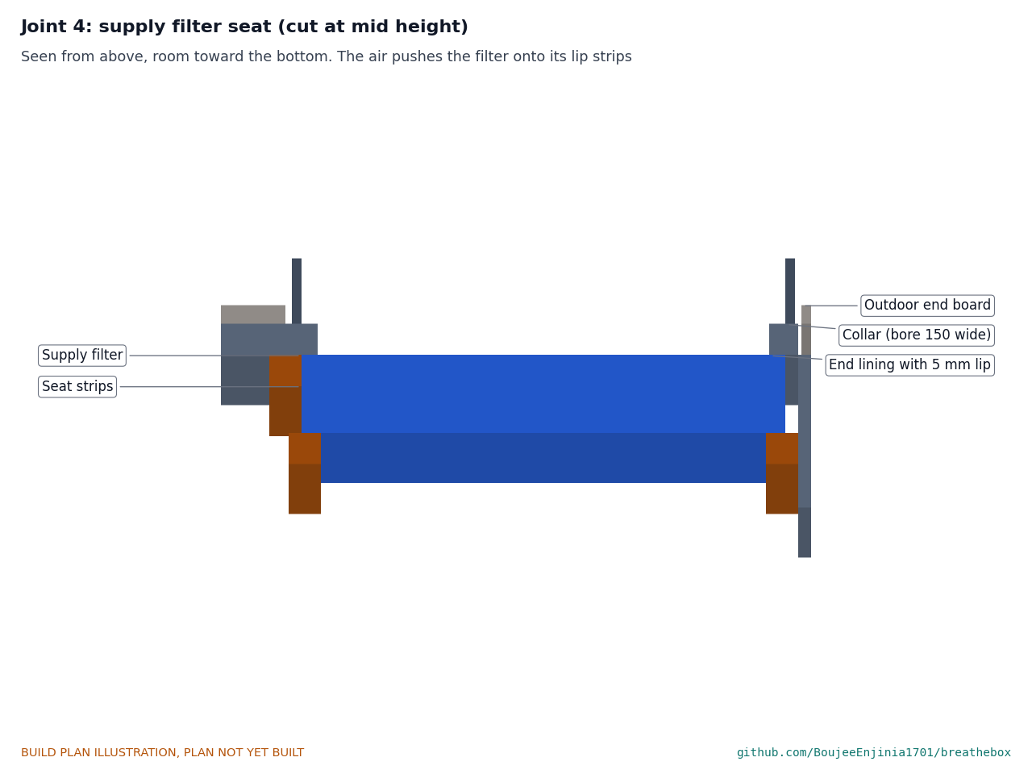
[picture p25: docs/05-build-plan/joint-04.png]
Figure 13. Joint 4: the supply filter seat


*Figure 13. Seen from above, room toward the bottom: the air from the collar pushes the filter onto its lip strips; the lining's lip seals behind its frame.*

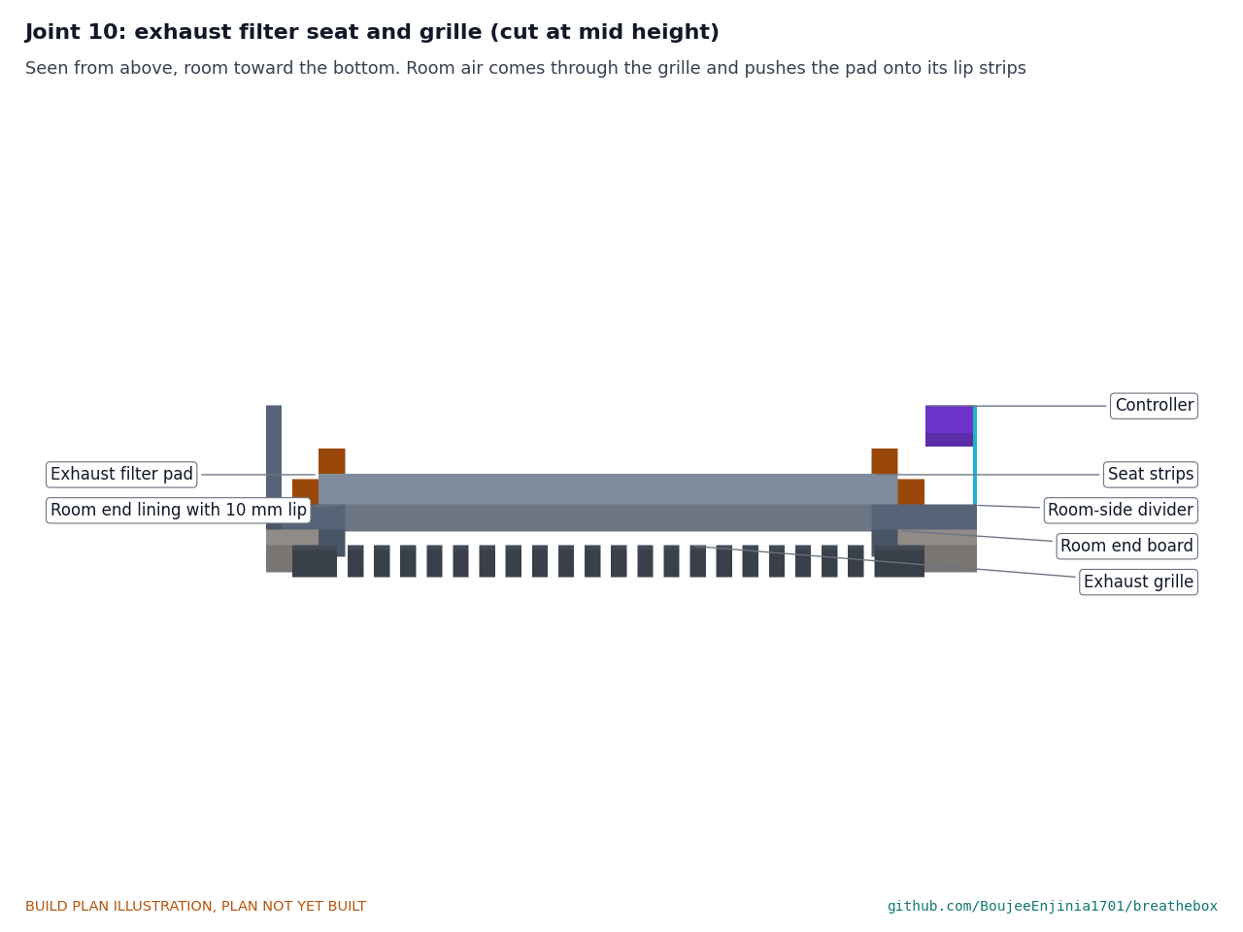
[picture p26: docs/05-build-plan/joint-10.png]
Figure 13a. Joint 10: the exhaust filter seat and grille


*Figure 13a. Room air comes through the grille and the lining's 10 mm lip, and pushes the pad onto its lip strips.*

The air pushes each filter onto its lips, and the lid's foam blocks press on the top edges, so no air goes round a filter. With the lid off, each filter lifts straight out by hand.

**Check before moving on.** Each filter slides down into its seat and sits square on its lips and stop.

### 3.8 Controls and power entry

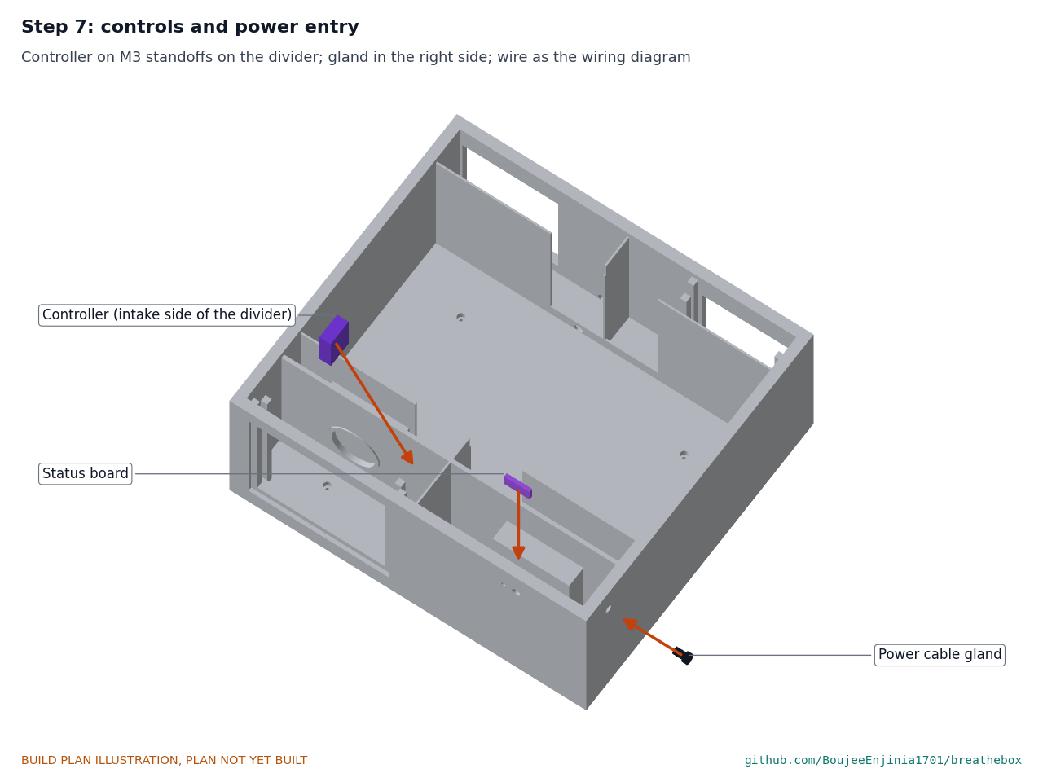
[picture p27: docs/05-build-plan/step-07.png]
Figure 14. Step 7 picture: controls and power entry


*Figure 14. Controller on the room-side divider, in the room-air intake; status board behind the room face; cable gland in the right side.*

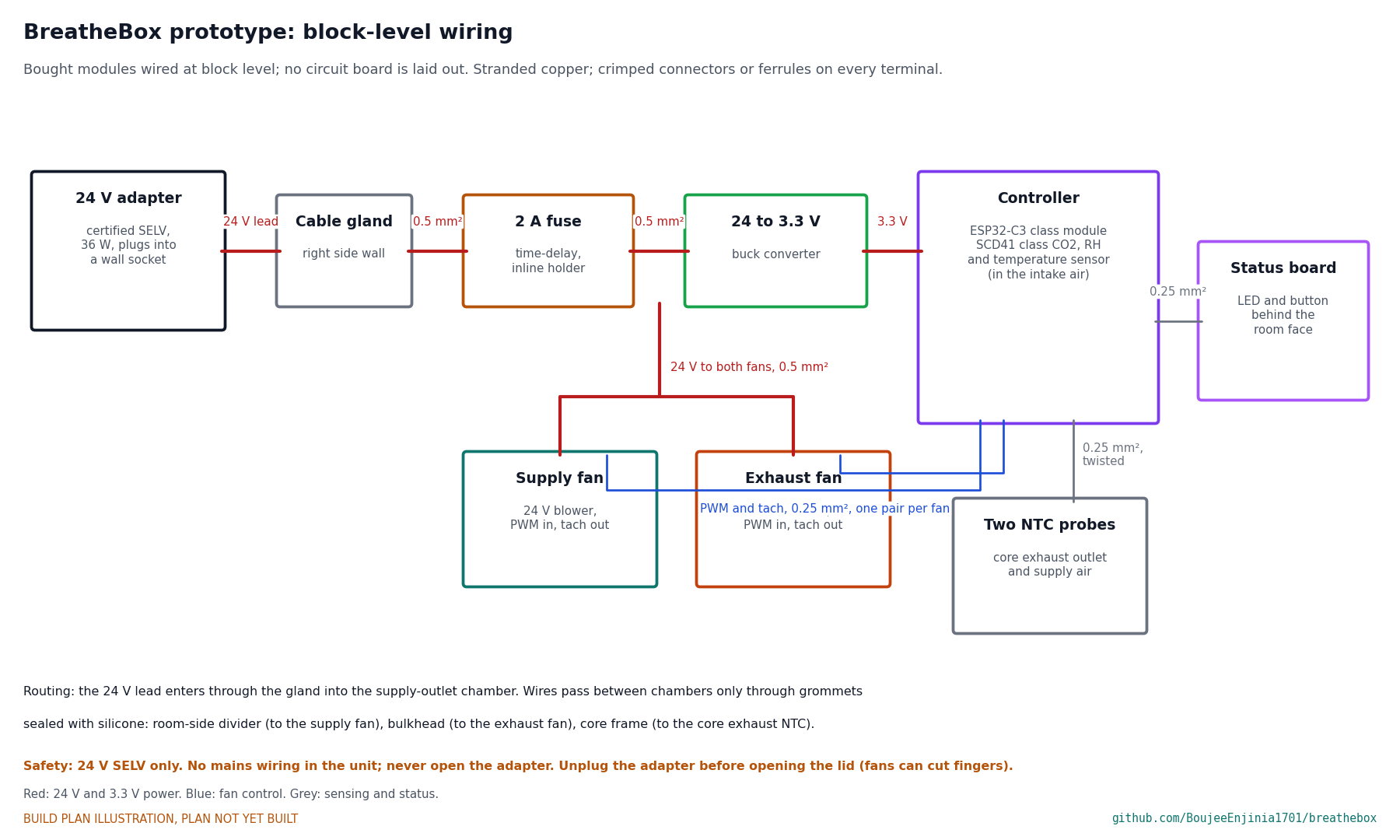
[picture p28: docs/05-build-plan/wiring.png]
Figure 15. Block-level wiring


*Figure 15. Block-level wiring with wire sizes. No circuit board is laid out at this stage; bought modules are wired together.*

**What it is and what it is made from.** Bought parts: an ESP32-C3 class controller module, a Sensirion SCD41 class CO2, humidity and temperature sensor, a 24 to 3.3 V buck converter, two NTC probes, a status LED and a push button on a small board, an M12 cable gland, and an inline 2 A time-delay fuse holder.

**How to make it.**

1. Mount the controller and sensor on a small carrier board on M3 nylon standoffs on the left face of the room-side divider, 10 to 50 from the bulkhead and 144 to 204 up from the floor lining.
2. Mount the LED and button on a small board behind the two holes in the room end, so they show through.
3. Fit the cable gland in the right side wall; bring the adapter cable in through it, with the fuse holder inside.
4. Wire as Figure 15. Pass wires between chambers only through rubber grommets, sealed with silicone: through the room-side divider to the supply fan, through the bulkhead to the exhaust fan, and through the outdoor core frame to the core exhaust NTC, which is taped at the core's exhaust outlet (outdoor end, left half).

**How it fits the parts next to it.** The sensor sits in the air coming in from the room, behind the exhaust filter, as the concept requires.

**Check before moving on.** Every wire is continuous end to end and labelled; with the fuse out, the 24 V input reads open to the case.

### 3.9 Condensate tray and drain tube

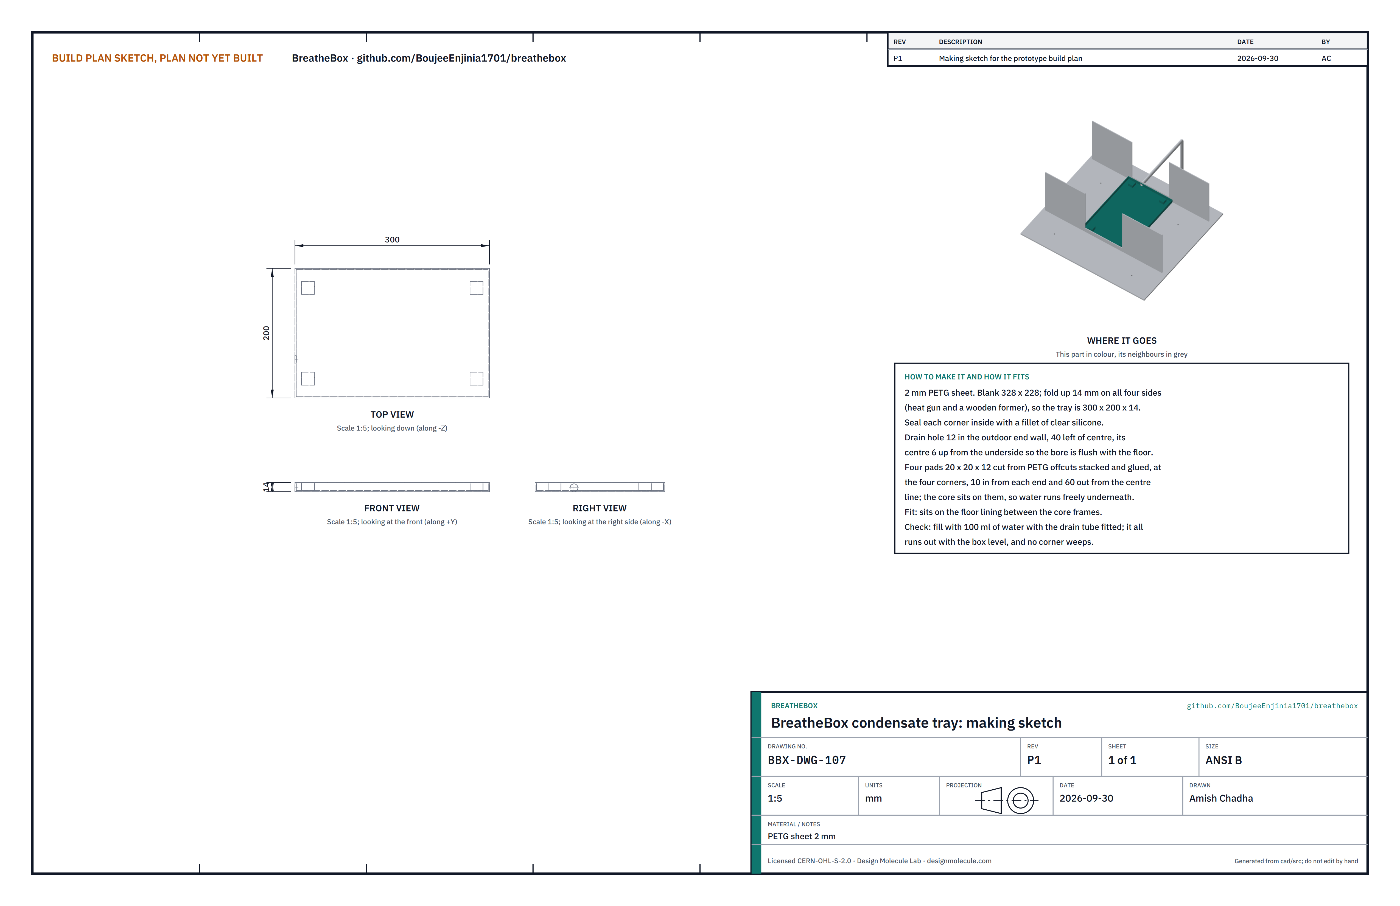
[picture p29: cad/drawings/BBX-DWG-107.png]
Figure 16. Making sketch of the condensate tray


*Figure 16. Condensate tray making sketch (BBX-DWG-107).*

**What it is and what it is made from.** A shallow tray under the core that catches condensate and drains it outdoors through a silicone tube. 2 mm PETG sheet; 12 x 8 silicone tube.

**How to make it.**

1. Cut a PETG blank 328 x 228. Fold up 14 on all four sides with a heat gun over a wooden former, so the tray is 300 x 200 x 14. Seal each corner inside with clear silicone.
2. Drill a 12 hole in one short end wall, 40 left of centre, its centre 6 up from the underside, so the tube's bore is flush with the tray floor.
3. Cut four pads 20 x 20 x 12 (stacked PETG offcuts) and glue them in the corners, 10 in from each end and 60 out from the centre line.
4. Cut the tube about 450 long; push one end through the tray hole flush with the inside face and seal it.

**How it fits the parts next to it.**

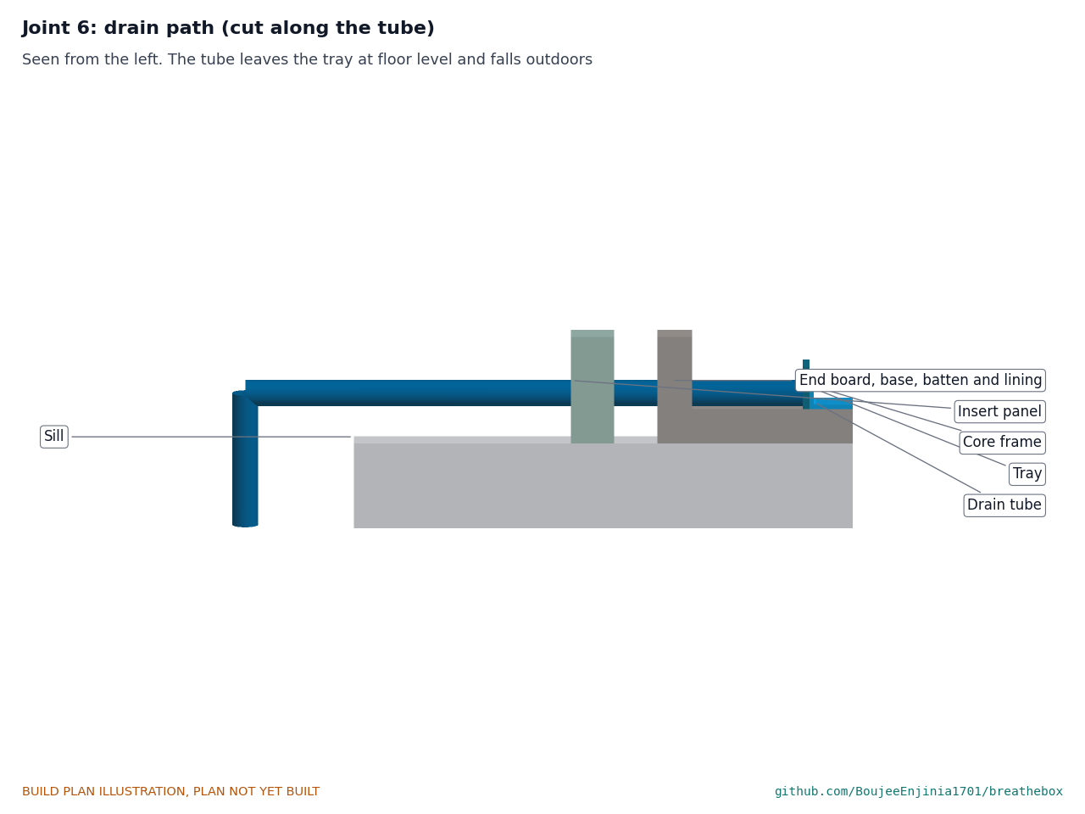
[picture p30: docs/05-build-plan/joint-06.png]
Figure 17. Joint 6: the drain path


*Figure 17. Seen from the left: the tube leaves the tray at floor level, passes through the core frame, the end wall and the insert panel, and turns down outdoors.*

The tray sits on the floor lining between the core frames; the core sits on its pads. The tube runs through the outdoor core frame, the outdoor end wall and the insert panel, and hangs down the outside wall, falling all the way.

**Check before moving on.** With the box level, 100 ml of water poured into the tray all runs out of the tube, and no corner weeps.

### 3.10 Grilles

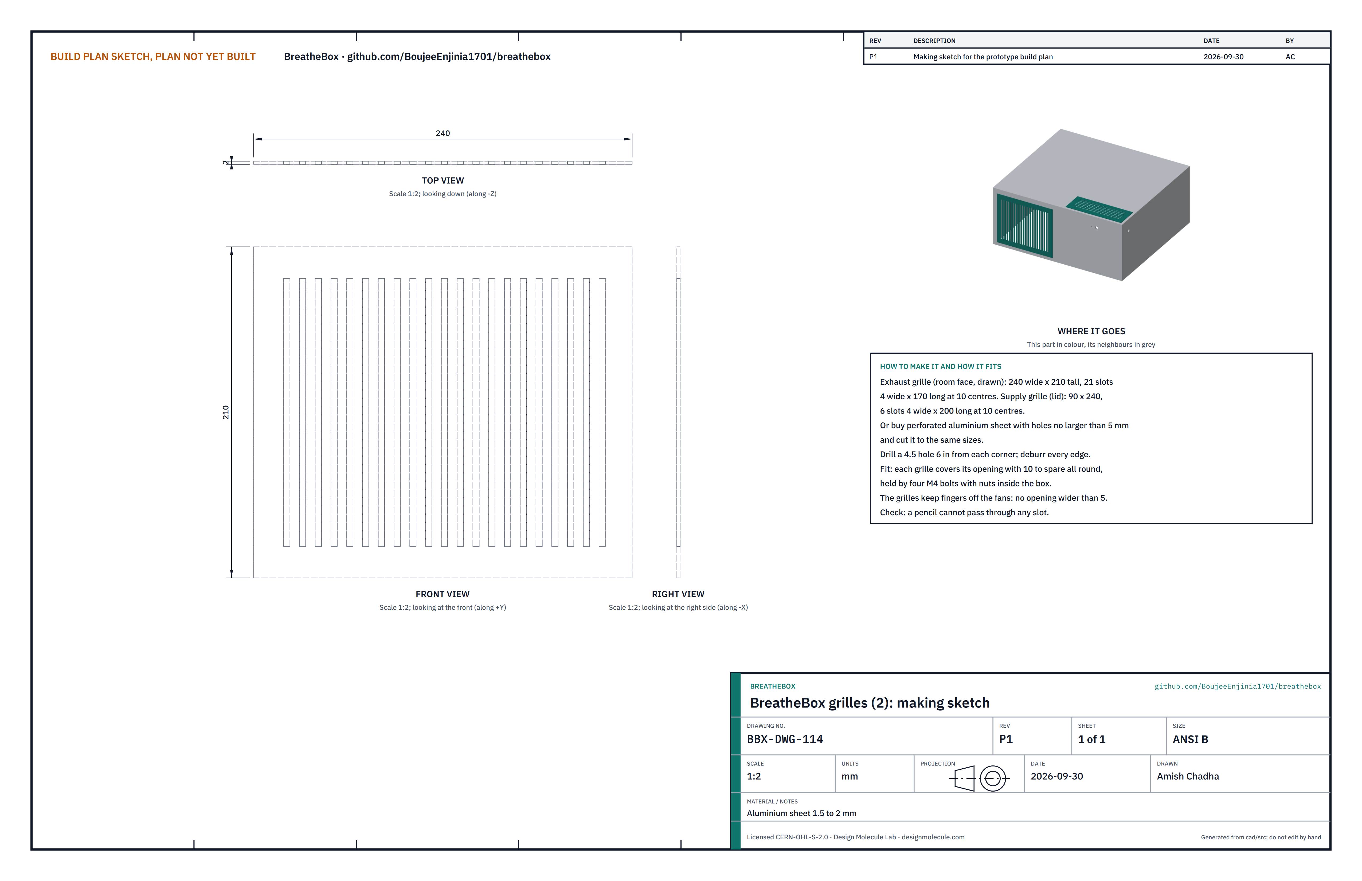
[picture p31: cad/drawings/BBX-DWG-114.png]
Figure 18. Making sketch of the grilles


*Figure 18. Grilles making sketch (BBX-DWG-114); the exhaust grille is drawn.*

**What it is and what it is made from.** Two guards over the room openings that keep fingers off the fans. Aluminium sheet 1.5 to 2 mm, slotted, or perforated aluminium sheet with holes no larger than 5.

**How to make it.**

1. Exhaust grille: 240 wide x 210 tall, 21 slots 4 wide x 170 long at 10 centres.
2. Supply grille: 90 x 240, six slots 4 wide x 200 long at 10 centres.
3. Drill a 4.5 hole 6 in from each corner; deburr every edge and slot.

**How it fits the parts next to it.** Each grille covers its opening with 10 to spare all round and is held by four M4 bolts with nuts inside the box: the exhaust grille on the room face, the supply grille on the lid over its 70 x 220 opening.

**Check before moving on.** A pencil cannot pass through any slot.

### 3.11 Lid

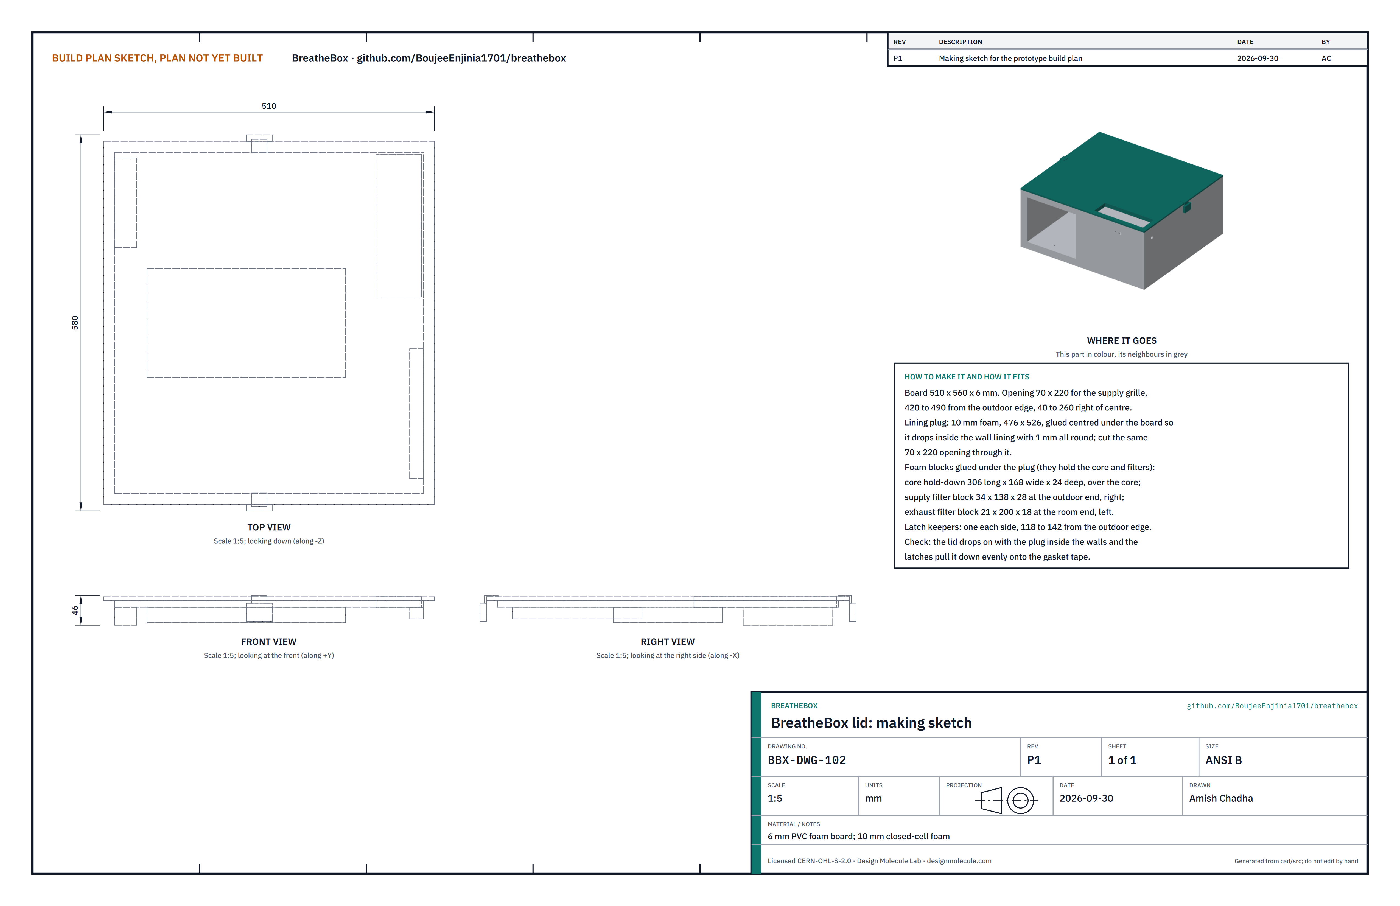
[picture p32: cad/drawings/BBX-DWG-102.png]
Figure 19. Making sketch of the lid


*Figure 19. Lid making sketch (BBX-DWG-102).*

**What it is and what it is made from.** The lift-off top: a board, a foam lining plug, foam blocks that hold the core and the filters, and two latch keepers. 6 mm PVC foam board; 10 mm closed-cell foam; two small stainless toggle latches with keepers.

**How to make it.**

1. Cut the board 510 x 560 and an opening 70 x 220, from 420 to 490 from the outdoor edge and 40 to 260 right of centre.
2. Cut the foam plug 476 x 526 with the same opening, and glue it centred under the board.
3. Glue foam blocks under the plug: a core hold-down 306 long x 168 wide x 24 deep, centred over the core's position; a supply filter block 34 x 138 x 28 at the outdoor end, right; an exhaust filter block 21 x 200 x 18 at the room end, left.
4. Fit the latch keepers to the board 118 to 142 from the outdoor edge, one each side, and the latches to the side walls under them.
5. Run 3 mm foam gasket tape along the top edges of the walls.

**How it fits the parts next to it.**

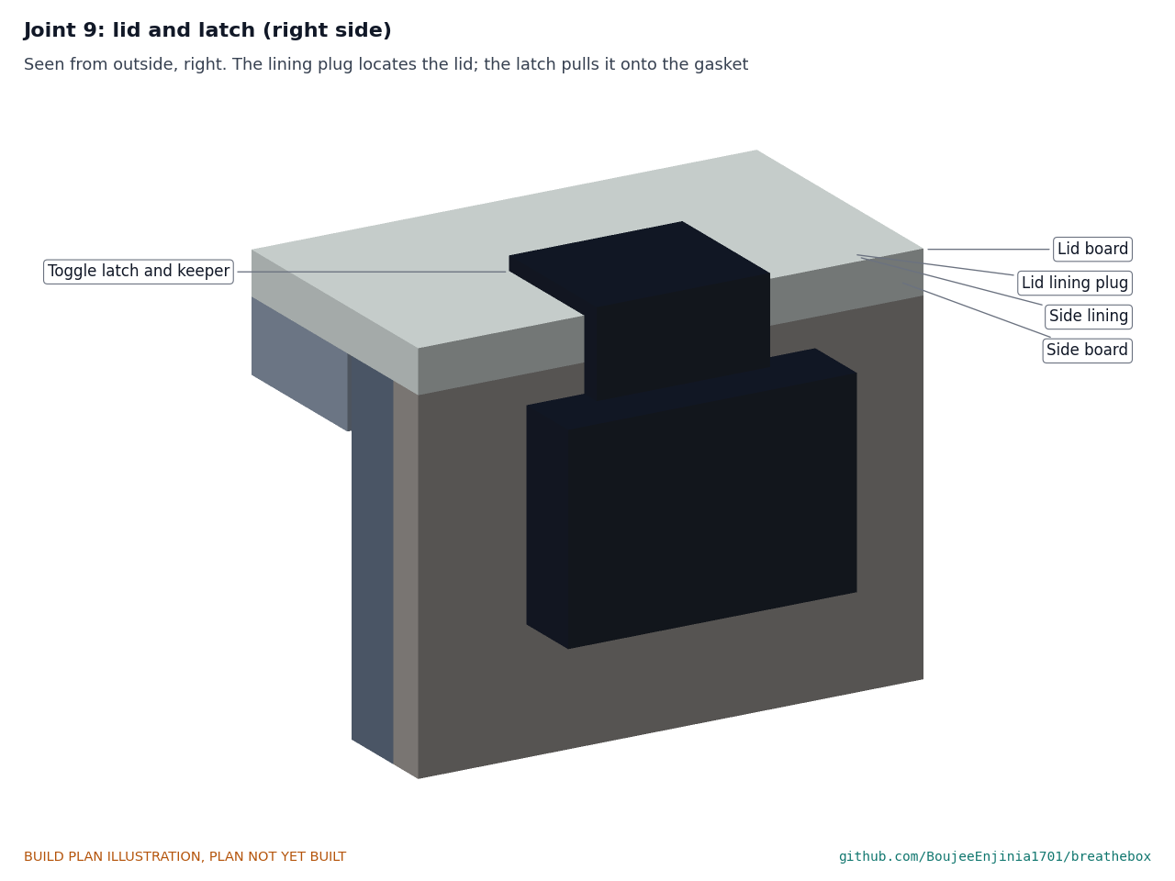
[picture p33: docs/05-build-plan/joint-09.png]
Figure 20. Joint 9: lid and latch


*Figure 20. The lining plug drops inside the walls with 1 mm all round; the latch pulls the lid down onto the gasket.*

**Check before moving on.** The lid drops on without force, and the latches close with the gasket evenly squeezed.

### 3.12 Struts

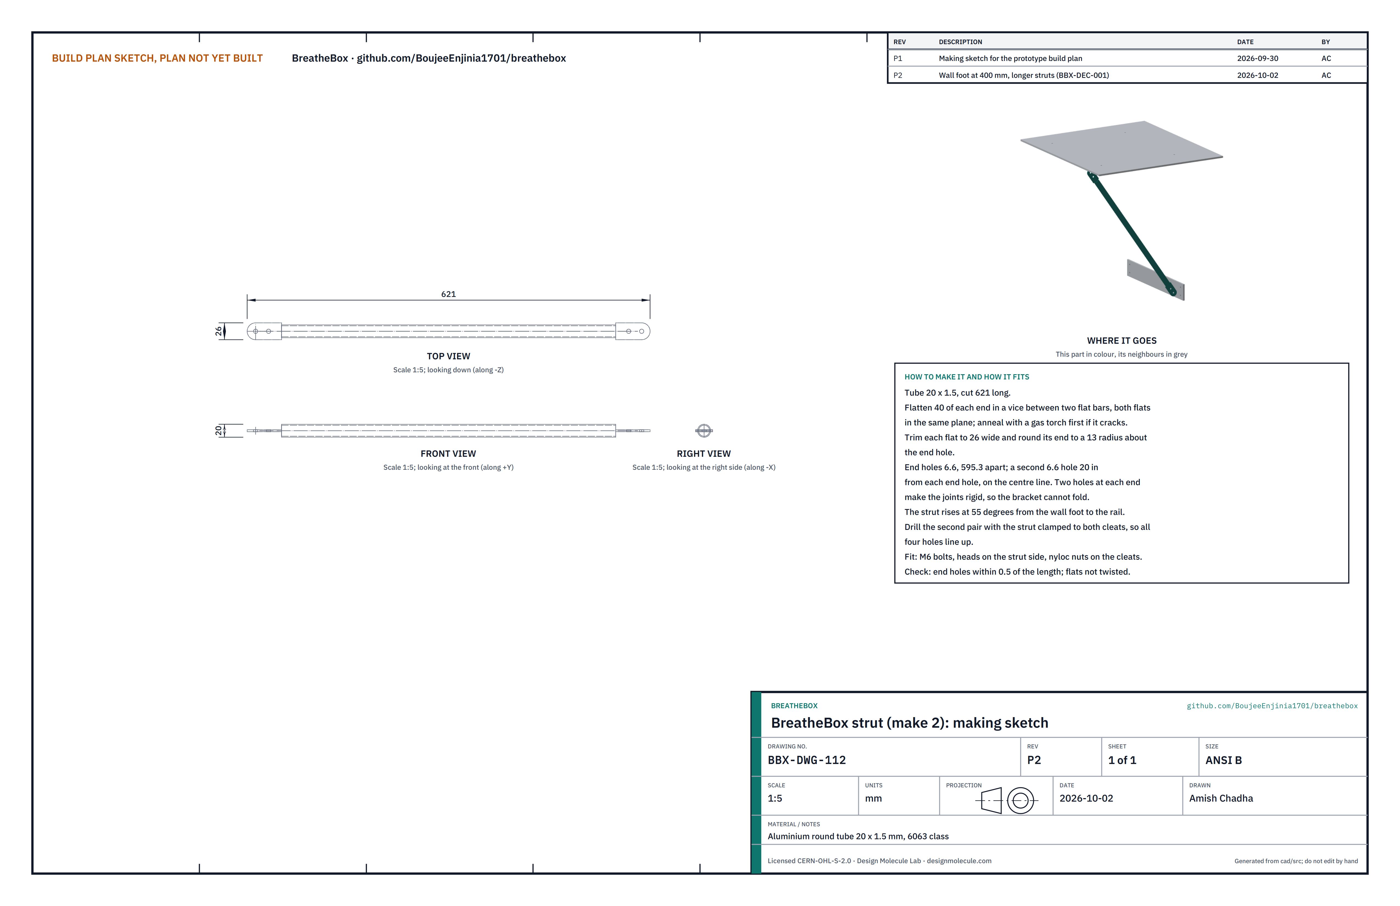
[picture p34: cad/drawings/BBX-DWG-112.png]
Figure 21. Making sketch of the strut


*Figure 21. Strut making sketch (BBX-DWG-112), drawn laid flat. Make two.*

**What it is and what it is made from.** The diagonal members that carry the room end of the unit to the wall foot. Aluminium round tube 20 x 1.5, 6063 class.

**How to make it.**

1. Cut two tubes 621 long.
2. Flatten 40 of each end in a vice between two flat bars, both flats in the same plane. If the tube cracks, anneal the ends with a gas torch first.
3. Trim each flat to 26 wide and round its end to a 13 radius.
4. Drill a 6.6 hole in each flat, 595.3 apart (end to end), centred 13 from each end.
5. Clamp the strut to its top cleat and its foot cleat in place, and drill the second 6.6 hole in each flat, 20 in from the first, through the strut and the cleat together.

**How it fits the parts next to it.** The top flat bolts to the inside face of the top cleat's upright leg, the bottom flat to the inside face of the foot cleat, two M6 bolts at each end, heads on the strut side and nyloc nuts on the cleat (Figures 5 and 23). The strut rises at about 55° from the foot to the rail.

**Check before moving on.** End holes 595.3 apart within 0.5; the flats are not twisted.

### 3.13 Wall foot

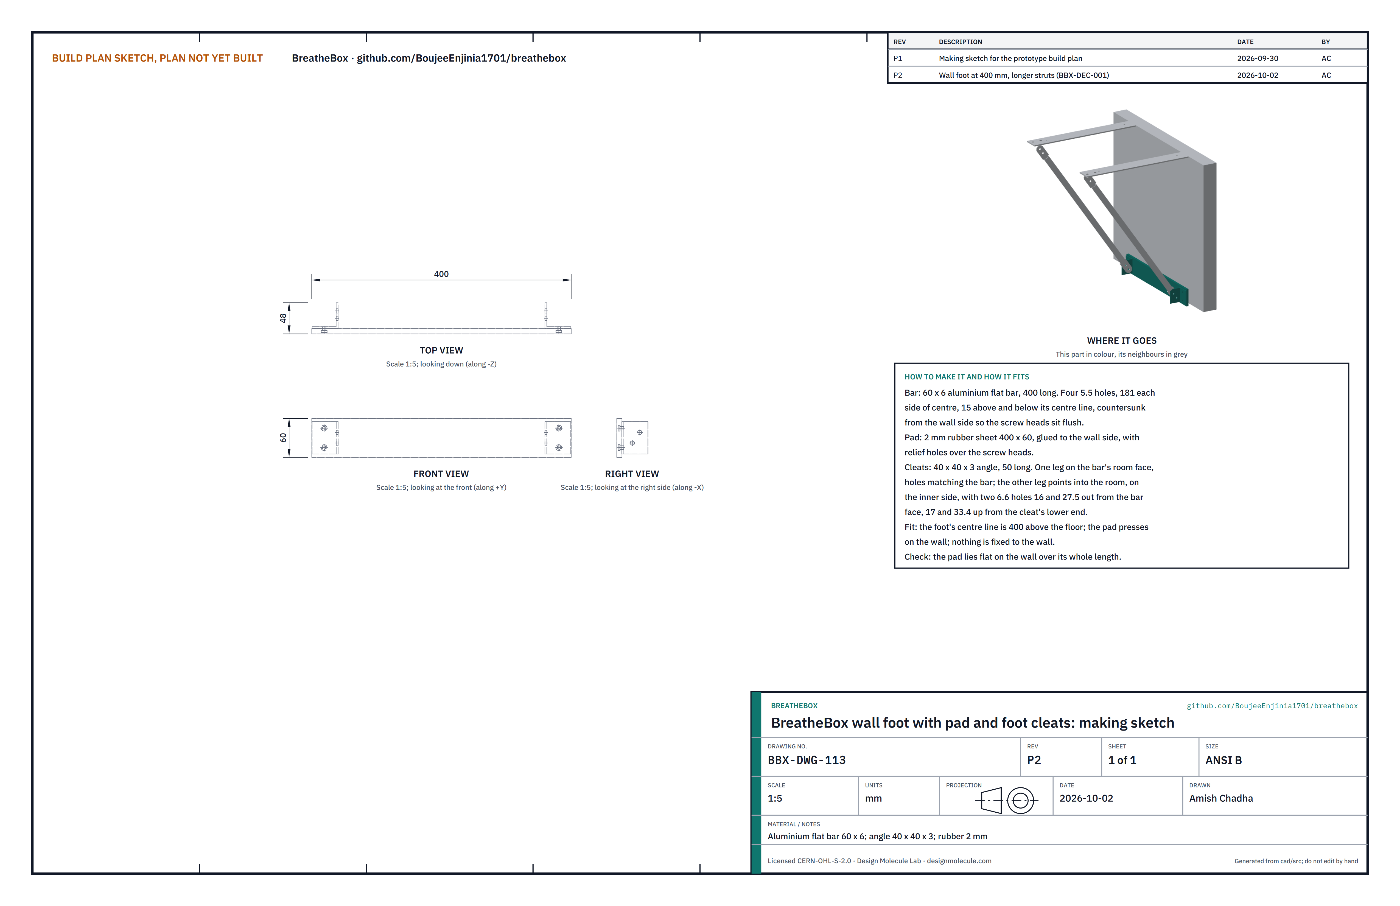
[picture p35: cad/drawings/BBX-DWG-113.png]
Figure 22. Making sketch of the wall foot


*Figure 22. Wall foot with pad and foot cleats making sketch (BBX-DWG-113).*

**What it is and what it is made from.** A padded bar that presses on the wall below the window and takes the bracket's push. Aluminium flat bar 60 x 6, two 40 x 40 x 3 angle cleats, and 2 mm rubber sheet.

**How to make it.**

1. Cut the bar 400 long. Drill four 5.5 holes, 181 each side of centre, 15 above and below the bar's centre line, and countersink them from the wall side.
2. Cut two cleats 50 long. Bolt one leg of each to the bar's room face with two M5 countersunk screws and nyloc nuts, the other leg pointing into the room on the inner side.
3. Mark the cleats' strut holes, 16 and 27.5 out from the bar face and 17 and 33.4 up from the cleat's lower end, and drill them with the strut in place (section 3.12).
4. Glue the 400 x 60 rubber pad to the wall side, with relief holes over the screw heads.

**How it fits the parts next to it.**

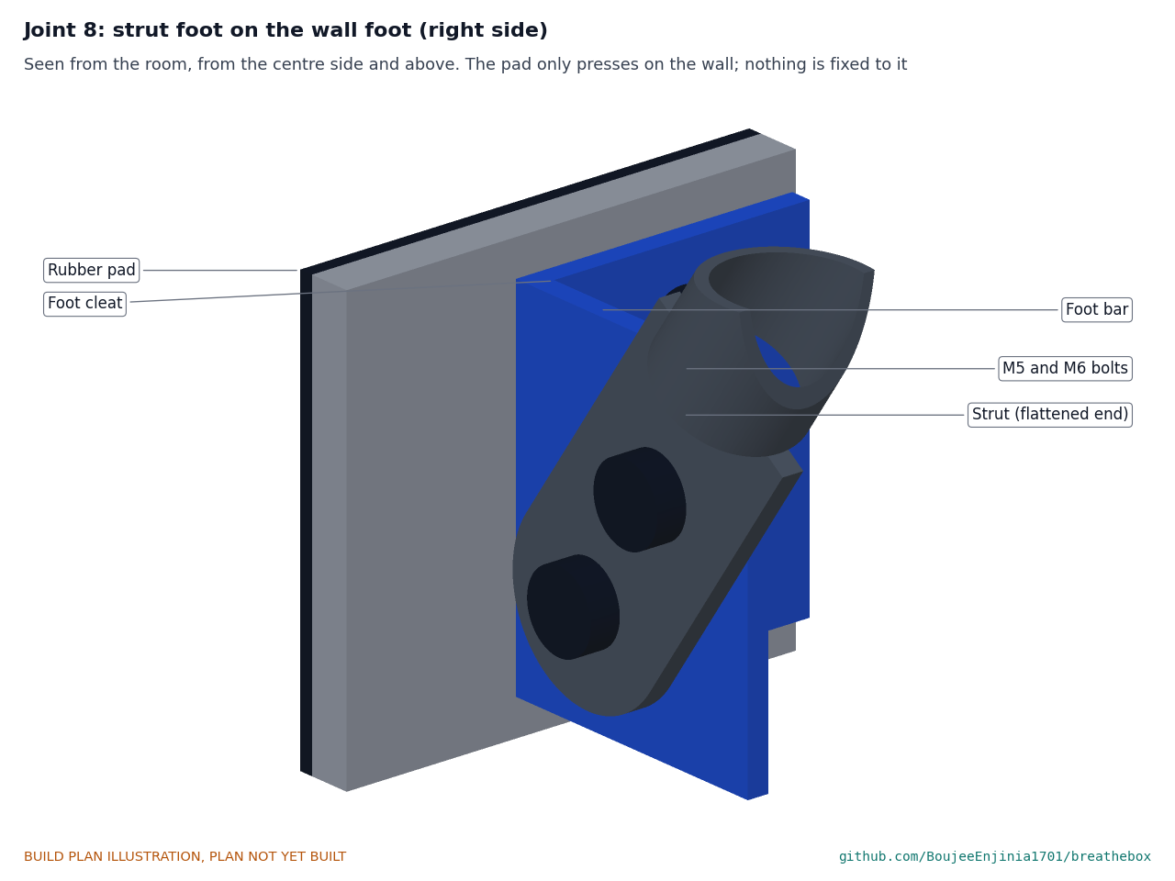
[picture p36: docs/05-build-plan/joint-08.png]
Figure 23. Joint 8: strut foot on the wall foot


*Figure 23. The strut's lower flat bolts to the foot cleat with two M6 bolts; the pad only presses on the wall.*

The foot's centre line is 400 above the floor, so the wall below the window must be clear from about 370 to 430 above the floor (no radiator or skirting there). Nothing is fixed to the wall.

**Check before moving on.** The pad lies flat on the wall along its whole length.

### 3.14 Window insert panel

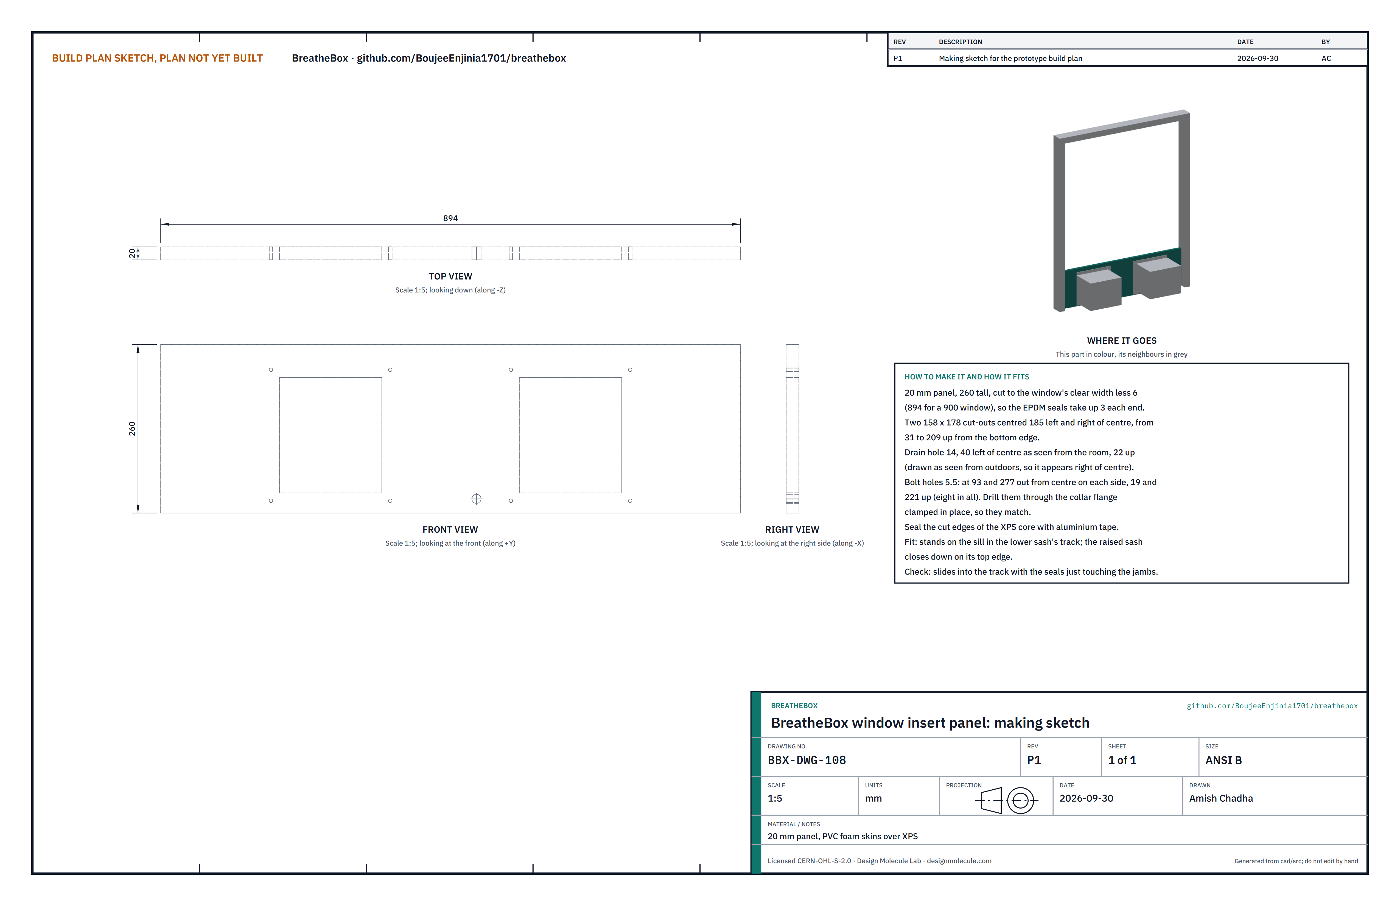
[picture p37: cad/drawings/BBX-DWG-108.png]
Figure 24. Making sketch of the insert panel


*Figure 24. Insert panel making sketch (BBX-DWG-108), drawn as seen from outdoors.*

**What it is and what it is made from.** The panel that fills the gap under the raised lower sash. A 20 mm insulated panel with PVC foam skins over an XPS core, and compressible EPDM seal strip at each end.

**How to make it.**

1. Cut the panel 260 tall and as long as the window's clear width less 6 (894 for a 900 window).
2. Cut two 158 x 178 openings, centred 185 left and 185 right of centre, from 31 to 209 up.
3. Drill a 14 hole 40 left of centre (as seen from the room), 22 up.
4. Seal the cut XPS edges with aluminium tape. Stick EPDM seal strip to both ends.
5. Leave the eight bolt holes until the collars are made; they are drilled through the collar flanges (section 3.15).

**How it fits the parts next to it.** It stands on the sill in the lower sash's track; the raised sash closes down on its top edge; its end seals press on the jambs.

**Check before moving on.** It slides into the track with the seals just touching the jambs.

### 3.15 Collars

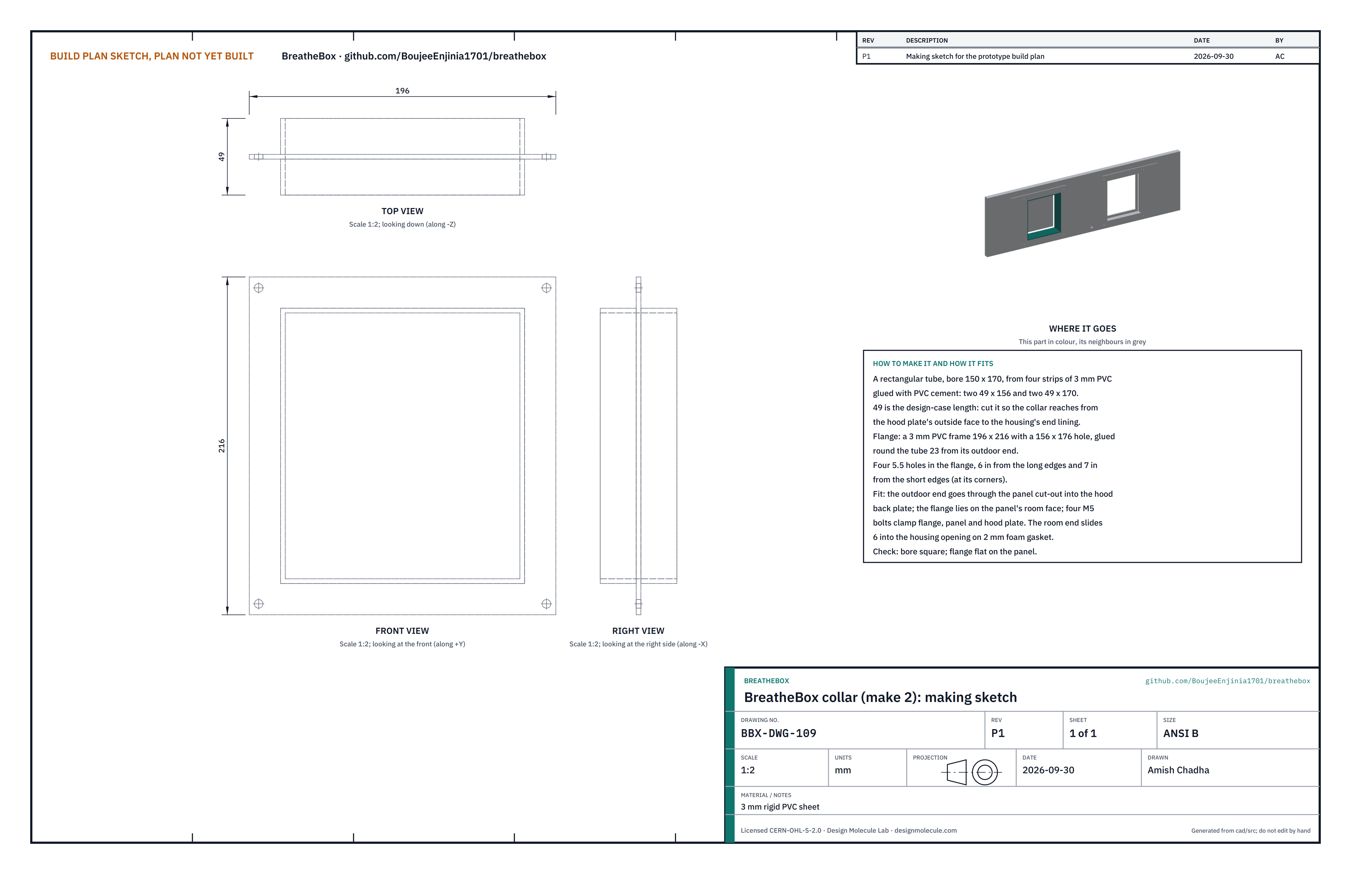
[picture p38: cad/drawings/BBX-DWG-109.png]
Figure 25. Making sketch of the collar


*Figure 25. Collar making sketch (BBX-DWG-109). Make two.*

**What it is and what it is made from.** A short rectangular duct through the panel on each side, which joins a hood to the housing. 3 mm rigid PVC sheet.

**How to make it.**

1. Cut four strips: two 49 x 156 and two 49 x 170. Glue them into a tube with a 150 x 170 bore using PVC cement. 49 is the length for the design-case window: cut it so that the collar reaches from the outer face of the hood back plate to the housing's end lining.
2. Cut a flange: a frame 196 x 216 with a 156 x 176 hole. Glue it round the tube 23 from its outdoor end.
3. Drill four 5.5 holes in the flange corners, 6 in from the long edges and 7 in from the short edges.
4. Clamp the flange to the panel's room face, the tube through the panel opening, and drill the panel through the flange holes.

**How it fits the parts next to it.**

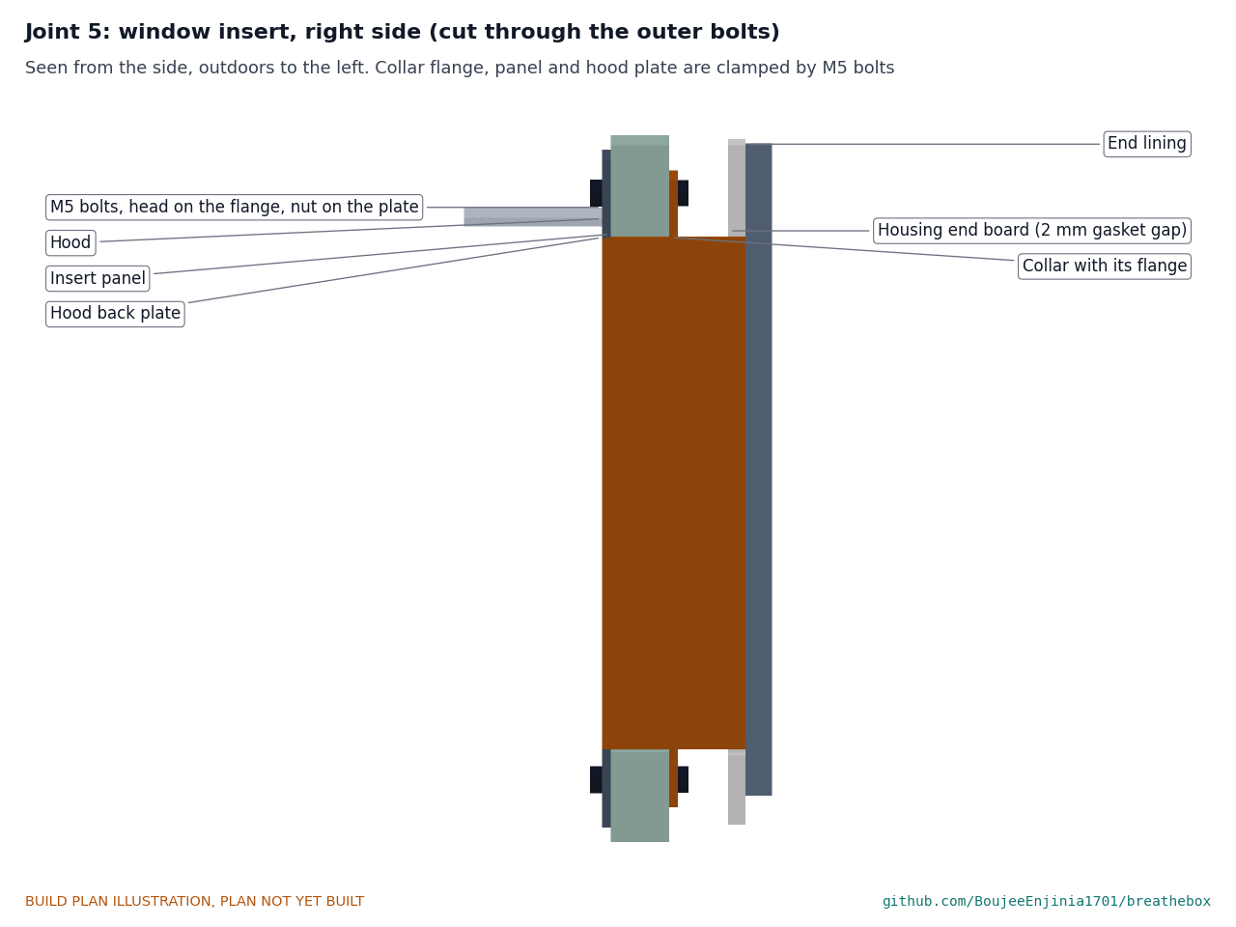
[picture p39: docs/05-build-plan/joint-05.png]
Figure 26. Joint 5: the window insert


*Figure 26. Cut through the outer bolts: collar flange, panel and hood back plate are clamped by M5 bolts; the collar passes through and slides into the housing's opening.*

The outdoor end of the collar fits the hood back plate's opening and is glued there. The flange lies on the panel's room face. The room end slides 6 into the housing's opening on 2 mm foam gasket tape and stops against the end lining.

**Check before moving on.** The bore is square, and the flange lies flat on the panel.

### 3.16 Hoods

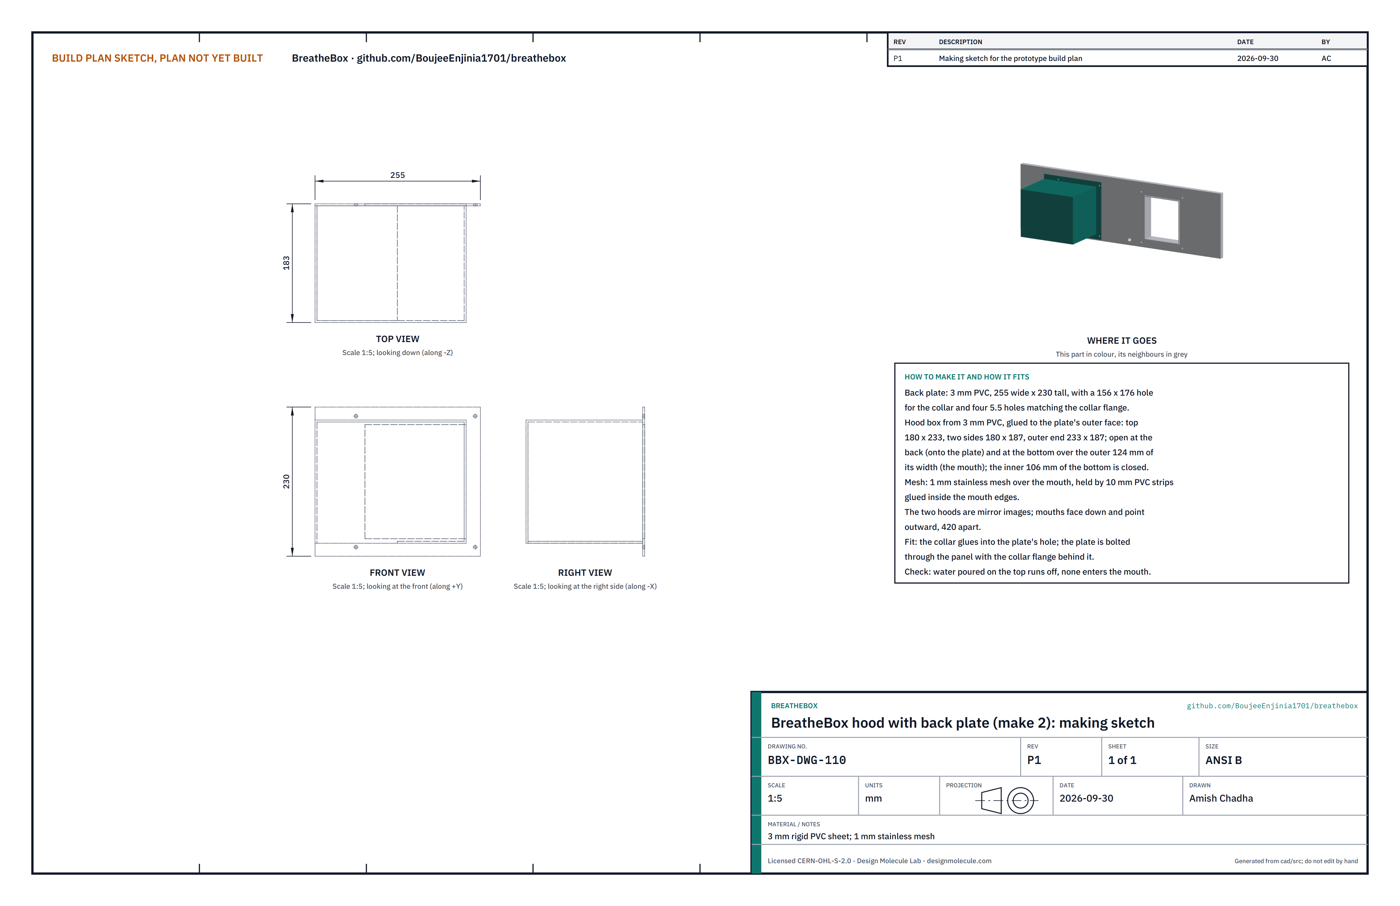
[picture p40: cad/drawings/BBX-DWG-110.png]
Figure 27. Making sketch of the hood


*Figure 27. Hood with back plate making sketch (BBX-DWG-110). Make two, mirror images.*

**What it is and what it is made from.** A box on the outdoor face of the panel that turns each air stream to face down, with insect mesh over its mouth. 3 mm rigid PVC sheet; 1 mm stainless mesh.

**How to make it.**

1. Back plate: 255 wide x 230 tall, with a 156 x 176 hole for the collar and four 5.5 holes matching the collar flange (drill through the flange).
2. Hood box: a top 180 x 233, two sides 180 x 187 and an outer end 233 x 187. Glue them to each other and to the back plate's outer face with PVC cement. The box is open at the back, onto the plate, and open at the bottom over its outer 124 of width (the mouth); close the inner 106 of the bottom with a strip of sheet.
3. Glue the mesh over the mouth, held by 10 mm PVC strips glued inside the mouth edges.
4. Make the second hood as the mirror image, so both mouths point outward, 420 apart.

**How it fits the parts next to it.** The collar glues into the back plate's hole. Four M5 bolts per side pass through the collar flange, the panel and the back plate, heads on the flange and nyloc nuts on the plate (Figure 26).

**Check before moving on.** Water poured on the top runs off; none enters the mouth.

### 3.17 Bought components

Buy to specification, not brand. Line numbers are those of the bill of materials.

- **Counterflow core (line 2).** Polymer plate core 180 x 180 x 300, about 2.5 plate pitch, washable, with each end face split into two halves along its centre line, one half per air stream.
- **Fans (lines 3 and 4).** Two 24 V brushless centrifugal blowers, 120 x 120 x 32 class, about 100 m³/h free air and 400 Pa shut-off, PWM input and tach output, inlet ring no more than 80 across.
- **Supply filter (line 5).** ISO 16890 ePM1 50 % pleated panel, 150 x 170 x 25, with a frame at least 5 wide.
- **Exhaust filter (line 6).** Coarse washable pad, 220 x 190 x 12.
- **Controller (line 7).** As section 3.8.
- **Adapter (line 12).** Certified 24 V DC, 1.5 A (36 W) plug-in SELV adapter with a 3 m low-voltage lead.
- **Sash jammer (line 14).** A no-drill adjustable sash jammer or window security bar: a telescopic bar about 22 square with rubber end pads, adjustable to at least the gap between the top of the raised lower sash and the window head (about 340 on the trial window). Nothing to make; check that it locks at that length and that its pads do not touch the glass.
- **Fixings and sundries (line 13).** Stainless: 8 M5 x 35 bolts for the hoods, 4 M5 x 20 bolts for the rails, 8 M5 x 12 countersunk screws for the cleats, 8 M6 x 16 bolts for the struts, all with nyloc nuts and washers; M4 bolts for the grilles; M4 nylon screws and rubber grommets for the fans; 3.5 x 16 screws for the battens; M12 cable gland; 3 mm foam gasket tape; anti-slip rubber tape; PVC cement; contact adhesive; clear silicone; aluminium tape; cable ties; connectors; 2 A time-delay fuse and inline holder.

## 4. Putting it together

In each picture the parts already fitted are grey and the part being fitted is in colour, with an arrow showing the way it goes in.

### Step 1: boards and corner battens

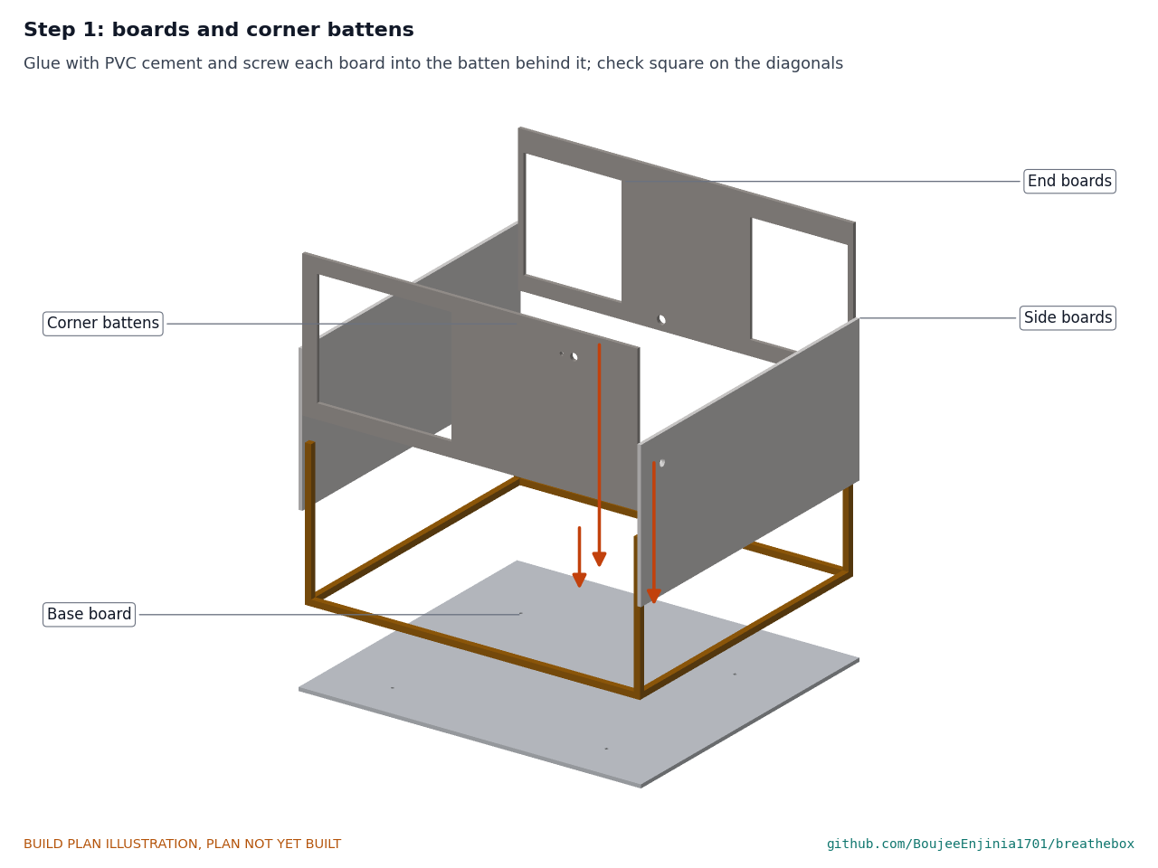
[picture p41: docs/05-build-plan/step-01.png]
Step 1


Glue and screw the battens, sides and ends onto the base (section 3.1). Check square before the glue sets.

### Step 2: bracket rails under the base

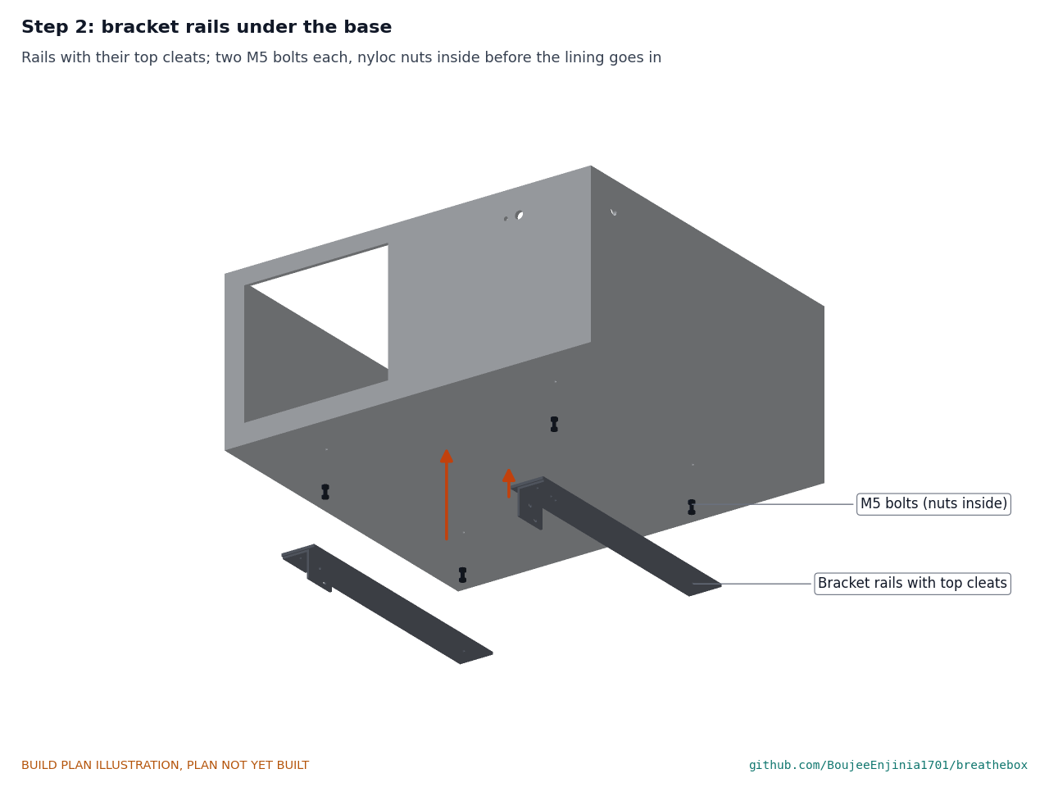
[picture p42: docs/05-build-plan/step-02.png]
Step 2


Two M5 bolts per rail from below, penny washers and nyloc nuts inside. Tighten now: the lining covers the nuts.

### Step 3: foam lining

Step 3

Floor first, then sides, then ends (section 3.3).

### Step 4: core frames, dividers and fan bulkhead

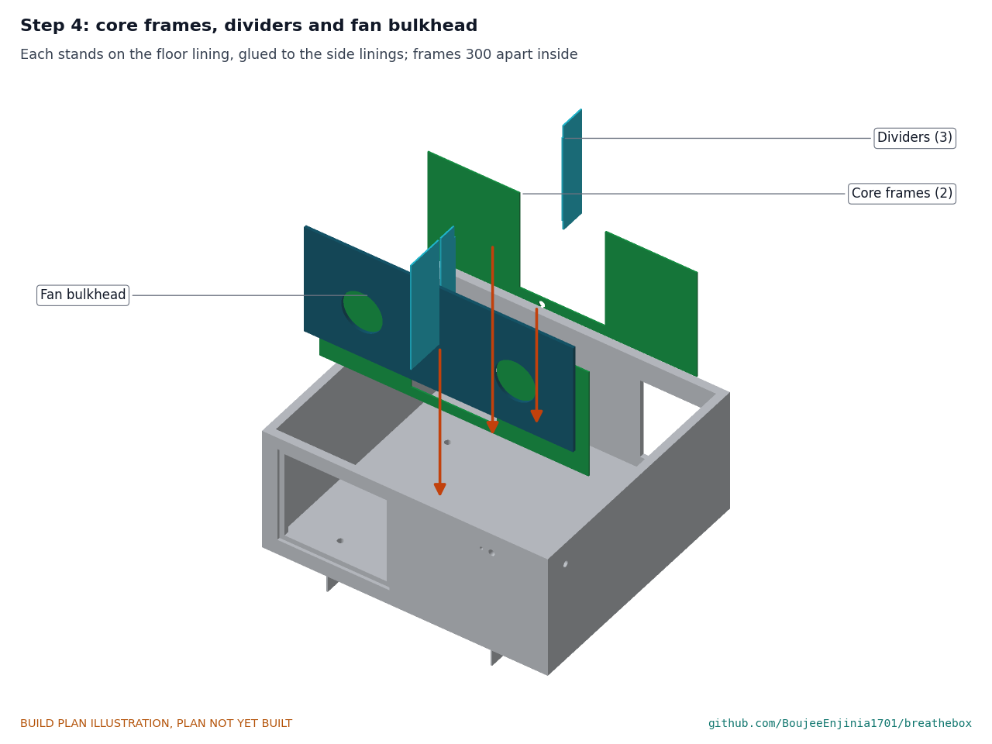
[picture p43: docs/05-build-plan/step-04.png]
Step 4


Stand each on the floor lining and glue it to the side linings: core frames 300 apart inside, then the bulkhead, then the dividers between them. Use the core as a spacer while the frames' glue sets.

### Step 5: filter seat strips and stops

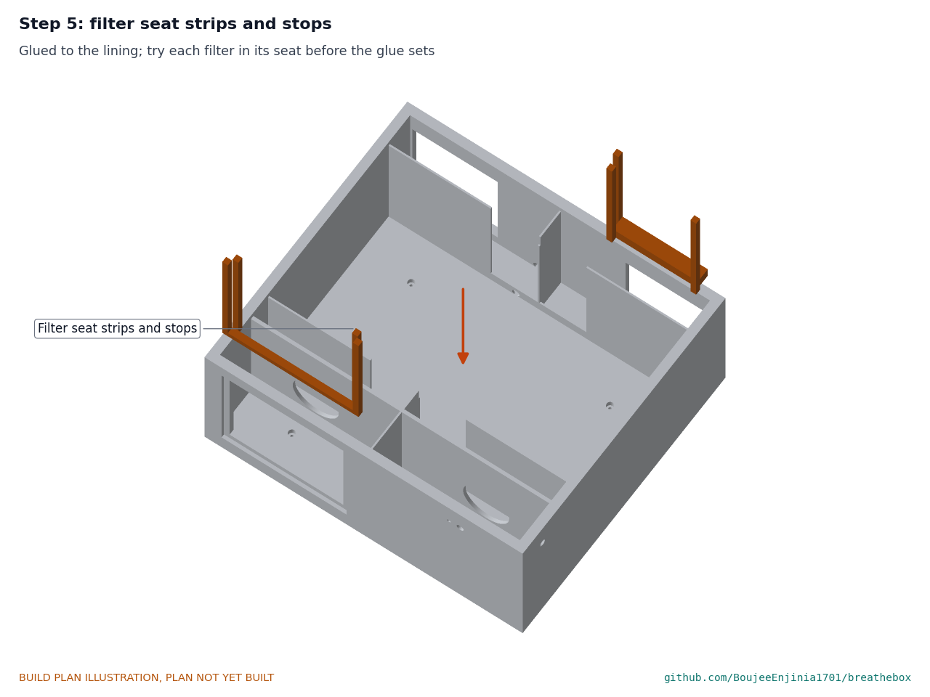
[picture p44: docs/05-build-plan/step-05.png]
Step 5


Glue them in with each filter in place (section 3.7), then lift the filters out.

### Step 6: fans onto the bulkhead

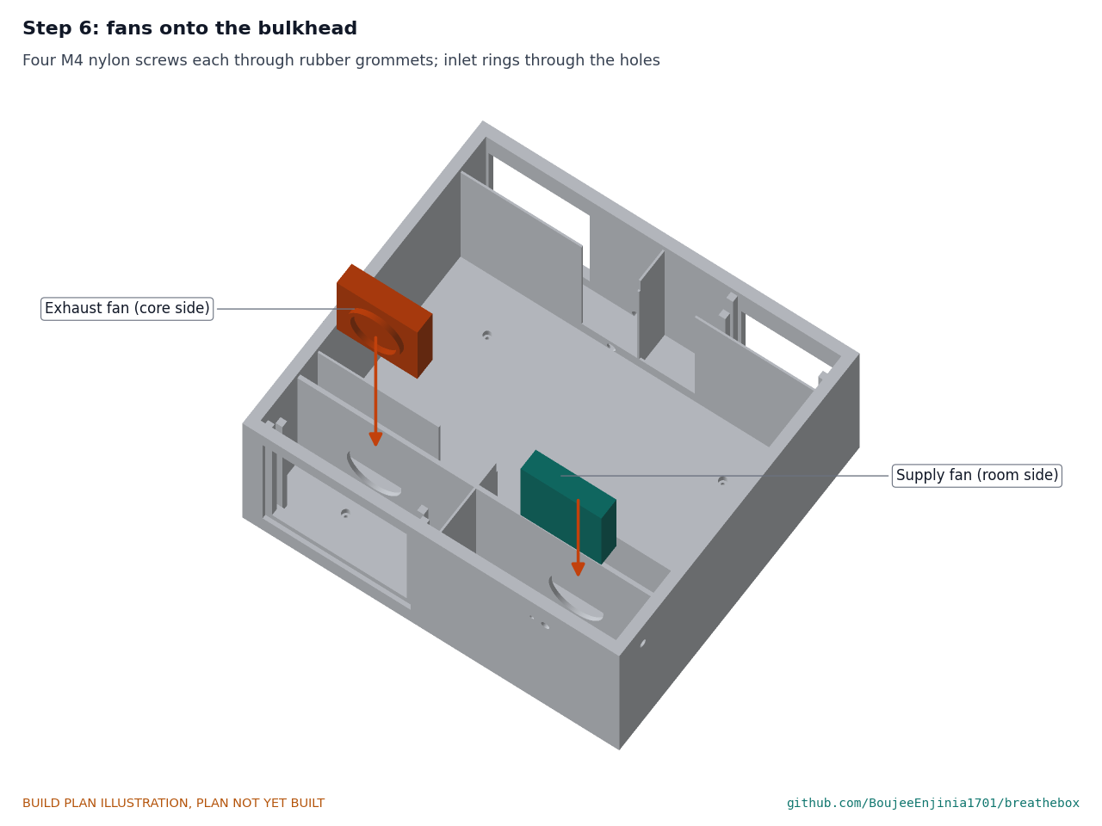
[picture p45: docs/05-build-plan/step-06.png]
Step 6


Supply fan on the room side, right; exhaust fan on the core side, left; each inlet ring through its hole. Four M4 nylon screws each through rubber grommets, snug, not tight.

### Step 7: controls and power entry

Step 7

Fit and wire as section 3.8. **Hold point:** the wiring checks of section 3.8 pass before going on.

### Step 8: condensate tray and drain tube

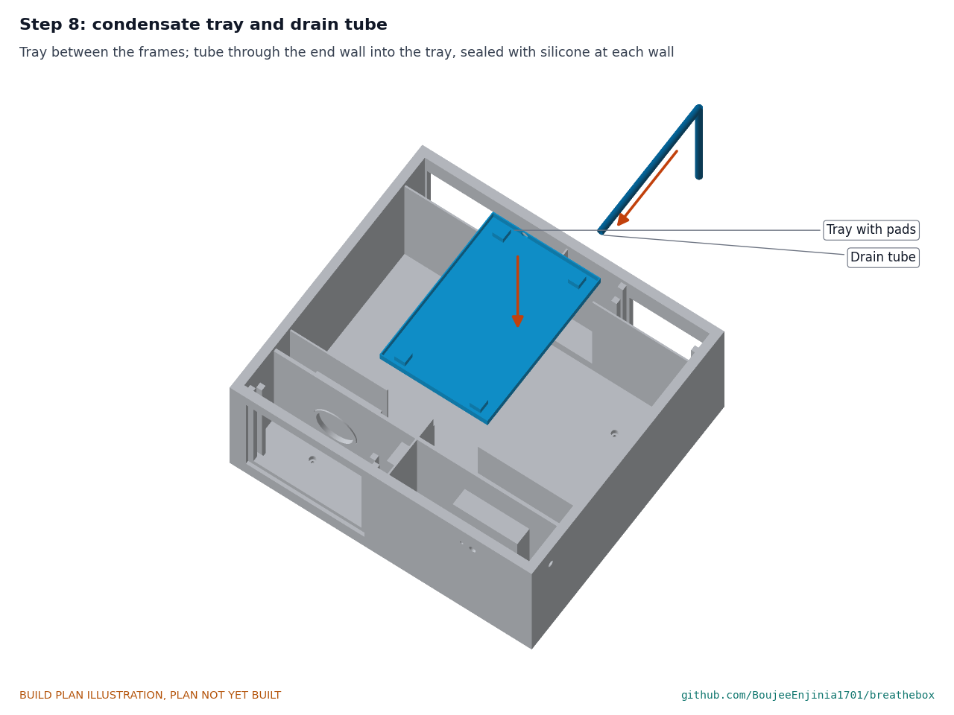
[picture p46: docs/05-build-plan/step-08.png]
Step 8


Set the tray between the core frames. Feed the tube out through the core frame and the end wall, and seal it at each wall with silicone.

### Step 9: counterflow core

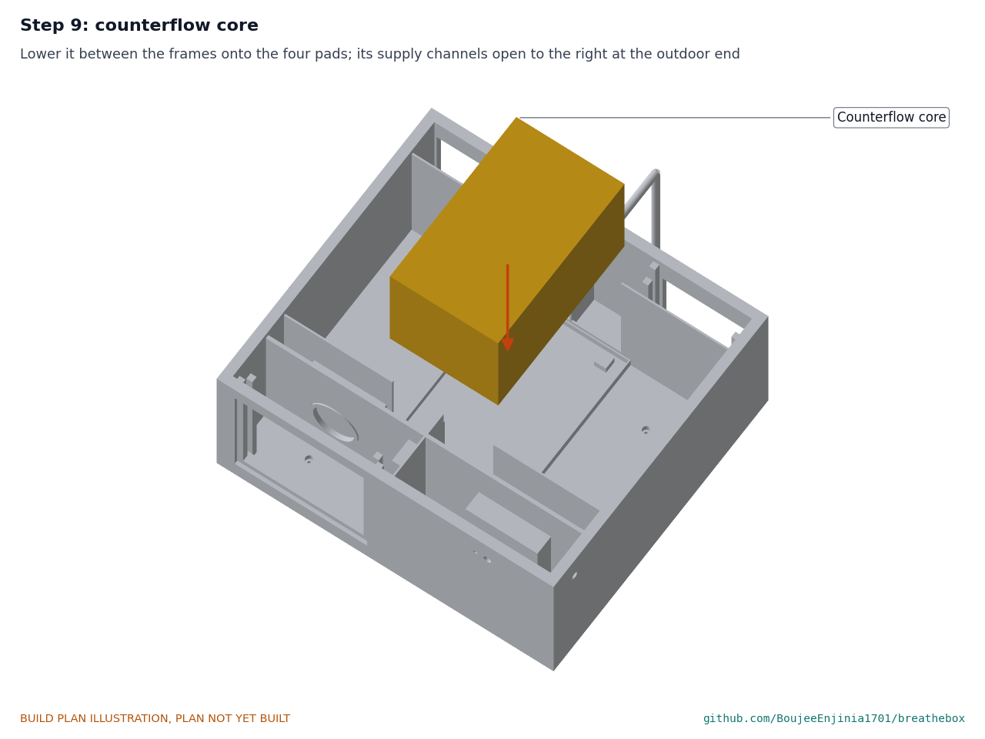
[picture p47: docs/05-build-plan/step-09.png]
Step 9


Lower the core between the frames onto its pads, with the supply half of its outdoor end on the right, as the core's maker marks it.

### Step 10: filters into their seats

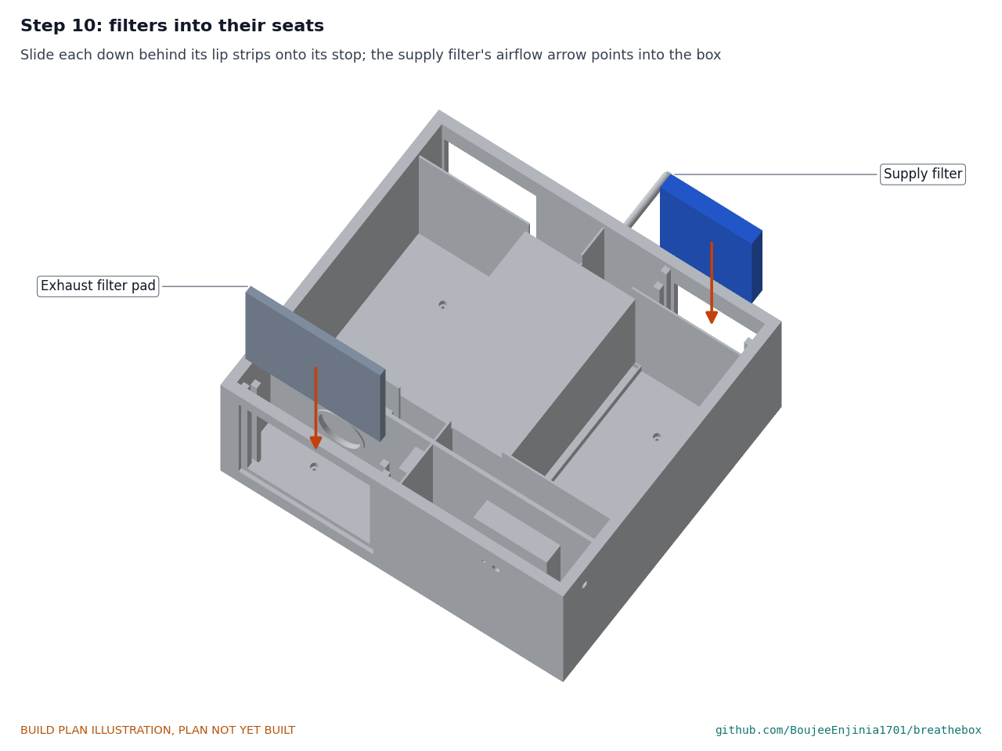
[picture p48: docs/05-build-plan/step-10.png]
Step 10


Slide each down behind its lip strips onto its stop, with the supply filter's airflow arrow pointing into the box.

### Step 11: grilles

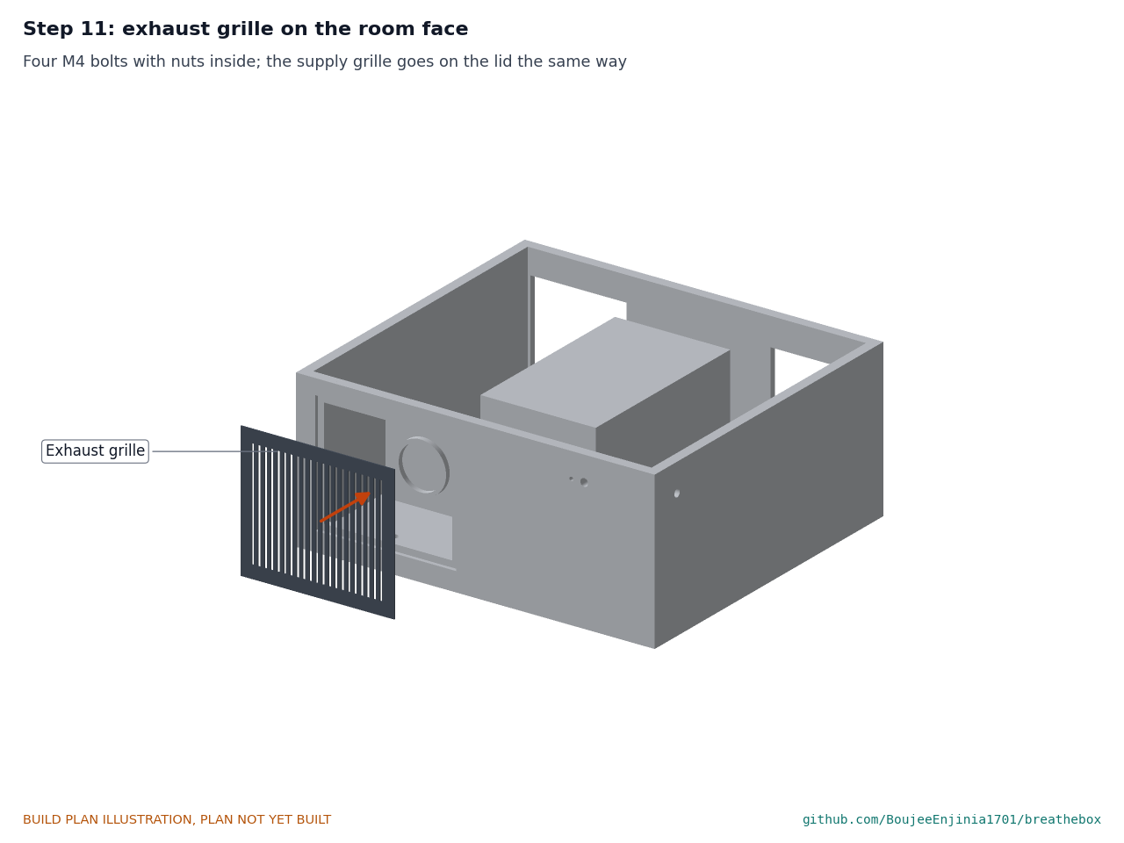
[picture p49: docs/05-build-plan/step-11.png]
Step 11


Exhaust grille on the room face and supply grille on the lid, four M4 bolts each, nuts inside.

### Step 12: lid on, latches closed

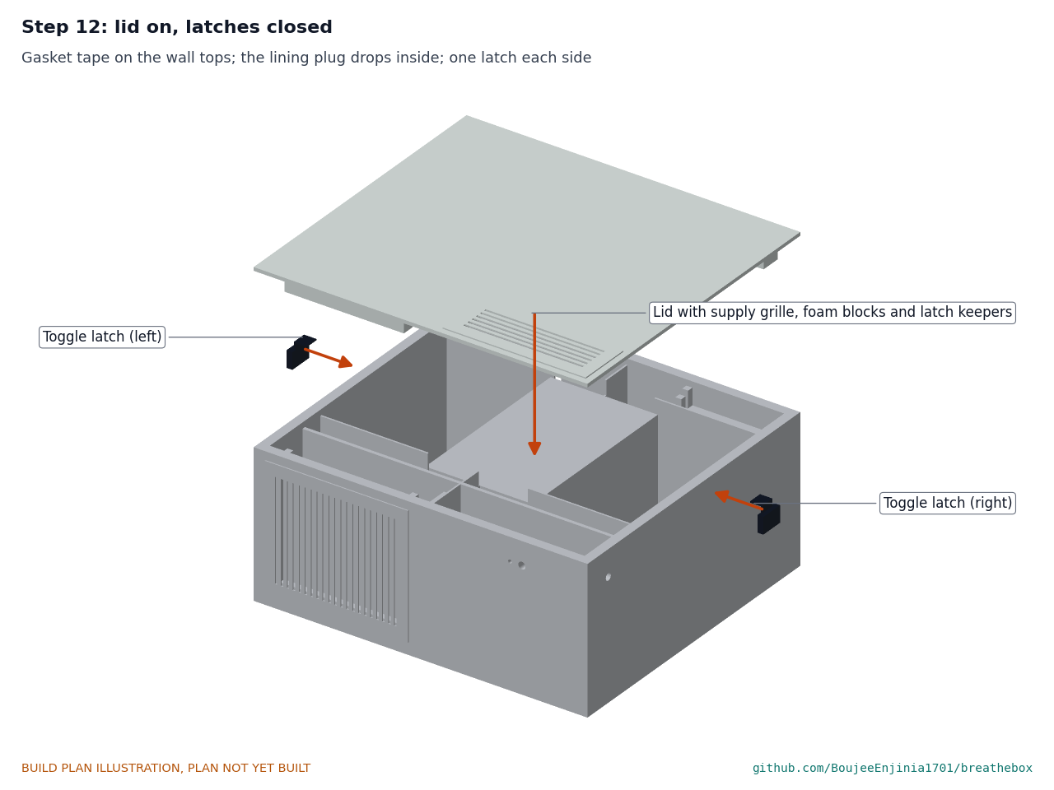
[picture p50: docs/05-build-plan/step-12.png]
Step 12


Check the gasket tape is whole and no wire lies across a wall top. Drop the lid on and close both latches. **Hold point:** first checks with power (section 5) are done with the lid on.

### Step 13: struts and wall foot

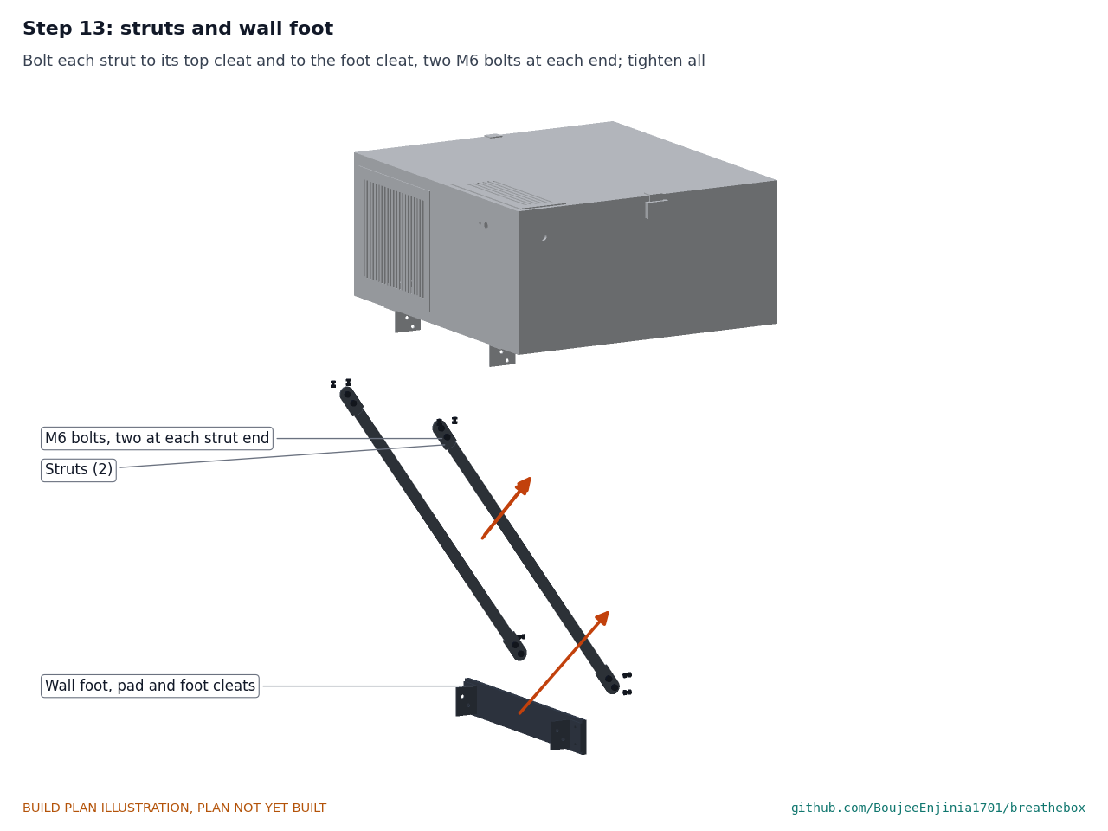
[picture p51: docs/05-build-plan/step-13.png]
Step 13


Bolt each strut to its top cleat and to the foot cleat, two M6 bolts at each end, and tighten all. The unit, bracket and foot are now one rigid piece of about 9 kg. The struts now rise steeply, at about 55°, because the foot sits 400 above the floor.

### Step 14: window insert on the bench

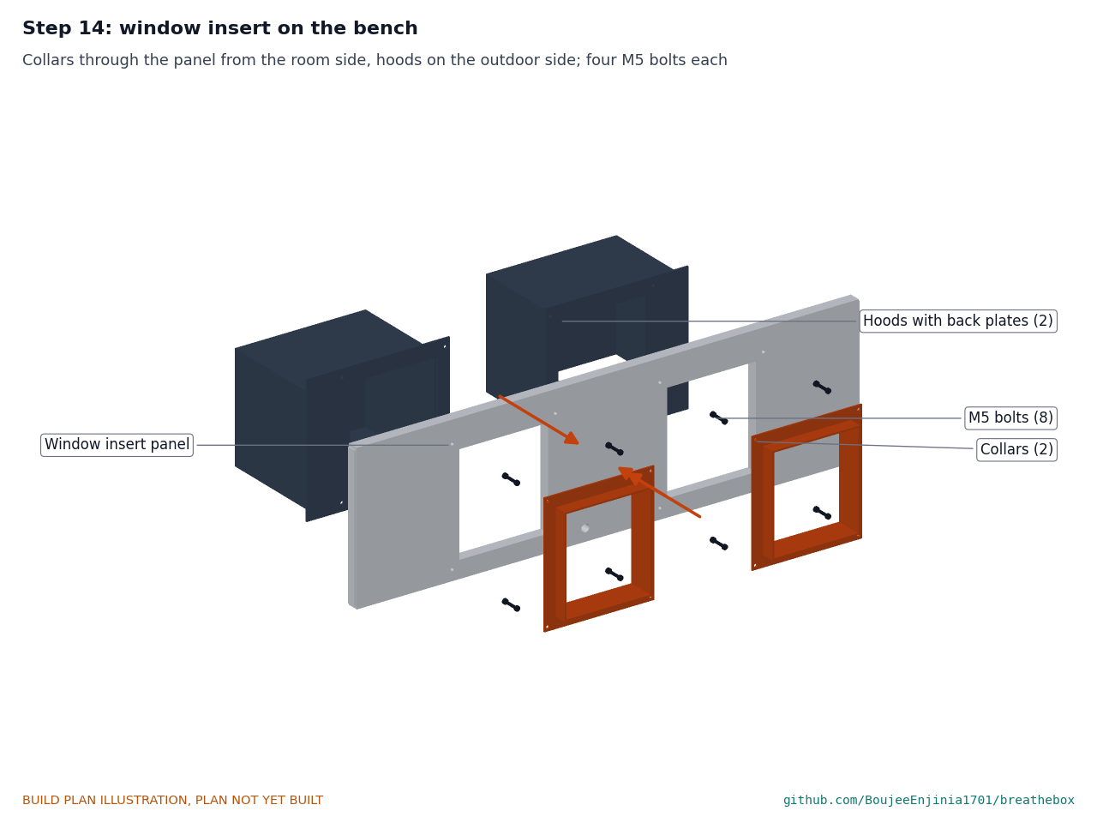
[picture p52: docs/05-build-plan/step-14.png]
Step 14


Collars through the panel from the room side, hoods on the outdoor side, four M5 bolts per side through flange, panel and back plate. Feed the drain tube through the panel's hole.

### Step 15: insert into the window, sash jammer fitted

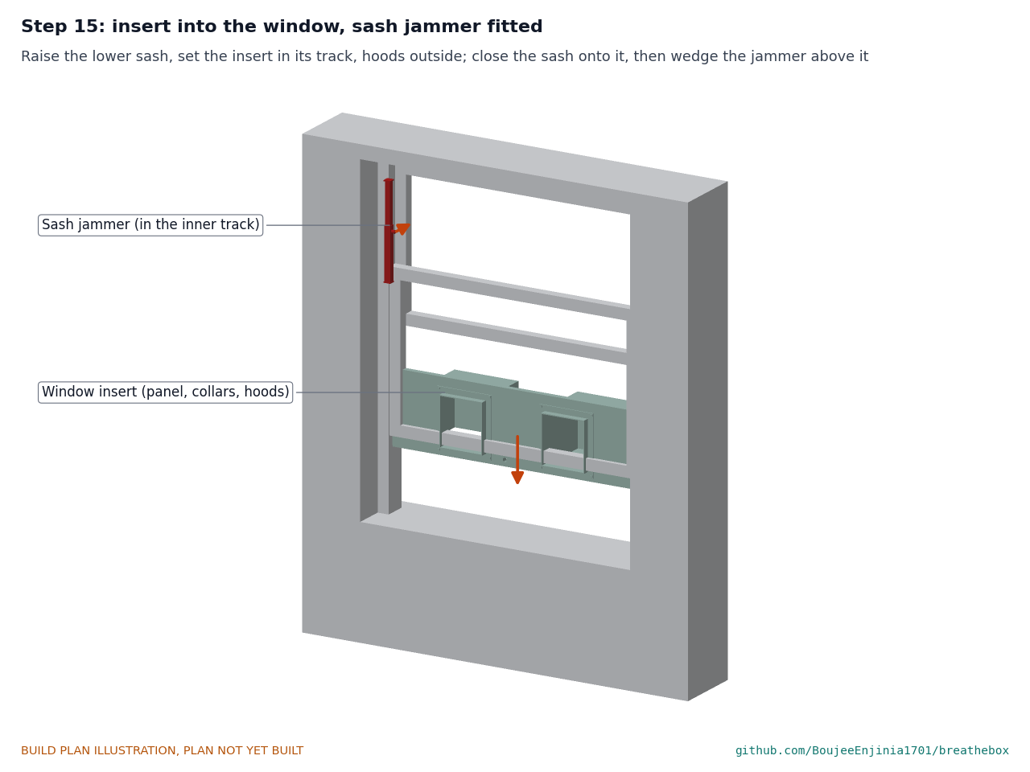
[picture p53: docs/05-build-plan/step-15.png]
Step 15


From inside, raise the lower sash fully, pass the hoods out under it, and stand the panel in the lower sash's track with the hoods outside. Close the sash down onto the panel. Then set the sash jammer upright in the inner track, between the top of the lower sash and the window head, near one jamb; extend it until both rubber pads bear firmly and lock it. Try to lift the lower sash: it must not move. **Hold point:** safety stop S4.

### Step 16: unit onto the sill

Step 16

Stick anti-slip tape under the housing base where it sits on the sill. With a helper, set the unit on the sill and slide it back so the collars enter the housing openings, until the foot pad meets the wall. Plug in the adapter last.

## 5. First checks

These are the checks a TRL 4 test report would record; this plan only lists them. Requirement numbers are those of BBX-REQ-001.

*Table 2. First checks.*

| Check | Requirement | How | Pass when |
| --- | --- | --- | --- |
| Air paths sealed | R1, R2 | Lid off, fans off; smoke pencil along every frame, divider and bulkhead edge with a small fan blowing into one chamber | No smoke crosses into another chamber |
| Filters and core out | R13 | Time removing the lid, both filters and the core by hand, and refitting them | Filters out and back in 2 min or less; core out without tools |
| Supply and power | R10 | Adapter's label; meter on the 24 V input with the fuse in; both fans at full speed | 24 V SELV, certified; input under 1.5 A |
| Fans run and report | R1 | Run each fan from the controller at low and full speed with the lid on | Each turns the right way, and its tach reading follows its speed |
| Balance | R1 | Flow hood or vane anemometer on both grilles at 50 m³/h | Supply and exhaust within 10 % |
| Cross-leakage in the core | R4 | Release CO2 as a tracer into the exhaust stream at the room grille; measure CO2 in the supply air at the top grille and in the room air, at 50 m³/h | Under about 3 % of the exhaust CO2 rise reaches the supply air |
| Drain | R7 | 100 ml of water into the tray with the unit on the sill | All of it reaches the end of the tube outdoors |
| Openings | R12 | Probe each grille and hood mouth | No opening wider than 5 at the grilles; mesh whole |
| Hood spacing and mesh | R11 | Measure between the inner edges of the two mouths | 420 or more; mesh 1.5 or finer |
| Window fit | R8 | Fit the insert in the trial window | Seals touch both jambs; the sash closes down onto the panel |
| Sash held down | R12 | With the sash jammer locked, lift the lower sash by hand from inside | The sash does not lift off the panel |
| Stays put on the sill | R9 | Push the room face toward the room with 50 N (a luggage scale) | Nothing moves |
| Mass | R9 | Weigh the unit with its bracket, the insert and the sash jammer | 12 kg or less together (11.8 kg estimated) |
| Install time | R9 | Time one person fitting the insert and the unit | 30 min or less |

## 6. Safety stops

Stop at each point. Carry on only when everything listed is true.

- **S1. Before cutting and gluing.** A ventilated space for PVC cement and contact adhesive; no flames near solvents; safety glasses and a cut-resistant glove for knife work.
- **S2. Before first power.** The adapter is a certified, undamaged 24 V SELV unit; the 2 A fuse is in its holder; the 24 V polarity at the controller is checked with a meter; the lid is on and latched, and both grilles are fitted.
- **S3. Whenever the lid comes off.** The adapter is unplugged first. Never run the fans with the lid off.
- **S4. Before fitting the insert in a window.** All eight insert bolts are tight; the work is done from inside only, never from outside a window above ground level; the hoods are held until the panel stands in its track and the sash is down on it and held by the locked sash jammer.
- **S5. Before running the unit in a room.** The room has no open-flued or unflued fuel-burning appliance (gas fire, stove, water heater), and its door has an undercut or gap, so frost mode cannot depressurise it much. The push test of section 5 has passed.
- **S6. Leaving it running.** This plan builds a supervised test prototype: do not leave it in a window unattended, and keep the adapter cable clear of the sash and of the drain tube.

## 7. Tools, skills and workspace

**Tools.** Steel rule, square and sharp utility knife with spare blades; fine-tooth saw and mitre box for strip; drill with 2.5 to 14 bits and a 81 hole saw; countersink; hacksaw with a 24 teeth per inch blade; bench vice with soft jaws and two flat bars for flattening the strut ends; files and a deburring tool; heat gun and a wooden former for the tray; gas torch (for annealing, if needed); spanners and hex keys for M4 to M6; screwdrivers; clamps; glue spreader; silicone gun; multimeter; digital angle finder; luggage scale to 25 kg; smoke pencil or incense stick; stopwatch.

**Skills.** No certified trade is needed. Accurate marking and knife cutting, basic drilling and filing of aluminium, gluing plastics, and plugging together low-voltage modules. All wiring in the unit is 24 V or lower, from a certified adapter; no mains wiring is part of this build.

**Workspace.** A bench about 1.2 x 0.8 m, with a ventilated corner for gluing and heat-forming; a trial sash window at ground level with a clear wall below it.

**Personal protective equipment.** Safety glasses for cutting, drilling and flattening; cut-resistant gloves for knife work and aluminium edges; heat-resistant gloves for the heat gun and torch; no gloves near a turning drill.

## 8. Where the numbers come from

- Model and constructability checks: `cad/src/model.py` (`python cad/src/model.py --check`, 90 checks); STEP and STL exports in `cad/step/` and `cad/stl/`.
- Pictures: `cad/src/build_plan_media.py`, using `.kit/build_views.py`; written to `docs/05-build-plan/` and `cad/drawings/BBX-DWG-101` to `BBX-DWG-114`.
- General arrangement: `cad/drawings/BBX-DWG-001.pdf`, Rev P4.
- Calculations: `docs/04-calcs/01-sizing.md` (BBX-CAL-001 v0.7) and `docs/04-calcs/sizing.py`; mass, stability, pressure and power in sections 3, 4 and 8.
- Bill of materials: `bom/bom.csv` and `bom/bom-notes.md`.
- Decisions: `docs/decisions/0003-design-for-construction.md` (BBX-DDR-003), with BBX-DDR-001 and BBX-DDR-002; decisions made and items to confirm in `docs/06-design-decisions.md` (BBX-DEC-001).
- Requirements: `docs/03-requirements.md` (BBX-REQ-001 v0.9).

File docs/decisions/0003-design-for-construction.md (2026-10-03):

---
doc_id: BBX-DDR-003
title: BreatheBox design for construction
project: BreatheBox
doc_type: Design decision record
version: "0.4"
status: Draft
date: '2026-10-02'
author: Amish Chadha
license: CERN-OHL-S-2.0
revisions:
- version: "0.1"
  date: '2026-09-30'
  author: Amish Chadha
  change: Changes that make the concept physically buildable, with the reason for each; made under Amish's 2026-09-30 instruction to make the design physically buildable; open for his review
- version: "0.2"
  date: '2026-10-01'
  author: Amish Chadha
  change: Budget treated as a value-engineering target
- version: "0.3"
  date: '2026-10-02'
  author: Amish Chadha
  change: "Accepted by Amish on 2026-10-02, with A2 decided as option (b) (foot at 400 mm) and A3 as option (a) (sash jammer)"
- version: "0.4"
  date: '2026-10-02'
  author: Amish Chadha
  change: "Consequences updated: the 400 mm foot and the sash jammer are now in the model, BOM, calculations, drawings, build plan and appearance model"
---

# 0003: Design for construction

- **Date:** 2026-09-30
- **Status:** accepted. Amish, 2026-10-02: "i approve your recommendations for all 555 open decisions." This covers every change in Tables 1 and 2 (P1 to P12, with the cost rise they bring) and the questions A2 and A3 in Table 3, now decided and recorded in the design decisions register (BBX-DEC-001). A2 was decided as option (b), not the option first recommended here: the first prototype has its wall foot at 400 mm. A1 is a value-engineering note, not a decision, and stands as written.

## Context

On 2026-09-30 Amish asked for every repo to get an illustrated prototype build plan that shows how each component is made and how it fits the next, and wrote: "If you are realising that the design cannot be built as per concept - fix the design assumptions to match and be physically feasible as you draw the illustrations." The concept model of BBX-DDR-002 showed what BreatheBox does: a window insert with two hoods, a lined housing on the sill with a counterflow core, two fans, two filters, a condensate tray and a sill bracket. Checked with build123d, it could not be built as drawn. The housing was one solid with no joints and no lid; the air paths leaked into each other; the core, both filters, both fans and the controller floated with nothing holding them; the collars, hoods and bracket had no fixings; and the bracket could not hold the unit on the sill.

The changes below keep what the unit does: the same window insert, hood mouths and their 420 mm spacing, the same housing envelope (510 x 560 x 250 mm, 110 mm on the sill), the same core, fans, filters, airflows and controls, and both fans still in the room-end plenum. Nothing here changes the pitch. Every change is in `cad/src/model.py`, which now models each component as it is made (40 components) and runs 84 constructability checks (`python cad/src/model.py --check`): parts that must touch do touch, parts that must keep a gap keep it, and no two components overlap. All 84 pass.

## Decision

*Table 1. Changes made to the model, the BOM and the calculations.*

| # | Problem in the concept | Change made | Why this way |
| --- | --- | --- | --- |
| P1 | The housing was one solid shell: no boards, no joints, and no separate lid, although the concept has a lift-off lid for filter changes. | Six pieces of 6 mm PVC foam board (base, two sides, two ends, lid), glued with PVC cement and screwed into eight 10 x 10 mm corner battens; 10 mm closed-cell foam lining glued inside between the battens. The lid is a board with a foam plug that drops inside the wall lining, held by two small toggle latches, one each side. | Butt joints in 6 mm foam board need something behind them to screw into; the battens sit inside the lining's own thickness, so the inside dimensions are unchanged. The plug locates the lid without a frame. |
| P2 | The four air paths leaked into each other: air could pass round the sides of the core from one end of the box to the other, and both dividers stopped short of the floor and the lid. | Two core frames (3 mm PVC foam board) at the ends of the core, each with a U cut 168 wide that the core's end bears on through foam gasket; three full-height dividers (3 mm board) on the centre line, two with a thin tongue that reaches through the frame's U to the core face; a foam block under the lid closes the U above the core and holds it down. | This makes four sealed chambers (supply in, supply out, exhaust in, exhaust out) with the core as the only path between them, as the concept intends. |
| P3 | Each fan sat in one open chamber with its inlet and its outlet both in it, so it would mostly stir its own air. | A 6 mm fan bulkhead across the box 94 mm in from the room face. The supply fan sits on its room side, inlet through the bulkhead, blowing up to the top grille. The exhaust fan sits on its core side, inlet through the bulkhead from the room-air chamber, blowing into the core. Both stay in the room-end plenum. | Each fan now draws from one chamber and blows into another. The exhaust side of the core still runs at the higher pressure, so the open fan-position question (O4) is unchanged. |
| P4 | The core floated 8 mm above the tray, touching only the edges of the dividers; the tray's walls were outside the core's footprint. | The tray is shortened to the core's length (300 x 200 x 14 mm) and sits between the core frames; four 20 x 20 x 12 mm pads in the tray carry the core at its corners; the lid's foam block holds it down. | Water runs freely under the core to the drain; the core lifts straight out when the lid is off (R13). |
| P5 | Both filters floated in their chambers with no seat (the supply filter 4 mm and the exhaust pad 2 mm from the lining), and the exhaust pad was exactly the size of its opening, so air could pass round both. | Filter seats from 10 x 10 mm strip: side strips, lip strips that lap 6 mm (supply) and 10 mm (pad) over the filter edges on the downstream side, and a bottom stop; foam blocks under the lid press on the top edges. The lining forms a 5 mm lip behind the supply filter's frame and a 10 mm lip behind the pad. | The airflow pushes each filter onto its lips, so the seal improves as the filter loads. Filters still slide out by hand once the lid is off (R13). The pad now works through a 200 x 170 mm window: about 1 Pa more on the exhaust side at 50 m³/h (BBX-CAL-001 v0.4). |
| P6 | The controller floated in the air above the room-end divider, with its CO2 sensor straddling the supply outlet and the room-air intake. | The controller is mounted on standoffs on the room-side divider, inside the room-air intake chamber, so its sensor reads room air as the concept says. The status light and button are on a small board behind two holes in the room face. | The sensor sees only incoming room air. The light and button position matches the appearance-model proposal of 2026-09-26, adopted on 2026-10-02 (BBX-DEC-001). |
| P7 | The room openings had no grilles or finger guards in the BOM, although the safety notes require them, and the top supply opening sat partly over the core-side chamber once the bulkhead was in. | Two perforated or slotted aluminium grilles with openings no wider than 5 mm, bolted over the openings. The supply opening is moved to 310 to 380 mm from the inside wall face and widened to 220 mm (70 x 220 mm, was 90 x 190 mm), so it is wholly over the supply fan's outlet chamber. | Fingers cannot reach a fan. The smaller supply opening adds about 0.5 Pa at 50 m³/h. |
| P8 | The collars butted the housing back and passed through the panel with no fixing, and the hoods had nothing holding them to the panel. | Each collar is a 3 mm PVC tube with a 20 mm flange on the panel's room face. Each hood is glued to a 3 mm back plate on the panel's outdoor face; four M5 bolts per side clamp flange, panel and back plate. The collar's outdoor end fits the back plate's opening; its room end slides 6 mm into the housing opening on 2 mm foam gasket and stops on the end lining. Panel cut-outs are 158 x 178 mm. | Panel, collars and hoods become one window insert, built on the bench and set in the sash track from inside. The hoods cannot fall outward. The slip joint takes up small differences between windows; the collar is cut to length at the first fit. |
| P9 | The sill bracket plate was not fixed to the housing; the tube struts ended against the plate and the foot with no joint; and the unit relied on 0.65 friction at the sill to stop it sliding into the room. | Two 50 x 4 mm aluminium rails (replacing the 390 x 400 x 4 mm plate) bolted under the housing base with two M5 bolts each. Each strut's ends are flattened and bolted with two M6 bolts to 40 x 40 x 3 mm angle cleats under the rail and on a 60 x 6 mm foot bar with a 2 mm rubber pad. The foot is lowered from 650 to 500 mm above the floor. Anti-slip rubber tape under the housing base on the sill. | Two bolts at each strut end make the bracket a rigid frame; with single bolts it would fold. The lower foot halves the sill friction needed to 0.40, a margin of about 1.5 on anti-slip tape. The rails save 1.3 kg, which keeps the unit under the 12 kg mass limit (R9). |
| P10 | The drain tube ran along the centre line through the outdoor divider, and its bore started 1 mm above the tray floor, outside the tray. | The drain leaves the tray's outdoor end wall with its bore flush with the tray floor, 40 mm to the exhaust side of the centre line, and passes through the core frame, the end wall and the panel in the exhaust-outlet chamber. | No divider is pierced and no water is left standing in the tray. The tube still falls outdoors. |
| P11 | The power cable entered the housing beside the core, in the closed space between the core frames. | An M12 cable gland in the right side wall, into the supply fan's outlet chamber, with the inline 2 A fuse there. | The cable reaches the controller and both fans through grommets in the partitions without crossing the core seal. |
| P12 | (Found in checking.) With the added partitions in 6 mm board the installed mass rose to 13.0 kg, over R9's 12 kg. | Core frames and dividers in 3 mm PVC foam board; only the bulkhead, which carries the fans, stays 6 mm. Together with P9's rails, the installed mass is 11.4 kg. | Keeps R9 met on paper without changing any part that carries load. |

*Table 2. Knock-on changes.*

| Item | Change | Reason |
| --- | --- | --- |
| Mass | Installed unit 11.4 kg (was 10.5 kg), 0.6 kg under R9's 12 kg; 11.7 kg with the adapter. | Partitions, seats, grilles, latches, back plates, flanges, cleats and bolts; offset in part by the rails (P9) and 3 mm partitions (P12). |
| Stability | The parts carried by the sill and bracket weigh 8.6 kg with their centre of mass 162 mm into the room. The foot pushes on the wall with about 34 N; the sill needs 0.40 friction (0.65 with the concept's foot at 650 mm). Each strut's top joint carries about 6.5 N·m: 17 MPa in the tube and about 324 N on each M6 bolt. | P9. |
| Pressure and power | Exhaust stream +1.1 Pa and supply stream +0.5 Pa at 50 m³/h. Fans and controls 5.7 W clean, 7.5 W with loaded filters at 50 m³/h (was 5.6 and 7.4 W); 14.8 W at 70 m³/h loaded (was 14.5 W). Night mode 30.2 dB(A) clean (was 30.1). R1, R3, R6 and R10 status unchanged. | P5, P7. |
| Cost | BOM lines 1, 8, 9, 10, 11 and 13 respecified; lines 1, 10, 11 and 13 repriced. Parts $283.00 against the $255 value-engineering target (`budget_usd`): **R15 is over the target by $28**. See Table 3, A1. | Parts the concept needed but did not list. |
| Drawing | BBX-DWG-001 Rev P3; making sketches BBX-DWG-101 to 114 added. | Follows the model. |
| Documents | BBX-CAL-001 v0.4, BBX-REQ-001 v0.6, BBX-PRC-001 v0.6: mass, stability, pressure, power and cost figures; R15 status within the value-engineering target to over it by $28. | Follows the model. |

*Table 3. Items that change the safety case or note value engineering: proposed, then decided by Amish on 2026-10-02 (A2 and A3).*

| # | Question | Options | Recommendation |
| --- | --- | --- | --- |
| A1 | Value engineering (a note, not a decision). The constructable design costs $283.00 against the $255 value-engineering target, $28 over. | (a) look for $28 of savings (for example 3D-printed grilles and a cheaper core), which may cost performance; (b) accept the estimate as the cost of building and guarding the unit. | (b), with (a) pursued where performance allows; the added parts are all needed. |
| A2 | Only friction at the sill stops the unit sliding into the room (margin about 1.5 on anti-slip tape). If it slid, it would tip off the sill into the room. | (a) accept, with a 50 N push test at the trial window (TRL 4); (b) lower the foot to 400 mm (margin about 1.9, longer struts); (c) add a positive restraint, such as a strap or a clamp to the window board, which may need drilling and conflict with R9. | (a), moving to (b) if the push test fails. **Decided 2026-10-02: (b)**, the foot at 400 mm for the first prototype, with the 50 N push test at the trial window; back to 500 mm only where a radiator or skirting blocks the lower foot and the push test passes on that sill. |
| A3 | Sash lock (R12). The concept says the raised sash locks onto the insert panel, but no part does this: the window's own catch no longer meets once the lower sash is raised. | (a) a bought no-drill sash jammer or adjustable bar wedged in the inner track above the raised sash (about $10, which adds to the estimate in A1); (b) screw-fixed sash stops, which need drilling (R9). | (a). **Decided 2026-10-02: (a)**; the jammer is bill of materials line 14 ($10.00). |

## Consequences

- `design_state: constructable` in `project.yaml`. The build plan BBX-BLD-001 shows every component and step in pictures generated from the model (`cad/src/build_plan_media.py`); the design decisions register BBX-DEC-001 records the decisions.
- Requirement status (BBX-CAL-001 v0.4): met 10, not met 1 (R6 noise at 50 m³/h, unchanged), over the value-engineering target 1 (R15 cost, new), not verifiable at TRL 3 3 (R9 install time, R13, R14). R9's mass part is met on paper at 11.4 kg.
- The appearance model `cad/src/product_model.py` was updated to the constructable design on 2026-10-02 (top-board lid with two toggle latches, bulkhead and fan positions, grilles, controls, collars and hood back plates, rails, struts and the 400 mm foot, sash jammer), and its render scenes exported. The photoreal renders (`media/render-*.png`), `media/card.png` and `media/social-preview.png` still show the concept until they are rendered again on Amish's Mac, where Blender is.
- The core's port arrangement, the blowers' inlet and mounting, and the trial window's sill, stop bead and wall below are to be confirmed when parts are bought (BBX-DEC-001).
- With A2 decided as option (b), the wall foot of the first prototype moved from 500 to 400 mm on 2026-10-02: struts 621 mm cut (595 mm between end holes, 55°), sill friction needed 0.32 (margin 1.9), strut top joint 6.6 N·m, 18 MPa, 329 N per M6 bolt (BBX-CAL-001 v0.7, BBX-DWG-001 Rev P4, BBX-DWG-111 to 113 Rev P2, BBX-BLD-001 v0.2). With A3 decided, the no-drill sash jammer is bill of materials line 14 and is in the model and build plan step 15. Value-engineering target: USD 255. Estimated cost of the constructable design: USD 294 (USD 39 over the target). Installed mass 11.8 kg with the sash jammer.

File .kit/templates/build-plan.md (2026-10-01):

---
doc_id: PRJ-BLD-001
title: Project prototype build plan
project: Project name
doc_type: Build plan
version: "0.1"
status: Draft
date: YYYY-MM-DD
author: Amish Chadha
license: CERN-OHL-S-2.0
revisions:
  - version: "0.1"
    date: YYYY-MM-DD
    author: Amish Chadha
    change: First build plan; design made constructable
---

# Project prototype build plan

**Plan, not yet built.** How to build the first proof-of-concept prototype, component by component. Building and testing to it is TRL 4 work. Decisions still to be made are kept in the design decisions register (`docs/06-design-decisions.md`), not here.

## 1. What you are building

Every component, pulled apart and numbered in build order

One short paragraph: what the prototype is, how many components, which are made and which are bought, and the main ways they are made.

## 2. What changed to make it buildable

| Component | The concept had | The buildable design has | Why |
| --- | --- | --- | --- |

## 3. Making the components

### 3.1 Component name

Making sketch

**What it is and what it is made from.**

**How to make it.**

1. Mark out ...
2. Cut ...

**How it fits the parts next to it.**

Close-up of the joint

**Check before moving on.**

## 4. Putting it together

### Step 1: ...

Step 1

## 5. First checks

| Check | Requirement | How | Pass when |
| --- | --- | --- | --- |

## 6. Safety stops

## 7. Tools, skills and workspace

## 8. Where the numbers come from

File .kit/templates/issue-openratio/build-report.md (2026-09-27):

---
name: Build report
about: Tell us what happened when you built, printed or tested part of this design
title: "Build report: "
labels: build-report
---

This is a research and educational prototype, not a medical device. It is a TRL 3 concept and is not released for fabrication. If you build any part of it, you do so at your own risk. Reports help everyone.

**What you built** (part, sub-assembly or test)

**Materials, tools and settings**

**What worked**

**What did not work, with photos or measurements if you have them**

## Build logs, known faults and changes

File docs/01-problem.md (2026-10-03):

---
doc_id: BBX-PRB-001
title: BreatheBox problem statement
project: BreatheBox
doc_type: Problem statement
version: "0.9"
status: Draft
date: '2026-10-02'
author: Amish Chadha
license: CERN-OHL-S-2.0
revisions:
- version: "0.1"
  date: '2026-09-25'
  author: Amish Chadha
  change: Initial scaffold
- version: "0.2"
  date: '2026-09-25'
  author: Amish Chadha
  change: Populate to TRL 2 (users, context, constraints, prior work, open questions)
- version: "0.3"
  date: '2026-09-25'
  author: Amish Chadha
  change: TRL 3 update; sash-first window type and budget position per BBX-DDR-001 (adopted for TRL 3, open for Amish's review); open questions updated
- version: "0.4"
  date: '2026-09-25'
  author: Amish Chadha
  change: Recommendations accepted by Amish (DDR-002)
- version: "0.5"
  date: '2026-09-26'
  author: Amish Chadha
  change: Budget approved by Amish; constraint now $255
- version: "0.6"
  date: '2026-09-30'
  author: Amish Chadha
  change: Priced BOM of the constructable design ($283, BBX-DDR-003) noted against the $255 constraint
- version: "0.7"
  date: '2026-10-01'
  author: Amish Chadha
  change: BioMedical area (BBX-DEC-001 v0.3); out of scope states a research and educational prototype, not a medical device
- version: "0.8"
  date: '2026-10-02'
  author: Amish Chadha
  change: "Sash lock and first co-design partner decided by Amish on 2026-10-02; ACORN Canada named as the first candidate to approach (BBX-DEC-001)"
- version: "0.9"
  date: '2026-10-02'
  author: Amish Chadha
  change: "Cost constraint restated against the value-engineering target with the sash jammer and longer struts (USD 294)"
---

# BreatheBox problem statement

Most homes have no mechanical ventilation, so the people in them choose between stale, damp air and an open window that throws away heat or cooling. Whole-house heat recovery ventilators solve this in new, airtight buildings, but they need ducts through ceilings and walls, which renters cannot install and owners of older homes rarely pay for. There is no open, low-cost, renter-installable way to ventilate one room with heat recovery.

## Why it matters

People spend most of their lives indoors. The US Environmental Protection Agency notes that Americans spend about 90 % of their time indoors and that indoor concentrations of some pollutants are often 2 to 5 times higher than typical outdoor levels ([US EPA, Report on the Environment: Indoor Air Quality](https://www.epa.gov/report-environment/indoor-air-quality)). Bedrooms are the worst case: two people sleep for eight hours behind a closed door and a closed window.

Energy is the other half of the problem. In the European Union, buildings use about 40 % of energy, about 80 % of the energy used in homes goes to heating, cooling and hot water, and 85 % of buildings were built before 2000 ([European Commission, Energy Performance of Buildings Directive](https://energy.ec.europa.eu/topics/energy-efficiency/energy-performance-buildings/energy-performance-buildings-directive_en)). As these homes are sealed and insulated, air leakage falls and moisture and CO2 build up unless ventilation is added. In England, 7 % of social rented homes had a damp problem in 2023, and the death of two-year-old Awaab Ishak in 2020 after prolonged exposure to mould led to a law that sets deadlines for landlords to fix damp and mould hazards ([UK Government, Awaab's Law](https://www.gov.uk/government/news/awaabs-law-to-force-landlords-to-fix-dangerous-homes)).

Outdoor air is not always clean either. The World Health Organization reports that 99 % of the world's population lived in places where its air quality guideline levels were not met in 2019 ([WHO, Ambient air quality and health](https://www.who.int/news-room/fact-sheets/detail/ambient-(outdoor)-air-quality-and-health)). An open window brings that air in unfiltered; a ventilator can filter it.

## Users and context

| User | Situation | What they need |
| --- | --- | --- |
| Renters in older flats and houses | Cannot drill, duct or change the building; often have one problem room (a bedroom or a small flat's main room) | A unit that goes into an existing window and comes out again without damage |
| Owners of older, poorly ventilated homes | Condensation and mould on cold walls; high heating bills; no budget for a whole-house system | Continuous fresh air to one or two rooms at low running cost |
| Households in polluted cities | Windows kept shut against traffic or smoke; stuffy bedrooms | Filtered supply air and a visible CO2 reading |
| Social housing providers and energy retrofit programs | Must fix damp and mould quickly across many homes | A low-cost, repeatable, documented measure that installs in minutes |
| Makers and community repair groups | Want to build, adapt and fix the unit locally | Open drawings, common parts and no special tools |

**Operating context.** One room of 20 to 40 m³ (for example, a 3 x 4 m bedroom with a 2.5 m ceiling holds 30 m³), one or two occupants, a window with a sill 800 to 1,000 mm above the floor, and a standard wall socket nearby. Outdoor air from about -10 °C to 35 °C. The first target window is the vertical sliding sash (single- or double-hung) common in North America and the United Kingdom, because the lower sash can close down onto an insert panel. This sash-first choice was decided by Amish on 2026-09-25 (BBX-DDR-001 item A2; BBX-DDR-002).

## Constraints

- Garage-buildable prototype, $255 USD in parts (`project.yaml`; raised from $220 to $250 by Amish on 2026-09-25 and to $255 on 2026-09-26, BBX-DDR-002). The $255 is a value-engineering target, not a spending limit. Value-engineering target: USD 255. Estimated cost of the constructable design: USD 294 (USD 39 over the target), including the sash jammer decided on 2026-10-02 (BBX-CAL-001 v0.7, BBX-DDR-003).
- No drilling of the window frame or wall; installs and removes without damage, so renters can use it.
- Low voltage only inside the unit (24 V SELV from a certified plug-in adapter); no mains wiring by the builder.
- Common, replaceable parts: standard fans, filter media cut to size, a spare-part HRV core.
- Quiet enough for a bedroom at night.
- Open licenses: CERN-OHL-S-2.0 for hardware, MIT for firmware and scripts.

## Out of scope

- Whole-house ventilation, ducted systems and replacement of building code ventilation.
- Heating or cooling the room (the unit recovers heat; it does not add it beyond fan heat).
- Kitchen and bathroom extraction, which need higher extract rates, and removal of combustion products from stoves or open-flued appliances.
- Medical or health claims. BreatheBox is a research and educational prototype, not a medical device. The CO2 display is an indicator of ventilation, not a health measurement.

## Prior work

- **Decentralized single-room ventilators.** Commercial through-wall units exist, for example the LUNOS e² family of small decentralized fans with heat recovery ([LUNOS, heat recovery products](https://www.lunos.de/en/heat-recovery)). The LUNOS page, checked on 2026-09-25, describes the e² as one of the smallest decentralized fans but does not state how it is installed. Through-wall units of this kind need an opening in the wall, which renters generally cannot make.
- **Plate heat exchangers.** Fixed-plate exchangers reach 70 to 90 % sensible efficiency at low pressure drop, but have a high chance of frosting in cold climates ([Wikipedia, Heat recovery ventilation](https://en.wikipedia.org/wiki/Heat_recovery_ventilation)). BreatheBox uses a plate counterflow core and needs a frost strategy.
- **Window air conditioners and window fans** show that a sash window with a filler panel is a familiar, renter-friendly mounting. They move air or heat but do not recover heat from exhaust air.
- **CO2 as a ventilation indicator.** Health Canada's residential guideline sets a long-term exposure limit of 1,000 ppm CO2 (24-hour average) and notes that ventilation is the primary means of removing CO2 indoors ([Health Canada, Residential indoor air quality guidelines: carbon dioxide](https://www.canada.ca/en/health-canada/services/publications/healthy-living/residential-indoor-air-quality-guidelines-carbon-dioxide.html)).

We have not found an open-source, window-mounted, counterflow heat recovery ventilator with published design files. This is a finding from a limited search and should be checked at TRL 3.

## Open questions

- [ ] Which windows dominate in the first user group? The first version targets sash windows (BBX-DDR-001 item A2); casement and tilt-and-turn windows (common in continental Europe) need a later insert.
- [x] Is a 260 mm raised sash acceptable for security, or is a locking bar needed as standard? Decided 2026-10-02: a bought no-drill sash jammer or adjustable security bar in the inner track is part of the kit (BBX-DEC-001).
- [ ] What noise level do users accept at night, and at what airflow? BBX-CAL-001 estimates about 39 dB(A) at 1 m at 50 m³/h and 30 dB(A) only near 32 m³/h, A quiet night mode at 32 m³/h (about 30 dB(A), BBX-DDR-002) is now part of the design, so the open part is whether users accept it and its overnight CO2 of about 1,300 ppm.
- [ ] How cold does it get where the first users live, and how often will the frost strategy run?
- [x] Who are the first co-design partners (a tenants' group, a social landlord or a retrofit program)? Decided 2026-10-02: Canada first, with a tenant organization in a city with older double-hung rental stock and cold winters. The first candidate to approach is ACORN Canada in Toronto, with ACORN in the United Kingdom as the alternative; nothing is agreed with either (BBX-DEC-001).

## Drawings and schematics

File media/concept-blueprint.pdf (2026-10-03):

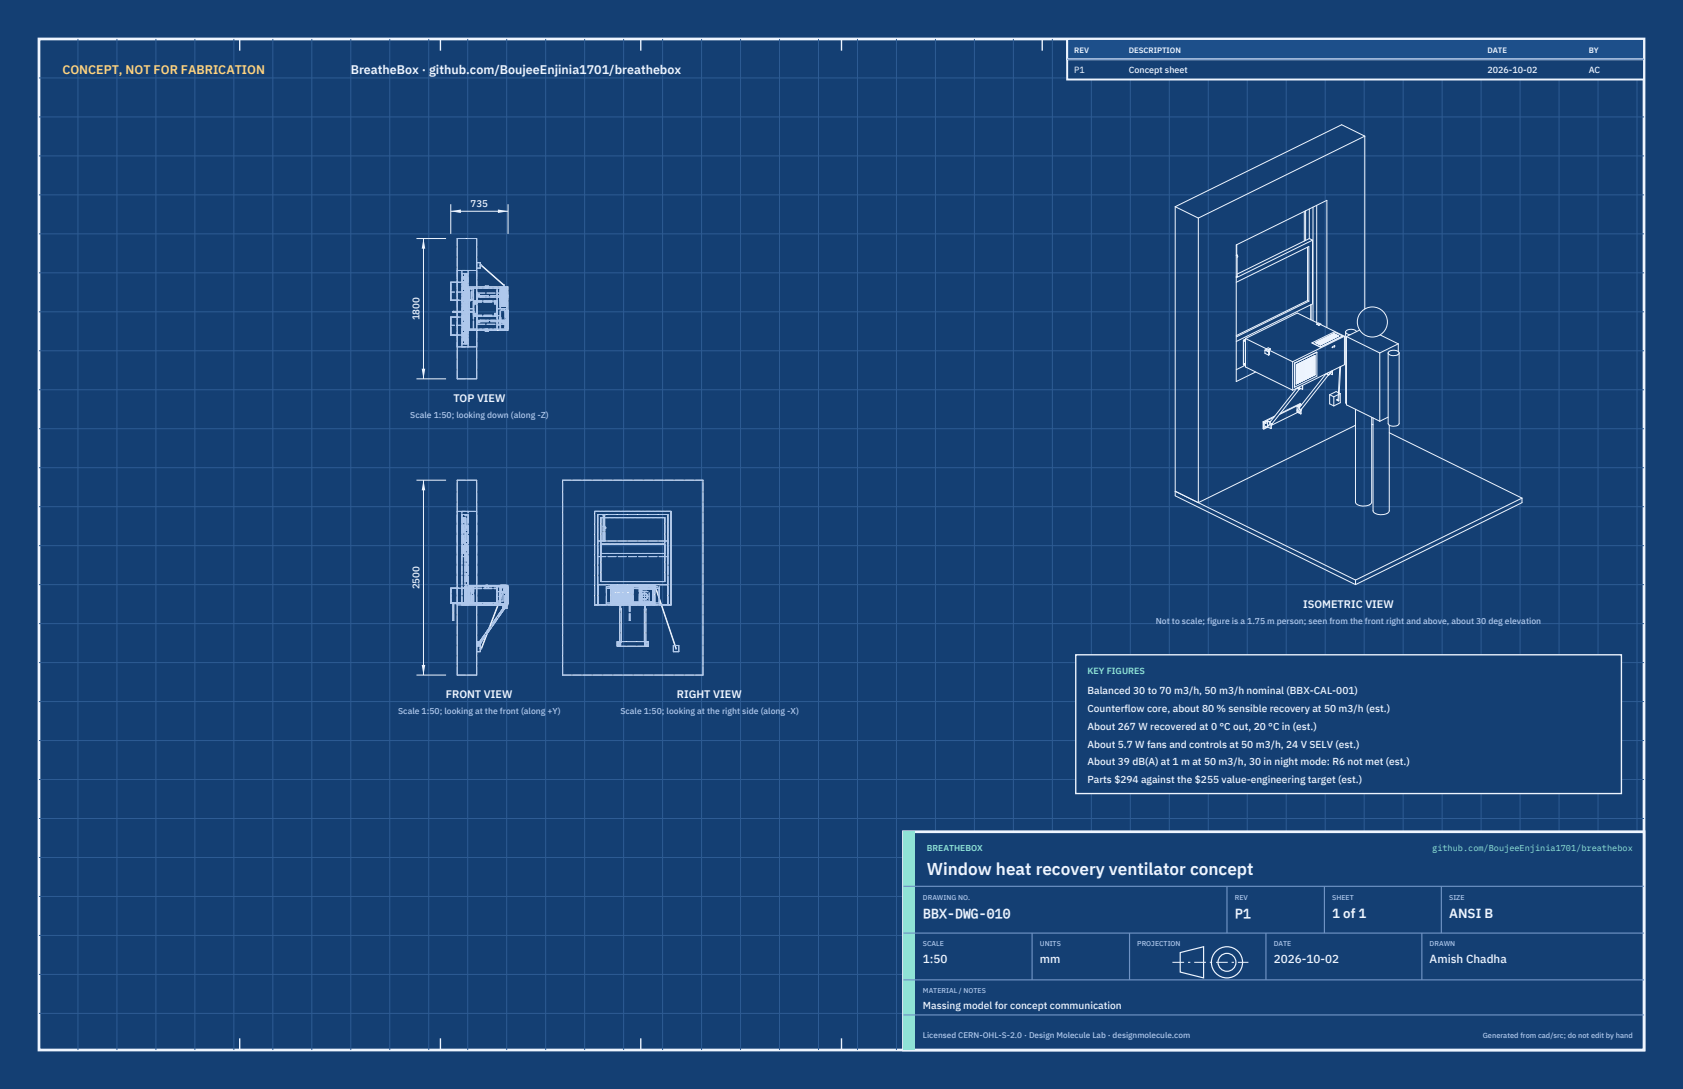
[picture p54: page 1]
CONCEPT, NOT FOR FABRICATION; BreatheBox · github.com/BoujeeEnjinia1701/breathebox; FRONT VIEW; TOP VIEW; RIGHT VIEW; ISOMETRIC VIEW; REV; DESCRIPTION; DATE; Concept sheet; BREATHEBOX; github.com/BoujeeEnjinia1701/breathebox; DRAWING NO. BBX-DWG-010; REV P1; SHEET 1 of 1; SIZE ANSI B; SCALE 1:50; UNITS mm; PROJECTION; DRAWN Amish Chadha; Licensed CERN-OHL-S-2.0 · Design Molecule Lab · designmolecule.com; Generated from cad/src; do not edit by hand

Scale 1:50; looking down (along -Z)

Not to scale; figure is a 1.75 m person; seen from the front right and above, about 30 deg elevation

KEY FIGURES
Balanced 30 to 70 m3/h, 50 m3/h nominal (BBX-CAL-001)
Counterflow core, about 80 % sensible recovery at 50 m3/h (est.)
About 267 W recovered at 0 °C out, 20 °C in (est.)
About 5.7 W fans and controls at 50 m3/h, 24 V SELV (est.)
About 39 dB(A) at 1 m at 50 m3/h, 30 in night mode: R6 not met (est.)
Parts $294 against the $255 value-engineering target (est.)

Scale 1:50; looking at the front (along +Y)

Scale 1:50; looking at the right side (along -X)

Window heat recovery ventilator concept

MATERIAL / NOTES
Massing model for concept communication

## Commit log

2026-09-25 Initial scaffold: standard open hardware layout, CERN-OHL-S v2 + MIT licenses
    Claude-Session: https://claude.ai/code/session_01XuhhSU4W6fYhgCfURbrkut
    [bom.csv]
2026-09-26 Populate to TRL 2: problem, requirements, precis, concept media, BOM and README use cases
    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
    [bom.csv]
2026-09-26 Advance to TRL 3: DDR-001, CAL-001 sizing, parametric model with STEP/STL, GA drawing, priced BOM; TRL 4 on hold
    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
    [bom.csv, breathebox-assembly.step, breathebox-assembly.stl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]
2026-09-26 Accept all recommendations (DDR-002), switch footer to designmolecule.com, add README write-up with new inspiration point
    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
    [breathebox-assembly.step, breathebox-core.step, breathebox-hoods.step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]
2026-09-26 Strengthen sources, apply approved budgets, add CITATION.cff and CONTRIBUTORS.md with credits
    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
    [results.csv]
2026-09-27 Product appearance model and photoreal renders
    Adds cad/src/product_model.py (appearance model for renders only, all main
    dimensions from model.py) and Blender renders in media/render-*.png,
    captioned with the project, repository and viewing direction. README leads
    with the product render; trl stays 3.
    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
2026-10-01 Image quality pass: legible exploded views, flow diagrams and drawing sheets
    Kit 1.6.1 image layout: the parts list sits in its own column, number bubbles sit on visible parts and never overlap, small parts get a leader, pictures are cropped to the subject, flow labels keep numbers with their units, and sheet captions and the revision table no longer overprint. Concept images, blueprint and general arrangement sheet regenerated; repo-specific labels moved clear of other text and lines.
2026-10-01 Kit 1.7.0: constructable design, illustrated build plan and design decisions register
    The design is now constructable: every part can be made and fits its neighbours, with each change recorded in a Design for construction decision record (made under Amish's 2026-09-30 instruction; ope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
    [bom.csv, breathebox-assembly.step, breathebox-assembly.stl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]
2026-10-01 Budget treated as a value-engineering target
    Amish, 2026-10-01: the budget is a hypothetical control target that keeps the design on a value-engineering lens, not a spending limit. Documents now state the value-engineering target and the estima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
2026-10-01 Record Amish's 2026-10-01 decisions
    GrowRider and GravitySort: Amish accepted the recommendations in the design decisions register ("i agree with your recommendations for both GrowRider and GravitySort"). Accepted items, including the 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
2026-10-01 PicoFlow full-bore valve, GravitySort bump stop, BioMedical cards
    PicoFlow: Amish accepted the full-bore inlet valve ("picoflow - i agree with the recommendation", 2026-10-01); the 125 mm full-bore gate valve replaces the 90 mm valve and its reducer and expander, output 85.6 W at 10 L/s (5.6 W over R3); model, calculations, build plan, pictures, register and PDFs updated. GravitySort: the accepted adjustable rubber bump stop is now in the model, drawings, build plan pictures and documents ("gravitysort - update the documentation, CAD work and picture renderings"). BreatheBox and DustBadge: social preview cards regenerated with the BioMedical area.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
2026-10-02 Record Amish's approval of the open-decision recommendations
    Amish approved the recommendation on every open decision in the design decisions register ("i approve your recommendations for all 555 open decisions.", 2026-10-02). Each decision is moved to Decisio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
2026-10-03 Carry approved follow-ups into the design and redo photoreal renders
    Amish approved the follow-up actions from the open-decision sign-off ("APPROVED CHANGES, COMPLETE THESE", 2026-10-02), the design-for-construction change tables in ten repos, the last wave's open dec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
    [bom.csv, breathebox-assembly.step, breathebox-assembly.stl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]

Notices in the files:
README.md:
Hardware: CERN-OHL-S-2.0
